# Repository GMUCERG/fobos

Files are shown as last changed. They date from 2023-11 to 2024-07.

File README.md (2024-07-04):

FOBOS
=====

Flexible Open-source workBench fOr Side-channel analysis (FOBOS) is an "acquisition to analysis" solution which includes all necessary software to control the device under test (attack) (DUT), trigger the oscilloscope, obtain the measurements and analyze them using several power analysis techniques.

FOBOS splits the Side Channel Analysis (SCA) setup into a control board, a DUT, and the SCA workstation. The firmware for the control board can be found in the folder `control`. The hardware description language files required to adapt a cryptographic algorithm to a particular FOBOS DUT are in the folder `DUT`. The `hardware` folder on the other hand contains circuit board design files for FOBOS boards such as the FOBOS Shield and several FOBOS DUTs. The `software` folder contains the scripts to run FOBOS. These python scripts run partially on the SCA workstation within a Jupyter notebook and partially on the Pynq DUT. The `docs` folder contains the FOBOS documentation.

Please cite as: 
```bibtex
@inproceedings{fobos3,
author = {Ferrufino, Eduardo and Beckwith, Luke and Abdulgadir, Abubakr and Kaps, Jens-Peter},
title = {{FOBOS} 3: An Open-Source Platform for Side-Channel Analysis and Benchmarking},
year = {2023},
isbn = {9798400702624},
publisher = {Association for Computing Machinery},
address = {New York, NY, USA},
url = {https://doi.org/10.1145/3605769.3623987},
doi = {10.1145/3605769.3623987},
pages = {5--14},
keywords = {hardware security, lightweight cryptography, side-channel analysis, benchmarking},
location = {, Copenhagen, Denmark, },
series = {ASHES '23}
}
```

FOBOS Control Board
-------------------
* `control`
   VHDL sources for configuring the FOBOS Control Boards. Requires Xilinx Vivado 2022.1.
   * `pynqctrl`
     Using a Digilent Inc PYNQ-Z1 or TUL PYNQ-Z2 as control board and either the FOBOS Shield or an oscilloscope for measurements.
   * `ip-repo` 
     Modules used by either control board.

FOBOS DUT
---------
* `dut`
  VHDL sources for FOBOS wrapper and pin assignments to prepare a DUT for instantiating a target algorithm.
  * `fpga_wrapper`
    Source code of the FOBOS wrapper common to all FPGA targets and the constraint files for the supported DUTs.
  * `example_cores`
    Contains implementations of example algorithms required for the tutorials.
 
FOBOS Hardware
--------------
* `hardware`
  Printed Circuit Board design files for FOBOS boards. Requires KiCad.
  * `fobos-shield`
    FOBOS Shield is a data aqcuisition and benchmarking boad that can be attached to the PYNQ-Z1 board.
  * `fobos-shield-Z2`
    FOBOS Shield is a data aqcuisition and benchmarking boad that can be attached to the PYNQ-Z2 board.
  * `fobos-mtc`
    FOBOS Multi Target Connector allows simple connection of DUT boards with PMOD connectors to the FOBOS Shield.
  * `fobos-dut`
    Contains folders for each FOBOS DUT.

FOBOS Software
--------------
* `software`
  FOBOS is controlled by a series of Python 3 scripts. 

  * `foboslib` contains all common FOBOS functions.
  * `notebooks` contains Jupyter notebooks that run within Jupyter Lab on the SCA workstation.
  * `lwc_tools` contains tools to make the GMU LWC Hardware API compatible with FOBOS.
  * `firmware` contains software that runs on FOBOS Control.

Documentation
-------------

* `docs` 
  Contains the sources for the Sphinx based documentation of FOBOS and the makefile to compile it.
  You can also read it at https://cryptography.gmu.edu/documentation/fobos3/index.html
  
License
-------

Copyright 2024 Cryptographic Engineering Research Group (CERG)

Licensed under the Apache License, Version 2.0 (the "License");
you may not use this file except in compliance with the License.
You may obtain a copy of the License at

    http://www.apache.org/licenses/LICENSE-2.0

Unless required by applicable law or agreed to in writing, software
distributed under the License is distributed on an "AS IS" BASIS,
WITHOUT WARRANTIES OR CONDITIONS OF ANY KIND, either express or implied.
See the License for the specific language governing permissions and
limitations under the License.

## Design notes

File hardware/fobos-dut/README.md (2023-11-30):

FOBOS-DUT Boards
=========
  * `dut-artix7-a12t-cpg238`
    FOBOS FBD-A7 DUT with a Xilinx Artix-7 xc7a12tcpg238 device and power measurement circuitry.

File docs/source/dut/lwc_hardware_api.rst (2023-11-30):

.. _dut_fbd-a7-label:

==========================
FOBOS FBD-A7 (Artix7 FPGA)
==========================

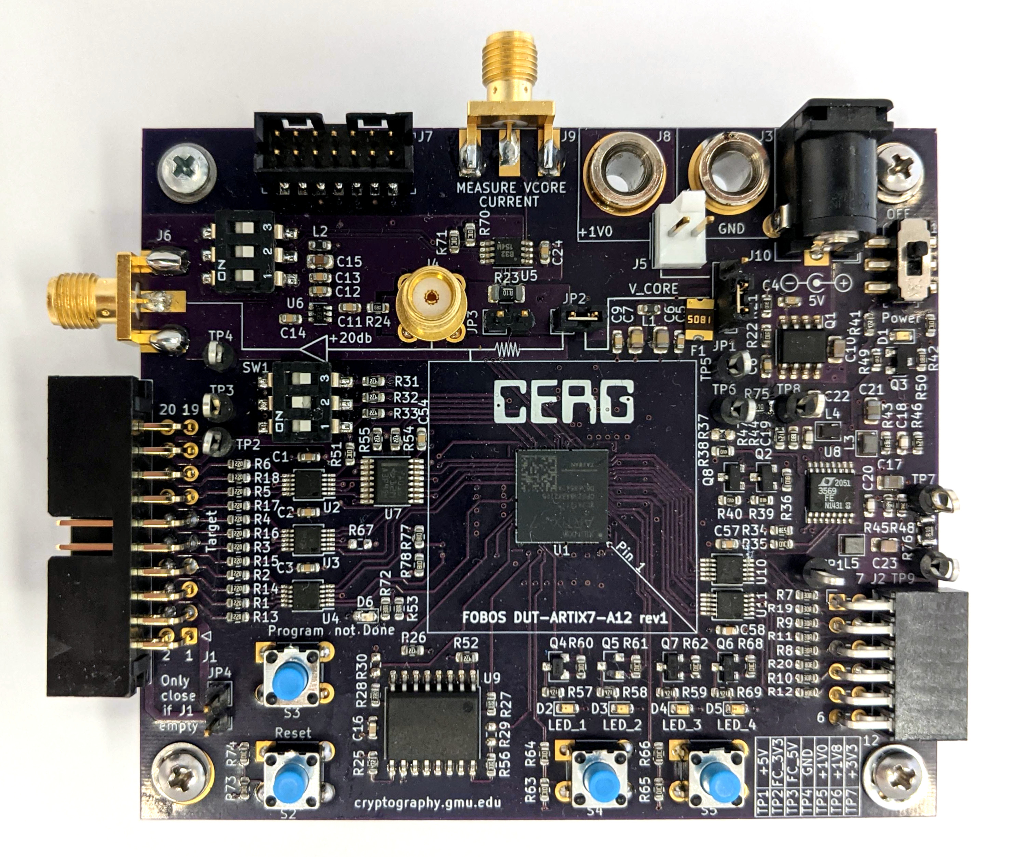
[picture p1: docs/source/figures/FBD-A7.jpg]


   FOBOS FBD-A7 DUT with Xilinx Artix-7-A12 FPGA

Connection to FOBOS Shield control board
----------------------------------------

When using the FOBOS Shield, simply connect the 20pin ribbon cable to the target connector of the FOBOS Shield and the FBD-A7. 
Connect the SMA connector J6 of the FBD-A7 to the Measure connector J10 on the FOBOS Shield or to an oscilloscope for measuring changes in power consumption for SCA measurement.

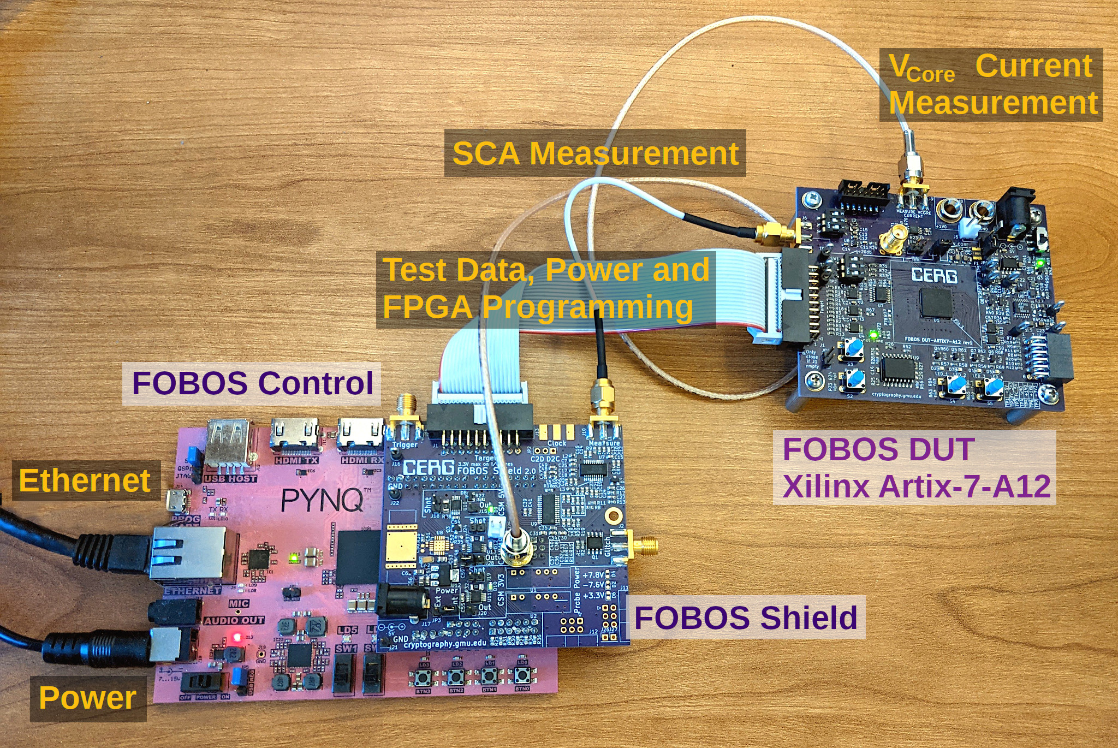
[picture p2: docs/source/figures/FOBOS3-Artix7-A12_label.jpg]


   FODOS 3 Setup with Artix7-A12 DUT

Make sure to set the DUT to FOBOS and DUT interface to INTERFACE_4BIT in your Jupyter notebook using the following commands.
This configures the FOBOS Control to DUT communication.

.. code-block:: py

    ctrl.setDUT(FOBOSCtrl.FOBOS)
    ctrl.setDUTInterface(FOBOSCtrl.INTERFACE_4BIT) 

When compiling the FOBOS wrapper, choose **fbd-a7.xdc** as the constraint file.

Programming the FBD-A7 DUT
--------------------------

The DUT can only be programmed through the JTAG interface as of now. 
Programming the DUT directly from FOBOS Control or from the SPI flash are still being developed.

..
    You can program the DUT using the following commands in your Jupyter notebook:

    .. code-block:: py

        from foboslib.dut import fbd-a7 as DUT
        dut = DUT.DUT()
        dut.setBitFile("crypto.bit")
        dut.program()

Power Measurement
-----------------

To measure the power consumption, connect an SMA cable to the *Measure VCore Current* output J9 of the FBD-A7 and the CMS VAR alternate input J23 on the FOBOS Shield. Make sure that the jumper J28 on FOBOS Shield is pulled, see :numref:`fig_power_circuit`.

.. _fig_FBD-A7_power:
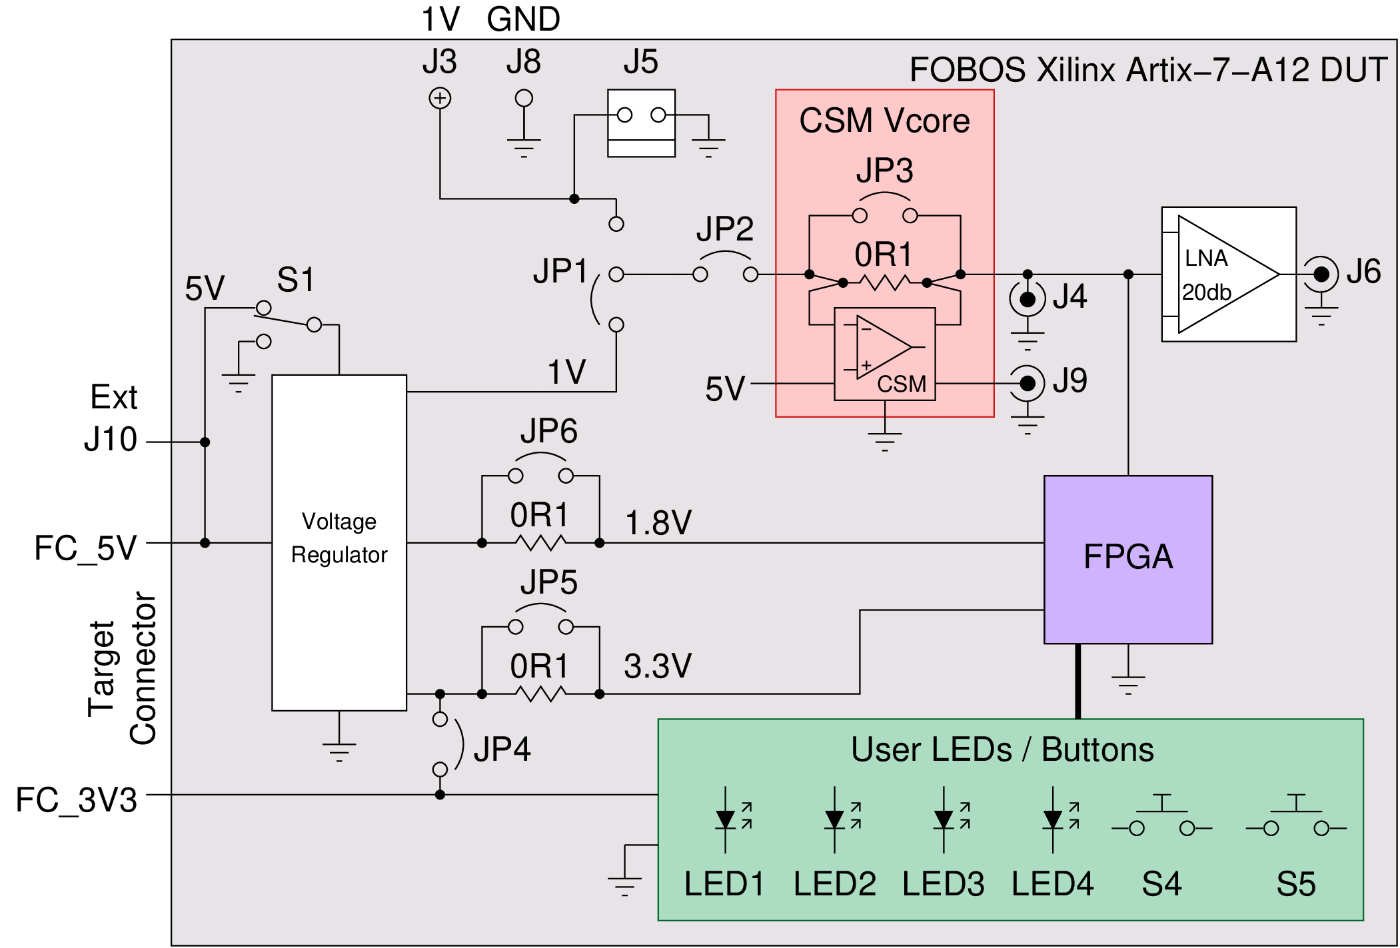
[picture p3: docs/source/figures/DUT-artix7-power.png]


   FBD-A7 Power Block Diagram

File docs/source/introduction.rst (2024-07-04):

Introduction
************
The Flexible Opensource workBench fOr Sidechannel analysis (FOBOS) 
loosely named after the Greek god Phobos (Φóβος), is an "acquisition to analysis" 
solution which includes all necessary software to control the Device Under Test (DUT), 
obtain the measurements and analyze them using several power analysis techniques. 
FOBOS mainly targets FPGAs as DUTs. 
The system is targeted for educational and research purposes.



   FODOS 3 Setup with Artix7-A12 DUT

FOBOS Overview
==============
The main components of the FOBOS 3 platform are as follows:

1. The *SCA Workstation* hosts capture and analysis scripts using a 
   JupyterLab installation. All scripts are written in Python and are 
   commented and easy to modify. In typical system usage, the user runs capture 
   scripts that send test vectors (e.g., key and plaintext) one at a time to 
   the connected control board and receives the results (e.g., ciphertext) 
   and power traces. Analysis scripts can be run on the saved results and traces 
   or optionally executed simultaneously with trace collection.
2. The *control board* receives a test vector from the SCA workstation and forwards 
   it to the DUT. The control board asserts a trigger signal as
   soon as the target board starts operating on the test vector (i.e., running
   the cryptographic function). This signal can trigger an external oscilloscope
   or the internal ADC hosted on the FOBOS Shield. The control board also generates 
   the target clock. The internal ADC can sample changes in the power consumption 
   of the target board at a maximum rate of 100 M Sample/sec. The sampling clock and the target
   clocks are synchronized to achieve high-precision measurements.
3. The *DUT* hosts the cryptographic function that is being evaluated.
   The DUT board is designed (or modified) to allow measurement of the power
   consumption using a shunt resistor or a current probe. We tested the platform 
   using a modified Digilent Nexys 3 board featuring a Xilinx Spartan-6
   FPGA, the NewAE CW305 Artix-7 target board, and our upcoming FOBOS Artix-7-based DUT.

Feature Overview
================

- Runs cryptographic implementations on FPGAs and measures power consumption.
- Provides a simple wrapper for FPGA implementations of cryptographic algorithms 
  according to the CAESAR and LWC Hardware APIs.
- Separate control and DUT boards allowing easy addition of new DUTs.
- Uses commercial over-the-shelf boards when possible to reduce cost.
- Digilent Pynq-Z1 and TUL Pynq-Z2 control boards.
- DUT support includes Digilent Nexys3 board (Xilinx Spartan6), FOBOS FBD-A7 and NewAE CW305
  (Xilinx Artix7 boards).
- Adjustable DUT clock.
- DUT clock synchronized with ADC clock.
- Adjustable trigger signal.
- Supports fast USB3-based oscilloscopes (Picoscope).
- Software to perform Correlation Power Analysis (CPA).
- Leakage assessment using t-test. 

Changelog
=========

**Version 3.0.1**

- Substantial documentation updates and improvements
- Power calibration works again (was working on beta versions of FOBOS 3)
- MTDs of each key byte are now written into a file, they don't have to be guessed from graphs anymore
- Updated fobosTVGen to handle more FIFOs
- XILINX_XRT environment variable on Pynq was not set correctly
- Pynq install script now detects which Pynq board it is running on
- FOBOS can now set fixed amplification on the amplifier of the FOBOS Shield using ADC_hilo
- Improved Makefile for building the Pynq overlay for Pynq-Z1 and Pynq-Z2, and different revisions of the FOBOS Shield

**Version 3**

- Completely new version of FOBOS with major changes
- FOBOS Shield which provides 100 MS/s ADC for SCA measurements and current sense monitors
  for power consumption measurements. This removes the need for an oscilloscope and 
  enables benchmarking of power and energy consumption of the DUT.
- Digilent Pynq-Z1 and TUL Pynq-Z2 control boards provide fast data aquisition and communication with the 
  DUT through 1G Ethernet interface.
- JupyterLab front end to control FOBOS. This also enables remote access.

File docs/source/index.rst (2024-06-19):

.. FOBOS documentation master file, created by
   sphinx-quickstart on Fri Aug 30 16:09:53 2019.
   You can adapt this file completely to your liking, but it should at least
   contain the root `toctree` directive.

Flexible Opensource workBench fOr Side-channel analysis (FOBOS)
***************************************************************

The Flexible Opensource workBench fOr Side-channel analysis FOBOS is a platform to perform side-channel analysis (SCA).
FOBOS uses commercially avilable boards when possible to reduce the cost of building a working SCA setup.
Using FOBOS, power traces can be collected and attacks like Correlation Power Analysis (CPA) can be mounted.
Also, scripts to perform leakage assesment are included.

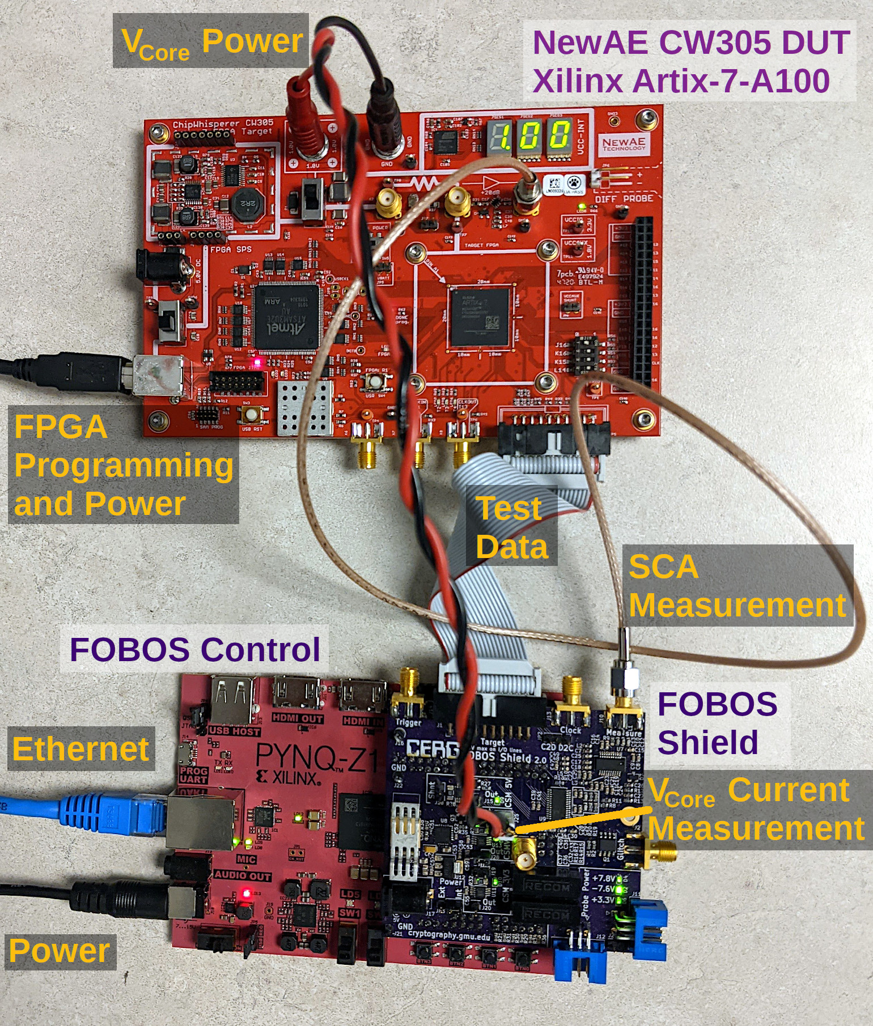
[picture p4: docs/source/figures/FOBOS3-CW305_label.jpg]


   FOBOS 3 Setup with NewAE CW305 DUT

Features
========

- Runs cryptographic implementations on FPGAs and measures power consumption.
- Provides a simple wrapper for FPGA implementations of cryptographic algorithms 
  according to the CAESAR and LWC Hardware APIs.
- Separate control and DUT boards allowing easy addition of new DUTs.
- Uses commercial over-the-shelf boards when possible to reduce cost.
- Digilent Basys3 and Digilent Pynq-Z1 control boards.
- DUT support includes Digilent Nexys3 board (Xilinx Spartan6) and NewAE CW305
  (Xilinx Artix7 boards).
- Adjustable DUT clock.
- DUT clock synchronized with ADC clock.
- Adjustable trigger signal.
- Supports fast USB3-based oscilloscopes (Picoscope).
- Software to perform Correlation Power Analysis (CPA).
- Leakage assessment using t-test. 

.. toctree::
   :maxdepth: 3
   :numbered:
   :hidden:
   
   introduction
   workstation/index
   controller/index
   dut/index
   modules/index
   tvgen/index
   examples/index
   teaching/index
   api/modules
   reference_doc
   license
   bibliography

.. Download Document
    =================
    
    * `FOBOS 3 User Guide <https://cryptography.gmu.edu/download.php?docid=2616>`_ in PDF format, please cite as [`Bibtex <https://cryptography.gmu.edu/bibtex.php?id=2616>`_]
  
Index
=====

* :ref:`genindex`

.. * :ref:`search`

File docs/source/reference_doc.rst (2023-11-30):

API Reference
*************

Here we provide documentation for important classes and methods.

Basys3Ctrl Class (controller)
-----------------------------

.. py:class:: fobos.Basys3Ctrl(self, port, baudRate=115200, dummy=False)
        
        Class to interface with Basys3 controller.

        :param str port: The serial port where the Basys3 board is connected(e.g /dev/ttyUSB1).
        :param int baudRate: Baud rate. Default is 115200.
        :param bool dummy: When set to true, no communication with Basys3 is done.
                           This is to test the software only. Default is False.

        .. py:method:: processData(self, data, outLen)

            Sends data to FOBOS hardware for processing, e.g. encryption
            
            :param str data: The data to be processed. This is a hexadecimal string.
            :rtype (str, str):
            :return: (Status ("00000000" OK | "20000000" TIMOUT) , Result from DUT (i.e. ciphertext))

        .. py:method:: setOutLen(self, outLen)

            set DUT Expected Output Length (result length) in bytes.
             
            :param int outLen: The number of output bytes to be returned by the DUT (e.g 16 for AES-128).
            :rtype int:
            :return: Status.

        .. py:method:: setTriggerWait(self, trigWait)

            Set number of trigger wait cycles

            :param trigWait int: The number of DUT cycles after di_ready goes to 0 to issue the trigger.
            :rtype: int
            :return: Status

        .. py:method::setTriggerLen(self, trigLen)
             
            set the number of DUT cycles to keep the trigger at logic-1.

            :param int trigLen: The number of DUT cycles to keep trigger set.
            :rtype: int
            :return: Status

        .. py:method:: setTriggerMode(self, trigType)
            Set trigger mode.

            :param int: trigType. Possible values (TRG_NORM = 0 | TRG_FULL = 1 | TRG_NORM_CLK = 2 | TRG_FULL_CLK = 3)
            :rtype: int
            :return: Status

         .. py:method:: setTimeToReset(self, dutCycles)
            
            set number of clock cycles after di_ready goes to 0 to reset the DUT.
            
            :param int dutCycles: The number of DUT cycles to reset the DUT.
            :rtype: int
            :return: Status.

        .. py:method:: setTimeout(self, seconds)

            set number of seconds to stop waiting for DUT result.

            :param in seconds: Time in seconds. Range 1-40 seconds.
            :rtype: int
            :return: Status

        .. py:method:: enableTestMode(self)

            Enable test mode. When this mode is enabled, the controller sends test-vectors to its internal dummy DUT.

            :rtype: int
            :return: Status

        .. py:method:: disableTestMode(self)

            Disable test mode. In this mode the ctrl board uses the real DUT. This is the default mode.

            :rtype: int
            :return: Status

        .. py:method:: forceReset(self)

            Reset DUT and clear current communication with DUT.

            :rtype: int
            :return: Status

        .. py:method:: releaseReset(self)

            Release  DUT reset signal

            :rtype: int
            :return: Status

        .. py:method:: setDUTClk(self, clkFreqMhz)
    
            Set DUT clock frequency generated by the control board. Range is between 0.4 MHz - 100 MHz.

            :param float clkFreqMhz: The DUT clock frequency in Mhz.
            :rtype: int
            :return: Status

Scope (Picoscope Class)
-----------------------

.. py:class:: Picoscope(self, sampleResolution=8, preTriggerSamples=0, postTriggerSamples=1000)
        
        A class to interface with the Picoscope oscilloscope.

        .. py:method:: __init__(self, sampleResolution=8, preTriggerSamples=0, postTriggerSamples=1000)

            Open oscilloscope
            
            :param int sampleResolution: The number of bits used to represent each sample. Possible values 8, 12, 14, 15 and 16.
            :param int preTriggerSamples: The number of samples before the trigger to return to the user.
            :param int postTriggerSamples: The number of samples after the trigger to return to the user.

        .. py:method:: setChannel(self, channelName='CHANNEL_A', coupling='DC', rangemv='1V')

            Configure voltage range and coupling for a channel.

            :param str channelName: The name of the oscilloscope channel (CHANNEL_A | CHANNELB).
            :param str coupling: Select DC/AC coupling (DC | AC)
            :param str rangemv: The voltage range for the selected channel (10mV|20mV|50mV|100mV|200mV|500mV|1V|2V|5V|10V|20V)

        .. py:method:: setSamplingInterval(self, samplingIntervalns)

            Sets the sampling interval (time between samples T) in nano seconds. Sampling rate = 1/T.

            :param int samplingInterval: Sampling interval (time between samples T) in nano seconds. Sampling rate = 1/T.

        .. py:method:: setTrigger(self, channelName= 'CHANNEL_A', thresholdmv = 500, direction = 'RISING_EDGE', autoTriggerDelay = 2000)

            Configure trigger channel.

            :param str channelName: The channel to use as a trigger channel (CHANNEL_A | CHANNELB | EXTERNAL).
            :param int thresholdmv: The minimum level of voltage to assert a trigger.
            :param str direction: The trigger signal direction (RISING_EDGE| FALLING_EDGE).
            :param int autoTriggerDelay: Time in milliseconds after which auto trigger occurs (i.e start storing data even if no valid trigger received).

        .. py:method:: setDataBuffers()

            Allocates memory buffers to store oscilloscope data.

ProjectManager Class
--------------------

.. py:class:: ProjectManager()
    
    A class to facilitate organizing and saving results files/data files in automatically created directories. For example, when new capture is performed a directory named attempt-[number] will be created in the capture directory.

    .. py:method:: setWorkSpaceDir(self, workSpaceDir)

        Sets the directory where all data will be saved.

        :param str workSpaceDir: Workspace directory path.

    .. py:method:: setProjName()

        Sets the project name.

        :param str projectName: Project name. A directory will be created in the workspace with the project name.

    .. py:method:: getProjDir()

        Gets the project directory path.

        :return: Full project directory path.

    .. py:method:: getCaptureDir()

        Creates and returns the path of a new directory created in *worksapce/projectName/capture/* the folder will be named *attempt-(number)* for uniqueness.

Nexy3DUT Class
--------------

.. py:class:: Nexys3DUT()

    A class to program Digilent Nexy3 DUT. This class requires that Digilent Adept command line tools (djtgcfg command) is installed.

    .. py:method:: setBitFile(bitFile)

        Sets the bit file name used to program the DUT FPGA.

        :param str bitFile: Full path of the .bit file to program the FPGA.

    .. py:method:: program()

        Programs the FPGA using the bit file specified using he setBitFile method.

CPA Class
---------

.. py:class:: CPA()

    A class to perform Correlation Power Analysis.

    .. py:method:: doCPA(self, measuredPower, hypotheticalPower, numTraces, analysisDir, MTDStride)

        Perform CPA.
    
        :param numpy_array measuredPower: The power measure using the oscilloscope.
        :param numpy_array hypotheticalPower: The hypotheticalPower estimated using the power model.
        :param int numTraces: Number of traces in to be analyzed.
        :param str analysisDir: Full path of the directory to store analysis results.
        :param int MTDStride: The number of traces to add in each step when plotting the MTD graph.
        
DataGenerator Class
------------------------------------------------------

.. py:class:: DataGenerator()

    A class to generate FOBOS-ready test vectors.

        .. py:method:: randTVFile(self, pdiLen, sdiLen, rdiLen, outLen, fileName, numTVs)

            Generate a FOBOS-ready test-vector file.

            :param int pdiLen: The lenght of PDI data (e.g plaintext) in bytes.
            :param int sdiLen: The lenght of SDI data (e.g secret key) in bytes.
            :param int rdiLen: The lenght of RDI data (random data) in bytes.
            :param int outLen: The lenght of expected output (e.g ciphertext) in bytes.
            :param str fileName: The name of the file to store the testvectors.

        .. py:method:: randTestVector(self, pdiLen, sdiLen, rdiLen, outLen)

            Generate a single FOBOS-ready test-vector.

            :param int pdiLen: The lenght of PDI data (e.g plaintext) in bytes.
            :param int sdiLen: The lenght of SDI data (e.g secret key) in bytes.
            :param int rdiLen: The lenght of RDI data (random data) in bytes.
            :param int outLen: The lenght of expected output (e.g ciphertext) in bytes.

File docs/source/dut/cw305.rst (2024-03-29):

.. _dut_cw305-label:

=========================
NewAE CW305 (Artix7 FPGA)
=========================

Connection to FOBOS Shield control board
----------------------------------------

When using the FOBOS Shield, simply connect the 20pin ribbon cable to the target connector of the FOBOS Shield and the CW305. 
Connect an SMA cable to the SMA connector X4 of the CW305 board and to the Measure connector J10 on the FOBOS Shield or to an oscilloscope for measuring changes in power consumption for SCA measurement.

.. _fig_FOBOS-CW305:


   FODOS 3 Setup with NewAE CW305 DUT

Make sure to set the DUT to CW305 and DUT interface to INTERFACE_4BIT in your Jupyter notebook using the following commands.
This configures the FOBOS Control to DUT communication.

.. code-block:: py

    ctrl.setDUT(FOBOSCtrl.CW305)
    ctrl.setDUTInterface(FOBOSCtrl.INTERFACE_4BIT) 

Implementing Cryptographic Algorithms for the CW305-A100 DUT
------------------------------------------------------------

Follow the instructions in :numref:`algorithm-implementation` and use the constraint file ``cw305-a100.xdc``.
Select the following device in Vivado.

.. _tab_FPGA_CW305-A100:
.. table:: FPGA Details of CW305-A100
    :align:   center

    +-----------+------------------+
    | Family    | Artix-7          |
    +-----------+------------------+
    | Package   | ftg256           |
    +-----------+------------------+
    | Speed     | -2               |
    +-----------+------------------+
    | Part      | xc7a100tftg256-2 |
    +-----------+------------------+

When compiling the FOBOS wrapper, choose **cw305.xdc** as the constraint file.

Programming the CW305 DUT
-------------------------

You can program the DUT using the following commands in your Jupyter notebook:

.. code-block:: py

    from foboslib.dut import cw305dut as DUT
    dut = DUT.DUT()
    dut.setBitFile("crypto.bit")
    dut.program()

Power Measurement
-----------------

To measure the power consumption, you have to supply VCC-INT for the CW305 board from the FOBOS Shield. 
Connect the *Molex-Banana* cable to J25 on the Shield and the Banana sockets on the CW305 board as shown in :numref:`fig_FOBOS-CW305`.
Keep the source switch SW1 on the CW305 set to the internal power supply for now and switch on the CW305 board.

Enable the variable power supply on the FOBOS Shield and set it to supply 1.0V using the following command.

.. code-block:: py

    ctrl.pwSetVarOn(1.0)    

You can verify the voltage on this variable power supply with the following command.

.. code-block:: py

    ctrl.pwGetVoltVar()

Then you can change the source switch SW1 on the CW305 for the external power supply.
Verify immediately with the on board Voltage Meter of the CW305 that the Voltage for VCC-INT does not exceed 1.0V.
If it does, remove the banana plugs immediately.

.. warning:: 

    Do not apply a voltage greater than 1.0V to the banana jacks on the NewAE CW305 board or you might break the FPGA.

.. warning:: 

    Use the variable power supply of the FOBOS shield at your own risk! The FOBOS developers, the Cryptographic Engineering Research Group CERG, and George Mason University are not liable if using the variable power supply causes other circuits to fail. 
    FOBOS is provided on an "AS IS" BASIS, WITHOUT WARRANTIES OR CONDITIONS OF ANY KIND, either express or implied, including, without limitation, any warranties or conditions of TITLE, NON-INFRINGEMENT, MERCHANTABILITY, or FITNESS FOR A PARTICULAR PURPOSE.

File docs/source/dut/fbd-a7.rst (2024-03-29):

.. _dut_fbd-a7-label:

==========================
FOBOS FBD-A7 (Artix7 FPGA)
==========================



   FOBOS FBD-A7 DUT with Xilinx Artix-7-A12 FPGA

Connection to FOBOS Shield control board
----------------------------------------

When using the FOBOS Shield, simply connect the 20pin ribbon cable to the target connector of the FOBOS Shield and the FBD-A7. 
Connect an SMA cable to the SMA connector J6 of the FBD-A7 and to the Measure connector J10 on the FOBOS Shield or to an oscilloscope for measuring changes in power consumption for SCA measurement.



   FODOS 3 Setup with Artix7-A12 DUT

Make sure to set the DUT to FOBOS and DUT interface to INTERFACE_4BIT in your Jupyter notebook using the following commands.
This configures the FOBOS Control to DUT communication.

.. code-block:: py

    ctrl.setDUT(FOBOSCtrl.FOBOS)
    ctrl.setDUTInterface(FOBOSCtrl.INTERFACE_4BIT) 

Implementing Cryptographic Algorithms for the FBD-A7 DUT
--------------------------------------------------------

Follow the instructions in :numref:`algorithm-implementation` and use the constraint file ``fbd-a7.xdc``.
Select the following device in Vivado.

.. _tab_FPGA_FBD-A7:
.. table:: FPGA Details of FBD-A7
    :align:   center

    +-----------+------------------+
    | Family    | Artix-7          |
    +-----------+------------------+
    | Package   | cpg238           |
    +-----------+------------------+
    | Speed     | -1               |
    +-----------+------------------+
    | Part      | xc7a12tcpg238-1  |
    +-----------+------------------+

Programming the FBD-A7 DUT
--------------------------

The DUT can only be programmed through the JTAG interface as of now. 
The capability to program the DUT directly from FOBOS Control or from the SPI flash is still being developed.

..
    You can program the DUT using the following commands in your Jupyter notebook:

    .. code-block:: py

        from foboslib.dut import fbd-a7 as DUT
        dut = DUT.DUT()
        dut.setBitFile("crypto.bit")
        dut.program()

Power Measurement
-----------------

To measure the power consumption, connect an SMA cable to the *Measure VCore Current* output J9 of the FBD-A7 and the CMS VAR alternate input J23 on the FOBOS Shield. Make sure that the jumper J28 on FOBOS Shield is pulled, see :numref:`fig_power_circuit`.

.. _fig_FBD-A7_power:


   FBD-A7 Power Block Diagram

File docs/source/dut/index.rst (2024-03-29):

.. _dut-label:

*********
FOBOS DUT
*********

A DUT (Design Under Test) board must be connected to the control board to run SCA.

.. _dut-board:
===============
Setup DUT Board
===============

This section describes how to connect the supported DUTs to FOBOS Control and how to modify the DUT Boards if needed.
FOBOS supports the following boards as DUT:

.. toctree::
   :maxdepth: 1
   
   fbd-a7
   nexys3
   cw305

===================
FOBOS DUT Interface
===================

This section describes how to interface a cryptographic hardware implementation with FOBOS. As part of FOBOS, we provide a wrapper for implementations that follow a simple AXI stream protocol interface such as the GMU LWC Hardware API interface as described in :numref:`lwc_hw_api`.

.. toctree::
   :maxdepth: 1

   fobos_wrapper
   gmu_lwc_api

.. _algorithm-implementation:
=================================
Example Algorithm Implementations
=================================

This section describes how to compile the provided example *AES* for use with FOBOS, as well as a GMU LWC Hardware API compatible implementation of *ASCON* from the Ascon Team, and the *dummy DUT* that we provide. The dummy DUT is a great starting point for making your own hardware implementation of a cryptographic algorithm compatible with FOBOS.

.. toctree::
   :maxdepth: 1

   AES_example
   ASCON_example
   dut_development

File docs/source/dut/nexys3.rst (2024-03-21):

.. _dut_nexys3-label:

===============================
Digilent Nexy3 (Spartan 6 FPGA)
===============================

.. warning:: 

    This still needs to be described! The text below is a space holder!

Connection to FOBOS Shield control board
----------------------------------------

The PMOD ports on both boards are used to transfer data. The ports should be connected as follows

- Basys3 JA -> Nexys3 JC
- Basys3 JXADC -> Nexys3 JD

The connector must connect each pin to its corresponding pin in the other board. The GND of the two
ports must be connected, However, the Vcc SHOULD NOT be connected.

The pin mapping of the Nexys3 DUT is as follows: ::

    #JC
    #+----------+----------+----------+----------+
    #|          |  din3    |  do_ready|  rst     |
    #|          |          |          |          |
    #+----------+----------+----------+----------+
    #|  din0    |  din2    |  din1    |  do_valid|
    #|          |          |          |          |
    #+----------+----------+----------+----------+

    #JD
    #+----------+----------+----------+----------+
    #|  dout1   |  dout3   |  di_ready|  clk     |
    #|          |          |          |          |
    #+----------+----------+----------+----------+
    #|  dout0   |  dout2   |  di_valid|          |
    #|          |          |          |          |
    #+----------+----------+----------+----------+

The pin mapping in the Basys3 control board is as follows: ::

    #JA
    #+----------+----------+----------+----------+
    #|          |  din3    |  do_ready|  rst |
    #|  G2      |  J2      |  L2      |  J1      |
    #+----------+----------+----------+----------+
    #|  din0    |  din2    |  din1    |  do_valid|
    #|  G3      |  H2      |  K2      |  H1      |
    #+----------+----------+----------+----------+

    #JXADC
    #+----------+----------+----------+----------+
    #|  dout1   |  dout3   |  di_ready|  dut_clk     |
    #|  N2      |  M2      |  L3      |  J3      |
    #+----------+----------+----------+----------+
    #|  dout0   |  dout2   |  di_valid|          |
    #|  N1      |  M1      |  M3      |  K3      |
    #+----------+----------+----------+----------+

Board modification
------------------

- To make perfoming SCA attacks easier, all capacitors on the FPGA core voltage rail have been removed.
- The board is modified to be able to access the FPGA core voltage rail.
- To measere power, an inductive power porbe may be used (e.g. Tektronix CT-1).

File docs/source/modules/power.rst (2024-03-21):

.. _power-label:

Power Module
************

The power module requires the FOBOS Shield. It contains three power supplies:

- Fixed, unregulated 5V power supply (FC_5V), up to 1A
- Fixed, regulated 3.3V power supply (FC_3V3), up to 800mA
- Variable supply (FC_VAR), programmable from 0.9V to 3.5V in 0.05V increments, up to 1A

The circuit of these power supplies is shown in (:numref:`fig_power_circuit`).

.. _fig_power_circuit:
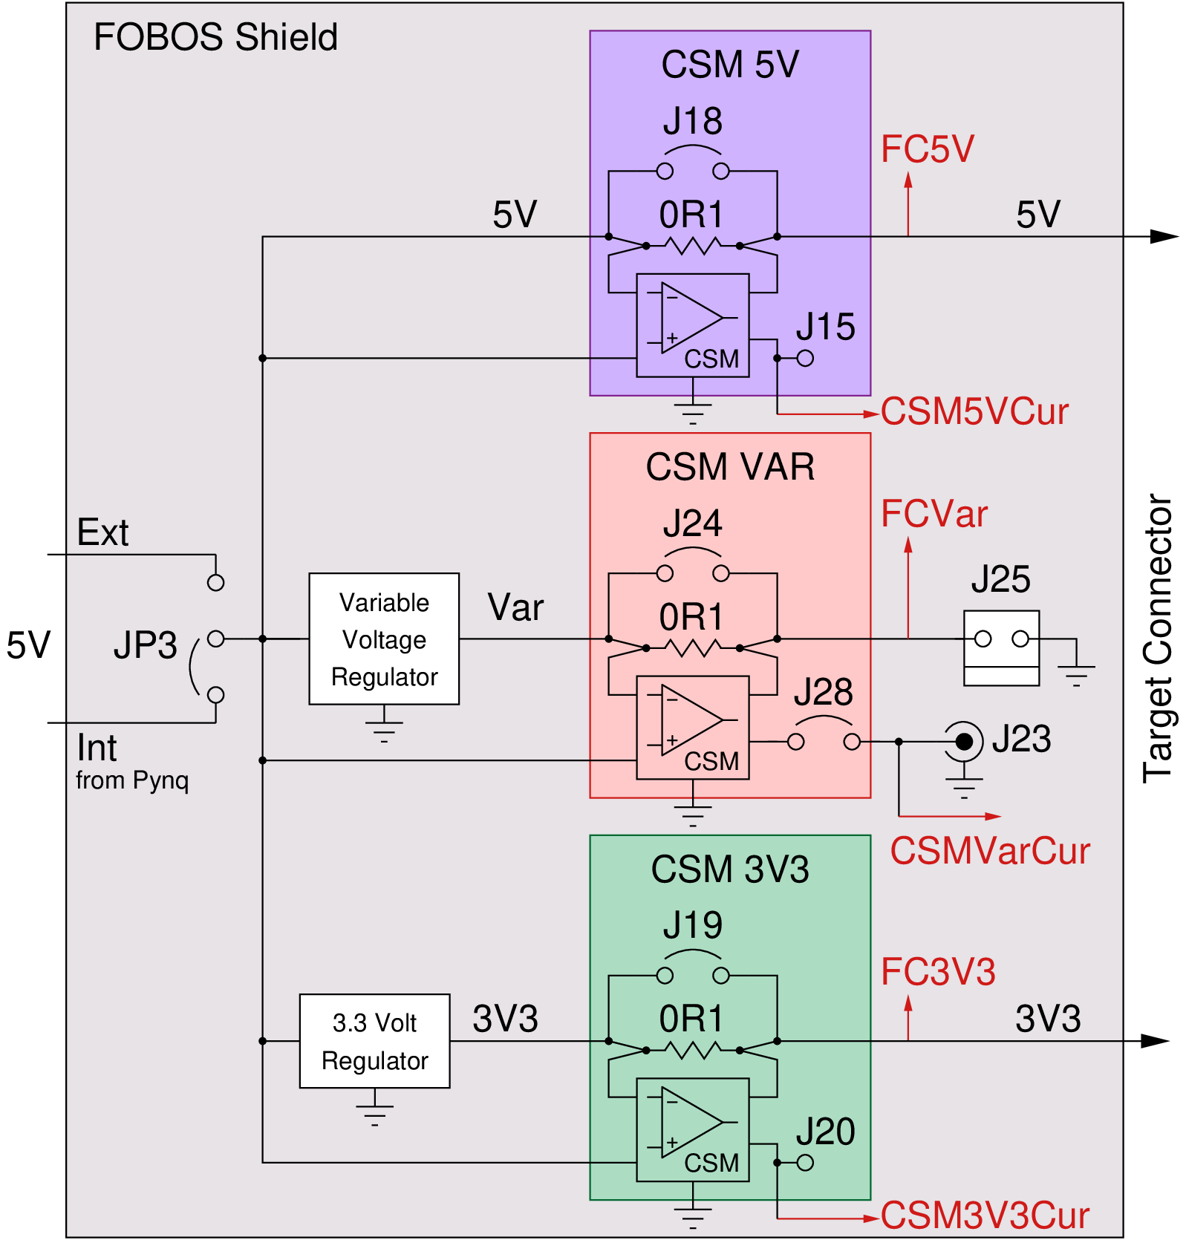
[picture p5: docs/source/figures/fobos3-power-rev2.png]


   Block Diagram of FOBOS Shield Power Circuitry

.. _power_pynq-label:

Powering Pynq and FOBOS Shield
==============================

The Pynq equipped with the FOBOS Shield has to be powered with a power supply, not through the USB port. This combination will 
draw more power than the Pynq's USB port can provide. There are two options to provide
this power:

#.  External power for the Pynq

    -   In this configuration, the external power supply powers both, the Pynq and the FOBOS Shield power module.
    -   Connect a 7V-15V, 2A-3A power supply to the Pynq to the power jack (J18) of the Pynq-Z1.  
        The supply must use a center-positive 2.1mm barrel plug.
    -   Set the jumper JP5 on the Pynq-Z1 to "REG". 
    -   Set the jumper JP3 on the FOBOS Shield to "Int".

    .. warning:: 

        In this configuration, not more than a total of 1A should be drawn across all three power 
        supplies of the shield or the 5V regulator of the Pynq will be overloaded.

#.  External power of the FOBOS Shield

    -   In this configuration, the external power supply powers only the FOBOS Shield power module.
    -   Connect a **well regulated** 5V, 2A-3A power supply to the power jack (J17) of FOBOS Shield.  
        The supply must use a center-positive 2.1mm barrel plug.
    -   Set the jumper JP3 on the FOBOS Shield to "Int".

    .. warning::

        In this configuration, the 5V power supply (FC_5V) is not regulated and the actual voltage 
        depends solely on the external supply.

Power Module Specifications
============================

The `Xilinx XADC <https://docs.xilinx.com/r/en-US/ug480_7Series_XADC/XADC-Overview>`_ on the Pynq board is used to sample from the voltage and current supplies. The XADC has a precision of 12-bits and can sample at up to 1 MSample/s, however in this design the XADC is used to measure seven channels. Thus the effective sampling rate for any individial channel is ~143 KSample/s.

If a higher sample rate is desired, it is possible to use an external oscilloscope to measure the current through the variable voltage supply. To do so, simply close the J28 jumper and connect the oscilloscope to the J23 BNC connector. This enables direct measurement of the CSM voltage which can be used to calculate the current being used.

There is a script for calibrating the voltage and current measurements, which is described in :numref:`power-calibration`.

Using the Variable Power Supply
===============================

The variably power supply can be programmed to deliver voltages from 0.9V to 3.5V in 0.05V increments. The following commands set the voltage and switches the power supply on, changes the voltage to a new value, and then switches the power supply off again.

.. code-block:: py

    ctrl.pwSetVarOn(1.0)    
    ctrl.pwOutVarSet(1.15)
    ctrl.pwSetVarOff()    

Measuring Power Supply Voltage
==============================

FOBOS uses the XADC of the Zynq SOC on the Pynq to measure the voltages of the three power supplies. 
The instantaneous voltage for any power supply can be accessed with the following commands:

.. code-block:: py

    ctrl.pwGetVolt5v()
    ctrl.pwGetVoltVar()
    ctrl.pwGetVolt3v3()

Measuring Power Supply Current
==============================

The power consumed by a device can be computed from the current *I* that it draws and
its supply voltage *V* as :math:`P = I \cdot V`. The energy it 
consumes for executing a particular task is the integral of *P* over the run time.
FOBOS measures both, the current that gets drawn from each power supply line and 
the voltage that is actually supplied.

The current is measured by sensing the voltage drop across a 0.1 :math:`\Omega`
shunt resistor *R*.
The shunt resistor could be placed between the voltage source and the device
or between the device and ground called high-side and low-side current sensing
respectively. We opted for high-side current sensing (:numref:`fig_power_circuit`)
as it eliminates the problems associated with multiple ground paths. 
The drawback of high-side sensing is the higher common-mode voltage which is the
average voltage before and after the shunt. 

The shunt resistor should be very small as to not have a large influence on 
the supply voltage, however that means that voltage drop across the shunt will
also be very small. Therefore, it has to be amplified before it can be measured by 
an analog to digital converter (ADC). Furthermore, the low input resistance
of ADCs makes a direct measurement unfeasible.  
Hence, we use a current-shunt monitor (CSM), i.e. the INA225 from Texas Instruments.
It has a programmable gain setting of 25, 50, 100, and 200, a buffered output so that it
can drive an ADC input, a bandwidth of 125 kHz, and supports high common-mode voltages.

The formula for the resolution of the ADC is shown in :eq:`eq_adcres`. The maximum input voltage
to the XADC (:math:`V_{CSMmax}`) via FOBOS Shield is 5V and its resolution is 12 bits. 

.. math::
    :label: eq_adcres

    V_{res}=\frac{V_{CSMmax}}{2^{ADCbits}} = \frac{5\,\mathrm{V}}{2^{12}\,\mathrm{bits}} = 1.22\,\mathrm{mV}

The voltage applied to the ADC depends on the voltage drop :math:`V_S` across the shunt resistor
:math:`R_S` and the gain of the CSM :math:`\delta_{CSM}`. This relationship is expressed in :eq:`eq_csm`.

.. math::
    :label: eq_csm

    V_{CSM} = V_S \cdot \delta_{CSM} = R_S \cdot I \cdot \delta_{CSM}

We are using a :math:`0.1\,\Omega` resistor for :math:`R_S` and achieve for a gain factor of 25 a resolution of

.. math::

    I_{res} = \frac{V_{res}}{R_S \cdot \delta_{CSM}} = \frac{1.22\,\mathrm{mV}}{0.1\,\Omega \cdot 25} = 488\,\mathrm{\mu A}

and can measure a current of at most

.. math::

    I_{max} = \frac{V_{CSMmax}}{R_S \cdot \delta_{CSM}} = \frac{5\,\mathrm{V}}{0.1\,\Omega \cdot 25} = 2\,\mathrm{A}.

At the maximum gain of 200 the resolution is :math:`61.0\,\mathrm{\mu A}` and the maximum current is :math:`250.0\,mA`.

FOBOS uses the XADC of the Zynq SOC on the Pynq to measure the voltages from the CSMs of the three power supplies and 
converts them, while taking the gain factors into account, to the corresponding currents.
The instantaneous current can be accessed with the following commands:

.. important:: 
    In order to be able to measure the current of the variable power supply (FC_VAR), the jumper J28 on the 
    FOBOS Shield has to be closed (see :numref:`fig_power_circuit`).

.. code-block:: py

    ctrl.pwGetCurr5v()
    ctrl.pwGetCurrVar()
    ctrl.pwGetCurr3v3()

The gain of the CSMs is set to 25 by default. If a larger gain is required, it can be changed for each CSM separately using
the following commands. The *Value* can be one of 25, 50, 100, 200.

.. code-block:: py

    ctrl.pwSetGain5v()
    ctrl.pwSetGainVar()
    ctrl.pwSetGain3v3()

The current value of the CSM gain can be queried using these commands:

.. code-block:: py

    ctrl.pwGetGain5v()
    ctrl.pwGetGainVar()
    ctrl.pwGetGain3v3()

Hardware and Software Trigger
=============================

FOBOS is capable to determine the maximum and average current consumed and voltage supplied to the 
DUT during a specified time period.

The *software trigger* can be used to start and stop this time period using the following Python 
commands:

.. code-block:: py

    ctrl.pwSetSwTrig()         # starts the measurement
    ctrl.pwCheckSwTrigStatus() # checks if software trigger was active
    ctrl.pwUnsetSwTrig()       # stops the measurement NOT IMPLEMENTED! 

This measurement window can be easily synchronized with the operation of the DUT. 
When the *hardware trigger* is enabled the measurement is automatically started when the DUT 
processes data and stopped when the DUT is done.

.. code-block:: py

    ctrl.pwSetHwTrig()         # enabled she hardware trigger to start the measurement
    ctrl.pwCheckHwTrigStatus() # checks if the hardware trigger has fired
    ctrl.pwUnsetHwTrig()       # disables the hardware trigger NOT IMPLEMENTED! 

If a trigger is currently active, the average values will not be steady. To check if the power module is actively measuring averages due to a trigger, the following command can be used:

.. code-block:: py

    ctrl.pwCheckBusy() # returns 1 if power module is busy

If the internal registers used to calculated the average current or voltage overflow due to the number of samples measured, a flag will be set which can be accessed using the following command:

.. code-block:: py
    
    ctrl.pwCheckOverflow() # returns 1 if average registers overflowed

After a trace has been completed, the number of samples taken by the XADC can be read using the following command:

.. code-block:: py

    ctrl.pwGetMeasCount() # return the number of samples taken by the XADC during the last trigger

Average and Maximum Voltages and Currents
=========================================

After a trigger has been active, the average and maximum voltages and currents can be read using the following commands:

.. code-block:: py

    ctrl.pwGetMaxVolt5v()
    ctrl.pwGetMaxVoltVar()
    ctrl.pwGetMaxVolt3v3()

    ctrl.pwGetAvgVolt5v()
    ctrl.pwGetAvgVoltVar()
    ctrl.pwGetAvgVolt3v3()

    ctrl.pwGetMaxCurr5v()
    ctrl.pwGetMaxCurrVar()
    ctrl.pwGetMaxCurr3v3()

    ctrl.pwGetAvgCurr5v()
    ctrl.pwGetAvgCurrVar()
    ctrl.pwGetAvgCurr3v3()

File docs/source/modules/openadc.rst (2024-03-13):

.. _openADC-label:

Open ADC Module
***************

The FOBOS3 shield includes an analog-to-digital converter (ADC) used to convert power measurements to digital traces.
This ADC is based on OpenADC and its parameters are listed below.

+------------------------+---------------+
| Paramter               | Value         |
+========================+===============+
| bandwidth              | 40MHz         |
+------------------------+---------------+
| resolution             | 10 bits       |
+------------------------+---------------+
| maximum trace size     | 128 K samples |
+------------------------+---------------+

The ADC reads power measurement from the **measurement** SMA input on the FOBOS3 shield. The maximum trace length is 128 K samples in the current version.
A **trigger** pin is also provided to signal to the ADC when to start capturing the trace.
Once the ADC is armed, it waits for the positive edge of the trigger signal. Once the edge is detected,
the ADC starts to store the **samples_per_trace** samples which are transfered to the PYNQ board's memory.

A pre-amplifier is used to amplify the measured signal at the input of the ADC.
This pre-amplifier has a configurable gain that ranges from 0-60 which can be set from software.
The ADC gain can also has a configurable high/low setting.

Usage example and API
---------------------

API methods:

+------------------------------------------------+----------------------------------------------------------------------+
| Method                                         | Description                                                          |
+================================================+======================================================================+
| ctrl.setSamplingFrequency(SAMPLING_FRQUENCY)   | Sampling frequency range is 1-100 MHz                                |
+------------------------------------------------+----------------------------------------------------------------------+
| ctrl.setADCGain(ADC_GAIN)                      | ADC gain range is 0-60                                               |
+------------------------------------------------+----------------------------------------------------------------------+
| ctrl.setADCHiLo(ADC_HILO)                      | Sets high or low gain. Can be 0 or 1                                 |
+------------------------------------------------+----------------------------------------------------------------------+
| ctrl.setSamplesPerTrace(SAMPLES_PER_TRACE)     | Samples collected after trigger. 4 - 128 K. Must be a multiple of 4  |
+------------------------+-----------------------+----------------------------------------------------------------------+

Example:

The example below shows basic usage of the ADC to collect a set of traces.

.. code-block:: python

    import foboslib as fb
    from foboslib.capture.ctrl.pynqctrl import PYNQCtrl
    from foboslib.common.projmgr import ProjectManager
    
    # Initialize DUT, IO files here ++

    # ++++++++++++++++++++++++++++++++

    NUM_TRACES         = 100                   # number of traces to collect
    
    #Acquistion/scope configuration
    SAMPLING_FRQUENCY  = 50                    # sampling frequency of the Oscilloscope in Msps [default: 50][range: 1 - 100]
    SAMPLES_PER_TRACE  = 1000                  # number of sample in one trace [range: 1 - 2^17]
    ADC_GAIN           = 60                    # amplification of ADC input signal [default: 40][range: 0 - 60]
    ADC_HILO           = 1

    ctrl = PYNQCtrl(<IP>, <PORT>)              # connect to control board

    # configure DUT, trigger etc here
    
    # ADC settings
    ctrl.setSamplingFrequency(SAMPLING_FRQUENCY)
    ctrl.setADCGain(ADC_GAIN)
    ctrl.setADCHiLo(ADC_HILO)
    ctrl.setSamplesPerTrace(SAMPLES_PER_TRACE)

    # Trace collection
    for i in range(NUM_TRACES):
        data = tvFile.readline()
        status, result, trace = ctrl.processData2(data)
        cipherFile.write(result + "\n")
        np.save(traceFile, trace)
    print('Data acquisition complete.')

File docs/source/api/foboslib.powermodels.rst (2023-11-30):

foboslib.powermodels package
============================

Submodules
----------

foboslib.powermodels.AESFirstLast module
----------------------------------------

.. automodule:: foboslib.powermodels.AESFirstLast
   :members:
   :undoc-members:
   :show-inheritance:

foboslib.powermodels.utils module
---------------------------------

.. automodule:: foboslib.powermodels.utils
   :members:
   :undoc-members:
   :show-inheritance:

Module contents
---------------

.. automodule:: foboslib.powermodels
   :members:
   :undoc-members:
   :show-inheritance:

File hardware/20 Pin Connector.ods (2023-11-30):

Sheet: Sheet1
FOBOS Target Connector Pin Number | FOBOS Name / Schematic Label | Chip Whisperer Name | Half Duplex DUT function | Direction* | Alt? | Alt function Artix 7 | Alt function Cyclone 10 | Direction*
1 | FC_5V | CW_5V | POWER | in | NO | - |  | -
2 | GND | GND | POWER | in | NO | - |  | - | * All direction is denoted from the perspective of the DUT FPGA
3 | FC_3V3 | CW_3V3 | POWER | in | NO | - |  | - | ** When PROG is asserted, alt functions are enabled
4 | FD2C_CLK | CW_HS1 | UNUSED | out | NO | - |  | -
5 | FC_RST | CW_RST | d_rst | in | NO | - |  | -
6 | FC2D_CLK | CW_HS2 | clock_c2d | in | NO | - |  | - | CLK_C2D max 100 MHz
7 | FC_IO | CW_MISO | FS_IO=0 Dir = i, FS_IO=1 Dir = o | in | NO | - |  | - | FC_IO sets the direction of the i/o signals
8 | FD_VREF | CW_VREF | POWER | out | NO | - |  | - | FC stands for FOBOS Control
9 | FD_TF | CW_MOSI | UNUSED | out | YES | done | CONF_DONE | out | FD stands for FOBOS Device Under Test (DUT)
10 | FC_DIO0 | CW_TARG1 | dio[0] | i/o | YES | clk | D_CLK | in | each time FC or FD indicates the source of the signal
11 | (Ready) FC2D_HS | CW_SCK | handshake_c2d | in | NO | - |  | - | HS stands for HandShake signals (Valid/Ready)
12 | FC_DIO1 | CW_TARG2 | dio[1] | i/o | YES | din | DATA[0] | in | FS_DIO is a 4 bit bidirectional data bus
13 | (Valid) FD2C_HS | CW_PDIC | handshake_d2c | out | NO | - |  | - | FD_TF is 0 when DUT is busy, else 1 on some DUTs
14 | FC_DIO2 | CW_TARG3 | dio[2] | i/o | YES | program_b | nCONFIG | in
15 | (Aux) FC_PROG | CW_PDID | UNUSED | in | NO | - |  | -
16 | FC_DIO3 | CW_TARG4 | dio[3] | i/o | YES | init_b | nSTATUS | out
17 | GND | GND | POWER | in | NO | - |  | -
18 | FC_3V3 | CW_3V3 | POWER | in | NO | - |  | -
19 | GND | GND | POWER | in | NO | - |  | -
20 | FC_5V | CW_5V | POWER | in | NO | - |  | -

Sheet: CW_20_Pinout
Number | Name | Dir | Description
1 | +VUSB (5V) | O | Not Connected on ChipWhisperer-Lite.
2 | GND | O | System GND.
3 | +3.3V | O | +3.3V to Target Device, can be turned off, 200mA available.
4 | FPGA-HS1 | I/O | High Speed Input (normally clock in).
5 | PROG-RESET | I/O | Target RESET Pin (AVR Programmer).
6 | FPGA-HS2 | I/O | High Speed Output (normally clock or glitch out).
7 | PROG-MISO | I/O | SPI input: MISO (for SPI + AVR Programmer).
8 | VTarget | I | Drive this pin with desired I/O voltage in range 1.5V-5V.
9 | PROG-MOSI | I/O | SPI output: MOSI (for SPI + AVR Programmer).
10 | FPGA-TARG1 | I/O | TargetIO Pin 1 - Usually UART TX or RX.
11 | PROG-SCK | I/O | SPI output: SCK (for SPI + AVR Programmer).
12 | FPGA-TARG2 | I/O | TargetIO Pin 2 - Usually UART RX or TX.
13 | PROG-PDIC | I/O | PDI Programming Clock (XMEGA Programmer), or CS pin (SPI).
14 | FPGA-TARG3 | I/O | TargetIO Pin 3 - Usually bidirectional IO for smartcard.
15 | PROG-PDID | I/O | PDI Programming Data (XMEGA Programmer).
16 | FPGA-TARG4 | I/O | TargetIO Pin 4 - Usually trigger input.
17 | GND | O
18 | +3.3V | O
19 | GND | O
20 | +VUSB (5V) | O | Not Connected on ChipWhisperer-Lite.

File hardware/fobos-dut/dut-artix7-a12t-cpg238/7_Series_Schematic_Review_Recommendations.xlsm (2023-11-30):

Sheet: Project Info
 | SCHEMATIC REVIEW RECOMMENDATIONS
XMP277 (v1.10) March 30, 2020
Company | GMU CERG
Customer Project | DUT-ARTIX7-A12T-CPG238
Customer Contact | Jans Kaps
Review Date | mm-dd-yyyy
Xilinx Reviewers | na
PURPOSE | Conducting schematic reviews to ensure an FPGA design is optimally configured for first-time success is a difficult task. Part of the challenge stems from the many different sources of information that the designer needs to reference, including the device data sheet, family user guide, answer records, errata, etc., as well as the software design tools. This recommendations document provides a template for performing and recording the results of a schematic review.
DISCLAIMER | NOTICE OF DISCLAIMER: The information disclosed to you hereunder (the “Materials”) is provided solely for the selection and use of Xilinx products. To the maximum extent permitted by applicable law: (1) Materials are made available "AS IS" and with all faults, Xilinx hereby DISCLAIMS ALL WARRANTIES AND CONDITIONS, EXPRESS, IMPLIED, OR STATUTORY, INCLUDING BUT NOT LIMITED TO WARRANTIES OF MERCHANTABILITY, NON-INFRINGEMENT, OR FITNESS FOR ANY PARTICULAR PURPOSE; and (2) Xilinx shall not be liable (whether in contract or tort, including negligence, or under any other theory of liability) for any loss or damage of any kind or nature related to, arising under, or in connection with, the Materials (including your use of the Materials), including for any direct, indirect, special, incidental, or consequential loss or damage (including loss of data, profits, goodwill, or any type of loss or damage suffered as a result of any action brought by a third party) even if such damage or loss was reasonably foreseeable or Xilinx had been advised of the possibility of the same. Xilinx assumes no obligation to correct any errors contained in the Materials or to notify you of updates to the Materials or to product specifications. You may not reproduce, modify, distribute, or publicly display the Materials without prior written consent. Certain products are subject to the terms and conditions of Xilinx’s limited warranty, please refer to Xilinx’s Terms of Sale which can be viewed at at www.xilinx.com/legal.htm#tos; IP cor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
COPYRIGHT | © Copyright 2012–2020 Xilinx, Inc. Xilinx, the Xilinx logo, Artix, ISE, Kintex, Spartan, Virtex, Vivado, Zynq, and other designated brands included herein are trademarks of Xilinx in the United States and other countries. The PowerPC name and logo are registered trademarks of IBM Corp., and used under license. All other trademarks are the property of their respective owners.

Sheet: Instructions
General Instructions to the Reviewer
! | Macros must be enabled for full functionality.
1. | This spreadsheet is intended to provide a list of what has been checked (and what has not been checked) during a customer schematic review. It is not intended to be a comprehensive checklist.
2. | The Project Info page gives an overview of the schematic that is being reviewed and the person(s) performing the review. It also contains the Purpose and Disclaimer paragraphs.
3. | The Checklist pages contain some of the more common items that should be checked. In some cases, these items might not apply to a specific schematic review and can be deleted. In other cases, there might be additional items that need to be checked. In that case, the user can add a line to the end of the worksheet.
4. | In several cells, there are Xilinx recommendations containing question marks (e.g., ? of ?? mF cap ). The question marks are intended to remind the user to replace the '?' with the appropriate value. In this example, the number of caps and the value of those caps need to be recorded.
5. | The Checklist pages are intended to collect information for a single FPGA and its supporting device (such as a configuration PROM). At the top of the Checklist page, the device part number and reference designator need to be recorded. If there are multiple devices, a workbook should be created for each device.
6. | Each cell in the Status column has a pull-down menu with the color-coded selections OK, CHECK, and PROBLEM. The Status column allows the customer to quickly see the results of the schematic review. · OK: The item receives reviewer approval. · CHECK: The reviewer does not have sufficient information to determine if the item is OK or poses a PROBLEM. The designer must research the item and provide additional information. · PROBLEM: There is an issue with the item. PROBLEM flags the item for the designer, who needs to research the issue and find a solution. · Not Checked: The item has not been checked and might require additional attention. · N/A: The item is not applicable to this device or design.
7. | The Actual Implementation column can be used to provide additional clarification. This information is especially important if the item is tagged with CHECK or PROBLEM.

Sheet: Checklist(1)
Checklist(1)
Items on the page are related to the following Device and Configuration Mode
Family | Artix-7
Device | 7A12T
Package | CP238
Configuration Mode | Slave Serial (and JTAG) (Mode 111)
Configuration Frequency (MHz) | 10.000
Reference Designator | U1
Power Distribution System
Item | Xilinx Recommendation | Actual Implementation | Status | Additional Information | Comments
VCCINT | 1.0V, 0 of 680 uF, 0 of 330 uF, 1 of 100 uF,0 of 47 uF, 2 of 4.7 uF, 3 of 0.47 uF | Followed recommendation | OK | 1.0V except for the following: - Artix-7, Kintex-7, and Zynq-7000 parts in the -2LE speed grade can operate with VCCINT=1.0V or 0.9V. - Artix-7 parts in the -1LI speed grade operate at VCCINT=0.95V. - Kintex-7 and Zynq-7000 parts in the -2LI speed grade operate at VCCINT=0.95V. - Zynq-7000 parts in the -1LI speed grade can operate with VCCINT=1.0V or 0.95V.
VCCBRAM | 1.0V, 0 of 100 uF, 1 of 47 uF, 0 of 4.7 uF , 1 of 0.47 uF | Followed recommendation | OK | 1.0V except for the following: - Kintex-7 parts in the -2LE speed grade can operate with VCCBRAM=1.0V or 0.9V. - Artix-7 parts in the -1LI speed grade operate with VCCBRAM=0.95V. - Kintex-7 and Zynq-7000 parts in the -2LI speed grade operate at VCCBRAM=0.95V. - Zynq-7000 parts in the -1LI speed grade can operate with VCCBRAM=1.0V or 0.95V.
VCCAUX | 1.8V, 1 of 47 uF, 1 of 4.7 uF, 2 of 0.47 uF | Followed recommendation | OK
VCCAUX_IO_G# | Does not apply to selected family or device.
VCCO Bank 0 | 1.5V - 3.3V, 1 of 47uF | 3.3 | OK | VCCO_0 supports 1.5V - 3.3V, except Virtex-7 HT FPGAs support only VCCO_0=1.8V. Make sure that the VCCO_0 matches the voltage level of the JTAG and serial configuration signals. Ensure CFGBVS pin connection is compatible with VCCO_0 voltage. See the "Configuration Banks Voltage Select" section of UG470, 7 Series FPGAs Configuration User Guide for more information.
VCCO Bank 14 | 1.2V - 3.3V, 1 of 47 uF or 100 uF (can be shared by up to 4 banks when powered by the same voltage), 2 of 4.7 uF, 4 of 0.47 uF | Single 47uf is shared among VCC0, VCC14, VCC15, and VCC34 | OK | Recommend VCCO_14, VCCO_0, JTAG signals, and serial signals are the same voltage level. See UG470, 7-Series FPGAs Configuration User Guide, for voltage limitations on specific device families. Make sure that VCCO_14 matches the VCCO of the serial configuration source. IMPORTANT! For Artix-7 and Kintex-7 and serial configuration mode, if VCCO_14 is 1.8V or 1.5V, then VCCO_0 must also be 1.8V or 1.5V, and CFGBVS must be connected to GND.
VCCO Bank 15 | 1.2V - 3.3V, 1 of 47 uF or 100 uF (can be shared by up to 4 banks when powered by the same voltage), 2 of 4.7 uF, 4 of 0.47 uF |  | N/A
HR banks 14,15,34 | 1.2V - 3.3, 1 of 47 uF or 100 uF per 4 banks (when powered by the same voltage) and 2 of 4.7 uF, 4 of 0.47 uF per bank |  | N/A | Make sure voltages are consistent with I/O standard selections. Due to the architectural differences between banks 14/15 (and banks 11, 12, 17, 18, 20 and 21 for SSI devices) and other banks, special consideration must be taken when using them under certain conditions. See the "State of I/Os During and After Configuration" and the "Special DCI Requirements in Some Banks" sections of UG471, 7 Series FPGAs SelectIO Resources User Guide for details.
HP banks N/A (No VCCAUX_IO groups) | There are no HP banks in this device. |  | N/A | Make sure voltages are consistent with I/O standard selections. Due to the architectural differences between banks 14/15 (and banks 11, 12, 17, 18, 20 and 21 for SSI devices) and other banks, special consideration must be taken when using them under certain conditions. See the "State of I/Os During and After Configuration" and the "Special DCI Requirements in Some Banks" sections of UG471, 7 Series FPGAs SelectIO Resources User Guide for details.
VREF | Connect to the appropriate voltage if the input standard requires a reference voltage. VREF supply stabilization requires one capacitor per pin; values are in the 0.022 µF—0.47 µF range. If internal VREF is used no capacitor is required and the pin can be used as I/O. |  | N/A
RSVDGND | Connect to ground |  | OK
Device Migration | 7A25T-CP238,,,,, |  | N/A | These are the devices that are pin compatible with the device that was chosen.
VCCO of unused I/O banks | Connect to VCCAUX or any available VCCO, but do not require decoupling. If you plan on migration, connect the unbounded I/O banks to the appropriate VCCO supplies. Make sure the voltage limits are followed for the HR and HP I/O's. |  | N/A | See AR #11906.
Power-up/down Sequence | VCCINT, VCCAUX, VCCO | Correct | OK | See Power Sequencing in data sheet.
Power Supply Ramp Time | 200 µS < VCCINT ramp < 50 mS 200 µS < VCCAUX ramp < 50 mS 200 µS < VCCO ramp < 50 mS 200 µS < VCCBRAM ramp < 50 mS 200 µS < VCCAUX_IO ramp < 50 mS 200 µS < MGTAVCC ramp < 50 mS 200 µS < MGTAVTT ramp < 50 mS 200 µS < MGTVCCAUX ramp < 50 mS VCCO2VCCAUX < 300 mS @ TJ 125C VCCO2VCCAUX < 500 mS @ TJ 100C VCCO2VCCAUX < 800 mS @ TJ 85C | Reference CMOD A7 board | OK | See the "Power Supply Ramp Time" table in the family data sheet for details.
Configuration
General Comments: | See User Guide 470. See the 'Configuration Memory Devices' appendix in UG908 for a list of flash memory devices supported by Vivado Device Programmer, and select a flash memory that can fit at least the Bitstream Length shown in this sheet. | UG470 (http://www.xilinx.com/support/documentation/user_guides/ug470_7Series_Config.pdf)
Item | Xilinx Recommendation | Actual Implementation | Status | Additional Information | Comments
CFGBVS | Connect to VCCO_0 | Followd Recommendation, previously this was connected to 1V0 but that was incorrect. | OK | Configuration Banks Voltage Select Dedicated input pin referenced to VCCO_0. CAUTION! CFGBVS must be tied to GND or VCCO_0 according to the VCCO_0 voltage to avoid device damage: - Connect CFGBVS=GND when VCCO_0 is 1.8V or 1.5V. - Connect CFGBVS=VCCO_0 when VCCO_0 is 3.3V or 2.5V. CFGBVS determines the I/O voltage operating range and voltage tolerance for the dedicated bank 0 at all times in all 7 series devices, except for Virtex-7 HT devices where CFGBVS is not available because bank 0 supports only 1.8V operation. For Artix-7 and Kintex-7 FPGAs, CFGBVS also determines the I/O voltage operating range and tolerance for the multi-purpose HRIO bank 14 and HRIO bank 15 prior to and during configuration. See the "Configuration Banks Voltage Select" section of UG470, 7 Series FPGAs Configuration User Guide for more information.
M[2:0] | Connect each mode pin either directly or via a 1 kΩ (or stronger) resistor to VCCO_0 or GND. M[2:0] = 111 | Connected through DIP switch to ground, connected to 3V3 via 4.7K ohm resistors | OK | Configuration Mode Dedicated input pins referenced to VCCO_0. M[2:0] determines the configuration mode. For the configuration mode settings, see the 7 Series FPGA Configuration Modes table in the "Configuration Interfaces" chapter of UG470, 7-Series FPGAs Configuration User Guide.
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

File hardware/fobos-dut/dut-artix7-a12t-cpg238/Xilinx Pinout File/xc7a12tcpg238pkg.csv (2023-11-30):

# (c) Copyright 2016 Xilinx | Inc. All rights reserved.
#
# This file contains confidential and proprietary information
# of Xilinx | Inc. and is protected under U.S. and
# international copyright and other intellectual property
# laws.
#
# DISCLAIMER
# This disclaimer is not a license and does not grant any
# rights to the materials distributed herewith. Except as
# otherwise provided in a valid license issued to you by
# Xilinx | and to the maximum extent permitted by applicable
# law: (1) THESE MATERIALS ARE MADE AVAILABLE "AS IS" AND
# WITH ALL FAULTS | AND XILINX HEREBY DISCLAIMS ALL WARRANTIES
# AND CONDITIONS | EXPRESS | IMPLIED | OR STATUTORY | INCLUDING
# BUT NOT LIMITED TO WARRANTIES OF MERCHANTABILITY | NON-
# INFRINGEMENT | OR FITNESS FOR ANY PARTICULAR PURPOSE; and
# (2) Xilinx shall not be liable (whether in contract or tort
# including negligence | or under any other theory of
# liability) for any loss or damage of any kind or nature
# related to | arising under or in connection with these
# materials | including for any direct | or any indirect
# special | incidental | or consequential loss or damage
# (including loss of data | profits | goodwill | or any type of
# loss or damage suffered as a result of any action brought
# by a third party) even if such damage or loss was
# reasonably foreseeable or Xilinx had been advised of the
# possibility of the same.
#
# CRITICAL APPLICATIONS
# Xilinx products are not designed or intended to be fail-
# safe | or for use in any application requiring fail-safe
# performance | such as life-support or safety devices or
# systems | Class III medical devices | nuclear facilities
# applications related to the deployment of airbags | or any
# other applications that could lead to death | personal
# injury | or severe property or environmental damage
# (individually and collectively | "Critical
# Applications"). Customer assumes the sole risk and
# liability of any use of Xilinx products in Critical
# Applications | subject only to applicable laws and
# regulations governing limitations on product liability.
#
# THIS COPYRIGHT NOTICE AND DISCLAIMER MUST BE RETAINED AS
# PART OF THIS FILE AT ALL TIMES.
#
#----------------------------------------------------------------------
# ASCII Pinout File
#
# Device : xc7a12tcpg238
# Date : 12/5/2017 14:53:37
# Revision : 1.1
# Status : Production
#
# These package specifications are released coincident with production
# release of a particular device. Customers receive formal notification
# of any subsequent changes.
#
#----------------------------------------------------------------------
# Modification History
# | Date : 06/06/2016
# | Revision: 0.1
# | Status : Evaluation Only
# | Details : Initial creation.
#-----------------------------------------------------------------------------
# | Date : 07/06/2017
# | Revision: 0.2
# | Status : Evaluation Only
# | Details : latest pinlist
#-----------------------------------------------------------------------------
# | Date : 08/18/2017
# | Revision: 1.0
# | Status : Engineering Sample
# | Details : Moved to Engineering Sample
#-----------------------------------------------------------------------------
# | Date : 10/30/2017
# | Revision: 1.1
# | Status : Production
# | Details : Moved to Production
# Notes : Scale_Factor = 0.90
#-----------------------------------------------------------------------------
#----------------------------------------------------------------------
Pin | Pin Name | Memory Byte Group | Bank | VCCAUX Group | Super Logic Region | I/O Type | No-Connect
U11 | DONE_0 | NA | 0 | NA | NA | CONFIG | NA
A11 | DXP_0 | NA | 0 | NA | NA | CONFIG | NA
C12 | GNDADC_0 | NA | 0 | NA | NA | CONFIG | NA
C13 | VCCADC_0 | NA | 0 | NA | NA | CONFIG | NA
B12 | VREFP_0 | NA | 0 | NA | NA | CONFIG | NA
B13 | VN_0 | NA | 0 | NA | NA | CONFIG | NA
C9 | VCCBATT_0 | NA | 0 | NA | NA | CONFIG | NA
C8 | TCK_0 | NA | 0 | NA | NA | CONFIG | NA
B11 | DXN_0 | NA | 0 | NA | NA | CONFIG | NA
A13 | VREFN_0 | NA | 0 | NA | NA | CONFIG | NA
A12 | VP_0 | NA | 0 | NA | NA | CONFIG | NA
C11 | CCLK_0 | NA | 0 | NA | NA | CONFIG | NA
V13 | M0_0 | NA | 0 | NA | NA | CONFIG | NA
W13 | M1_0 | NA | 0 | NA | NA | CONFIG | NA
W12 | INIT_B_0 | NA | 0 | NA | NA | CONFIG | NA
W11 | TDI_0 | NA | 0 | NA | NA | CONFIG | NA
V10 | TDO_0 | NA | 0 | NA | NA | CONFIG | NA
U13 | M2_0 | NA | 0 | NA | NA | CONFIG | NA
U12 | CFGBVS_0 | NA | 0 | NA | NA | CONFIG | NA
U10 | PROGRAM_B_0 | NA | 0 | NA | NA | CONFIG | NA
W10 | TMS_0 | NA | 0 | NA | NA | CONFIG | NA
D17 | IO_0_14 | NA | 14 | NA | NA | HR | NA
D18 | IO_L1P_T0_D00_MOSI_14 | 0 | 14 | NA | NA | HR | NA
D19 | IO_L1N_T0_D01_DIN_14 | 0 | 14 | NA | NA | HR | NA
E19 | IO_L2P_T0_D02_14 | 0 | 14 | NA | NA | HR | NA
F19 | IO_L2N_T0_D03_14 | 0 | 14 | NA | NA | HR | NA
E17 | IO_L3P_T0_DQS_PUDC_B_14 | 0 | 14 | NA | NA | HR | NA
E18 | IO_L3N_T0_DQS_EMCCLK_14 | 0 | 14 | NA | NA | HR | NA
G18 | IO_L4P_T0_D04_14 | 0 | 14 | NA | NA | HR | NA
H18 | IO_L4N_T0_D05_14 | 0 | 14 | NA | NA | HR | NA
F17 | IO_L5P_T0_D06_14 | 0 | 14 | NA | NA | HR | NA
G17 | IO_L5N_T0_D07_14 | 0 | 14 | NA | NA | HR | NA
G19 | IO_L6P_T0_FCS_B_14 | 0 | 14 | NA | NA | HR | NA
H19 | IO_L6N_T0_D08_VREF_14 | 0 | 14 | NA | NA | HR | NA
H17 | IO_L7P_T1_D09_14 | 1 | 14 | NA | NA | HR | NA
J17 | IO_L7N_T1_D10_14 | 1 | 14 | NA | NA | HR | NA
J19 | IO_L8P_T1_D11_14 | 1 | 14 | NA | NA | HR | NA
K19 | IO_L8N_T1_D12_14 | 1 | 14 | NA | NA | HR | NA
L19 | IO_L9P_T1_DQS_14 | 1 | 14 | NA | NA | HR | NA
M19 | IO_L9N_T1_DQS_D13_14 | 1 | 14 | NA | NA | HR | NA
M17 | IO_L10P_T1_D14_14 | 1 | 14 | NA | NA | HR | NA
N18 | IO_L10N_T1_D15_14 | 1 | 14 | NA | NA | HR | NA
K18 | IO_L11P_T1_SRCC_14 | 1 | 14 | NA | NA | HR | NA
L18 | IO_L11N_T1_SRCC_14 | 1 | 14 | NA | NA | HR | NA
K17 | IO_L12P_T1_MRCC_14 | 1 | 14 | NA | NA | HR | NA
L17 | IO_L12N_T1_MRCC_14 | 1 | 14 | NA | NA | HR | NA
N19 | IO_L13P_T2_MRCC_14 | 2 | 14 | NA | NA | HR | NA
P19 | IO_L13N_T2_MRCC_14 | 2 | 14 | NA | NA | HR | NA
N17 | IO_L14P_T2_SRCC_14 | 2 | 14 | NA | NA | HR | NA
P18 | IO_L14N_T2_SRCC_14 | 2 | 14 | NA | NA | HR | NA
R19 | IO_L15P_T2_DQS_RDWR_B_14 | 2 | 14 | NA | NA | HR | NA
T19 | IO_L15N_T2_DQS_DOUT_CSO_B_14 | 2 | 14 | NA | NA | HR | NA
U19 | IO_L16P_T2_CSI_B_14 | 2 | 14 | NA | NA | HR | NA
V19 | IO_L16N_T2_A15_D31_14 | 2 | 14 | NA | NA | HR | NA
P17 | IO_L17P_T2_A14_D30_14 | 2 | 14 | NA | NA | HR | NA
R17 | IO_L17N_T2_A13_D29_14 | 2 | 14 | NA | NA | HR | NA
T17 | IO_L18P_T2_A12_D28_14 | 2 | 14 | NA | NA | HR | NA
T18 | IO_L18N_T2_A11_D27_14 | 2 | 14 | NA | NA | HR | NA
U17 | IO_L19P_T3_A10_D26_14 | 3 | 14 | NA | NA | HR | NA
U18 | IO_L19N_T3_A09_D25_VREF_14 | 3 | 14 | NA | NA | HR | NA
W17 | IO_L20P_T3_A08_D24_14 | 3 | 14 | NA | NA | HR | NA
W18 | IO_L20N_T3_A07_D23_14 | 3 | 14 | NA | NA | HR | NA
V16 | IO_L21P_T3_DQS_14 | 3 | 14 | NA | NA | HR | NA
V17 | IO_L21N_T3_DQS_A06_D22_14 | 3 | 14 | NA | NA | HR | NA
U15 | IO_L22P_T3_A05_D21_14 | 3 | 14 | NA | NA | HR | NA
U16 | IO_L22N_T3_A04_D20_14 | 3 | 14 | NA | NA | HR | NA
V14 | IO_L23P_T3_A03_D19_14 | 3 | 14 | NA | NA | HR | NA
W14 | IO_L23N_T3_A02_D18_14 | 3 | 14 | NA | NA | HR | NA
W15 | IO_L24P_T3_A01_D17_14 | 3 | 14 | NA | NA | HR | NA
W16 | IO_L24N_T3_A00_D16_14 | 3 | 14 | NA | NA | HR | NA
U14 | IO_25_14 | NA | 14 | NA | NA | HR | NA
A17 | IO_L6N_T0_VREF_15 | 0 | 15 | NA | NA | HR | NA
A14 | IO_L10P_T1_AD4P_15 | 1 | 15 | NA | NA | HR | NA
A15 | IO_L10N_T1_AD4N_15 | 1 | 15 | NA | NA | HR | NA
B16 | IO_L11P_T1_SRCC_AD12P_15 | 1 | 15 | NA | NA | HR | NA
A16 | IO_L11N_T1_SRCC_AD12N_15 | 1 | 15 | NA | NA | HR | NA
C15 | IO_L12P_T1_MRCC_AD5P_15 | 1 | 15 | NA | NA | HR | NA
B15 | IO_L12N_T1_MRCC_AD5N_15 | 1 | 15 | NA | NA | HR | NA
C16 | IO_L13P_T2_MRCC_15 | 2 | 15 | NA | NA | HR | NA
B17 | IO_L13N_T2_MRCC_15 | 2 | 15 | NA | NA | HR | NA
B18 | IO_L14P_T2_SRCC_15 | 2 | 15 | NA | NA | HR | NA
A18 | IO_L14N_T2_SRCC_15 | 2 | 15 | NA | NA | HR | NA
C17 | IO_L19N_T3_A21_VREF_15 | 3 | 15 | NA | NA | HR | NA
G3 | IO_0_34 | NA | 34 | NA | NA | HR | NA
G2 | IO_L1P_T0_34 | 0 | 34 | NA | NA | HR | NA
G1 | IO_L1N_T0_34 | 0 | 34 | NA | NA | HR | NA
H3 | IO_L2P_T0_34 | 0 | 34 | NA | NA | HR | NA
H2 | IO_L2N_T0_34 | 0 | 34 | NA | NA | HR | NA
H1 | IO_L3P_T0_DQS_34 | 0 | 34 | NA | NA | HR | NA
J1 | IO_L3N_T0_DQS_34 | 0 | 34 | NA | NA | HR | NA
K2 | IO_L4P_T0_34 | 0 | 34 | NA | NA | HR | NA
K1 | IO_L4N_T0_34 | 0 | 34 | NA | NA | HR | NA
J3 | IO_L5P_T0_34 | 0 | 34 | NA | NA | HR | NA
K3 | IO_L5N_T0_34 | 0 | 34 | NA | NA | HR | NA
L3 | IO_L6P_T0_34 | 0 | 34 | NA | NA | HR | NA
L2 | IO_L6N_T0_VREF_34 | 0 | 34 | NA | NA | HR | NA
L1 | IO_L7P_T1_34 | 1 | 34 | NA | NA | HR | NA
M1 | IO_L7N_T1_34 | 1 | 34 | NA | NA | HR | NA
N2 | IO_L8P_T1_34 | 1 | 34 | NA | NA | HR | NA
P2 | IO_L8N_T1_34 | 1 | 34 | NA | NA | HR | NA
N1 | IO_L9P_T1_DQS_34 | 1 | 34 | NA | NA | HR | NA
P1 | IO_L9N_T1_DQS_34 | 1 | 34 | NA | NA | HR | NA
M3 | IO_L10P_T1_34 | 1 | 34 | NA | NA | HR | NA
N3 | IO_L10N_T1_34 | 1 | 34 | NA | NA | HR | NA
R1 | IO_L11P_T1_SRCC_34 | 1 | 34 | NA | NA | HR | NA
T1 | IO_L11N_T1_SRCC_34 | 1 | 34 | NA | NA | HR | NA
P3 | IO_L12P_T1_MRCC_34 | 1 | 34 | NA | NA | HR | NA
R3 | IO_L12N_T1_MRCC_34 | 1 | 34 | NA | NA | HR | NA
T3 | IO_L13P_T2_MRCC_34 | 2 | 34 | NA | NA | HR | NA
T2 | IO_L13N_T2_MRCC_34 | 2 | 34 | NA | NA | HR | NA
U1 | IO_L14P_T2_SRCC_34 | 2 | 34 | NA | NA | HR | NA
V1 | IO_L14N_T2_SRCC_34 | 2 | 34 | NA | NA | HR | NA
U3 | IO_L15P_T2_DQS_34 | 2 | 34 | NA | NA | HR | NA
U2 | IO_L15N_T2_DQS_34 | 2 | 34 | NA | NA | HR | NA
U4 | IO_L16P_T2_34 | 2 | 34 | NA | NA | HR | NA
V3 | IO_L16N_T2_34 | 2 | 34 | NA | NA | HR | NA
V4 | IO_L17P_T2_34 | 2 | 34 | NA | NA | HR | NA
W4 | IO_L17N_T2_34 | 2 | 34 | NA | NA | HR | NA
W3 | IO_L18P_T2_34 | 2 | 34 | NA | NA | HR | NA
W2 | IO_L18N_T2_34 | 2 | 34 | NA | NA | HR | NA
U6 | IO_L19P_T3_34 | 3 | 34 | NA | NA | HR | NA
U5 | IO_L19N_T3_VREF_34 | 3 | 34 | NA | NA | HR | NA
W6 | IO_L20P_T3_34 | 3 | 34 | NA | NA | HR | NA
W5 | IO_L20N_T3_34 | 3 | 34 | NA | NA | HR | NA
U7 | IO_L21P_T3_DQS_34 | 3 | 34 | NA | NA | HR | NA
V6 | IO_L21N_T3_DQS_34 | 3 | 34 | NA | NA | HR | NA
U9 | IO_L22P_T3_34 | 3 | 34 | NA | NA | HR | NA
U8 | IO_L22N_T3_34 | 3 | 34 | NA | NA | HR | NA
W9 | IO_L23P_T3_34 | 3 | 34 | NA | NA | HR | NA
W8 | IO_L23N_T3_34 | 3 | 34 | NA | NA | HR | NA
V7 | IO_L24P_T3_34 | 3 | 34 | NA | NA | HR | NA
W7 | IO_L24N_T3_34 | 3 | 34 | NA | NA | HR | NA
V9 | IO_25_34 | NA | 34 | NA | NA | HR | NA
C7 | MGTRREF_216 | NA | 216 | NA | NA | GTP | NA
A8 | MGTREFCLK0N_216 | NA | 216 | NA | NA | GTP | NA
B8 | MGTREFCLK0P_216 | NA | 216 | NA | NA | GTP | NA
B6 | MGTPRXP1_216 | NA | 216 | NA | NA | GTP | NA
B4 | MGTPRXP0_216 | NA | 216 | NA | NA | GTP | NA
B10 | MGTREFCLK1P_216 | NA | 216 | NA | NA | GTP | NA
A10 | MGTREFCLK1N_216 | NA | 216 | NA | NA | GTP | NA
A6 | MGTPRXN1_216 | NA | 216 | NA | NA | GTP | NA
A4 | MGTPRXN0_216 | NA | 216 | NA | NA | GTP | NA
B2 | MGTPTXP1_216 | NA | 216 | NA | NA | GTP | NA
A2 | MGTPTXN1_216 | NA | 216 | NA | NA | GTP | NA
D2 | MGTPTXP0_216 | NA | 216 | NA | NA | GTP | NA
D1 | MGTPTXN0_216 | NA | 216 | NA | NA | GTP | NA
M11 | VCCBRAM | NA | NA | NA | NA | NA | NA
N11 | VCCBRAM | NA | NA | NA | NA | NA | NA
A1 | GND | NA | NA | NA | NA | NA | NA
A3 | GND | NA | NA | NA | NA | NA | NA
A5 | GND | NA | NA | NA | NA | NA | NA
A7 | GND | NA | NA | NA | NA | NA | NA
A9 | GND | NA | NA | NA | NA | NA | NA
A19 | GND | NA | NA | NA | NA | NA | NA
B3 | GND | NA | NA | NA | NA | NA | NA
B5 | GND | NA | NA | NA | NA | NA | NA
B7 | GND | NA | NA | NA | NA | NA | NA
B9 | GND | NA | NA | NA | NA | NA | NA
B14 | GND | NA | NA | NA | NA | NA | NA
C2 | GND | NA | NA | NA | NA | NA | NA
C3 | GND | NA | NA | NA | NA | NA | NA
C4 | GND | NA | NA | NA | NA | NA | NA
C6 | GND | NA | NA | NA | NA | NA | NA
C10 | GND | NA | NA | NA | NA | NA | NA
C19 | GND | NA | NA | NA | NA | NA | NA
D3 | GND | NA | NA | NA | NA | NA | NA
E3 | GND | NA | NA | NA | NA | NA | NA
F1 | GND | NA | NA | NA | NA | NA | NA
F2 | GND | NA | NA | NA | NA | NA | NA
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

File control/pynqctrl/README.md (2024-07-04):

# Requirements

Vivado 2022.1 is required to build the project. It must be on the PATH, i.e. it can be invoked directrly from the shell.

# Build the project from source

Using a command line:

1. `cd fobos/sources/pynqctrl/vivado/`.
2. `make pynq_z2_rev1`
3. `make synth`
4. Go and make yourself a cup of coffee or tea, this is going to take a while
5. When Vivado is done, you will have the files `pynq_ctrl.bit` and `pynq_ctrl.hwh` in this directory.

Select the make option based on your Pynq board and the revision of the FOBOS shield
The possible build targets are: `pynq_z1_rev1`, `pynq_z1_rev2`, `pynq_z2_rev1` 

# Preparing the control board

1. Copy the `fobos/software directory to the /home/xilinx/ directory on the Pynq board using scp or sftp.
1. Copy the files `pynq_ctrl.bit` and `pynq_ctrl.hwh` from fobos/sources/pynqctrl/vivado to your Pynq board into the /home/xilinx/fobos/software/firmware/pynq directory.  
1. Use ssh to get a comand prompt on the Pynq board, change directory to the fobos/software/firmware/pynq/ directory and run the script `sudo ./install-pynq.sh`. It will ask you several questions about your Pynq setup, install the necessary files, and start the pynqserver.

# Modifying the Pynq board
Read the documentation in the fobos/docs directory for this.

# Test Run
**This section needs updating**
 1. In the PC connected to the PYNQ board. Open Jupyter-notebook and run the file `fobos/software/capture_traces_v3.ipynb`.

# Note about lock file

A lock file is created on the SCA Workstation each time a user tries to access the DUT. The file is located at `/tmp/fobos.lock`. Normally this file is automatically removed after the user releases the DUT connection. It the Jupyter Notebook crashes however, this file will stay and block access to the DUT. Remove this file manually and the lock is released. 

# Modify the project

1. Follow the first 2 steps of the *Built the project from source* instructions.
1. Open Vivado and open the newly created project `fobos/control/pynqctrl/vivado/pynq_controller/pynq_controller.xpr`
1. Open the block design.
1. New IPs can be added under `fobos/control/ip_repo` into their own folders.
1. To modify existing IPs by right-click on the IP in the block design and select `Edit in IP Packager`
1. When all changes are done run Synthesis and then Generate Bitstream
1. Exit Vivado
1. Copy the generated bit file and hwh file into the `fobos/control/pynqctrl/vivado/` directory 
   `cp pynq_controller/pynq_controller.gen/sources_1/bd/ctrl_top/hw_handoff/ctrl_top.hwh pynq_ctrl.hwh`
   `cp pynq_controller/pynq_controller.runs/impl_1/ctrl_top_wrapper.bit pynq_ctrl.bit`
1. Then copy these files to the Pynq board `/home/xilinx/fobos/software/firmware/pynq/` directory for testing.
1. Once everything works follow the instructions for *Committing updated project into GIT*

# Committing updated project into GIT

* In Vivado open block design and go to the Menu: File -> Project -> Write TCL
* Select options: Copy sources to new project
* Open the resulting file and make the following edits
  * remove all lines till but not including: `set origin_dir`
  * remove lines from including:  `# Set 'sources_1' fileset object`
                 till not including:  `# Set 'sources_1' fileset properties`
  * Add at the end of the file:
```
#######Added manually to create block design and wrapper
## Create block design
# source $origin_dir/src/bd/ctrl_top.tcl
#
## Generate the wrapper
# set design_name [get_bd_designs]
# make_wrapper -files [get_files $design_name.bd] -top -import
#
######END ADDED
```
* On the command line execute: `mv pynq_controller.tcl build_proj.tcl`
* Create block diagram tcl file by using the Vivado tcl console and type `write_bd_tcl ctrl_top.tcl`
* move this file using in the command line: `mv ctrl_top.tcl src/bd/`

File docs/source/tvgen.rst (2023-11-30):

.. _tvgen-label:

Test Vector Generation
**********************

The user must prepare test vectors before running data acquisition. User defined scripts or scripts provided with FOBOS can be used.
The data acquisition scripts will send the test vectors one at a time and collect traces from the oscilloscope.

Cryptographic hardware interfaces typically use multiple data types as input to cryptographic cores. 
For example, some algorithms might need plaintext/ciphertext, cryptographic keys, and random data. 
We provide a simple wrapper to split data provided by the control board to separate streams. 
This wrapper is directly compatible with CAESAR Hardware API interface and is expected to be directly compatible with a future Hardware API for Lightweight Cryptography (LWC API). 
We developed a simple, yet versatile protocol to enable the wrapper to split the data types. 
The wrapper receives data from the control board and distributes it into three FIFOs:

1. The Public Data Input (PDI) FIFO (i.e. plaintext) 
2. The Secret Data Input (SDI) FIFO (i.e. key) 
3. The Random Data Input (RDI) FIFO which stores random data which can be used for protected implementations that use masking schemes.

Once the wrapper prepares the data for the function core, it starts the core which consumes the data in the input FIFOs and produces output. 
The wrapper accumulates the output into a fourth FIFO called the Data Out (DO) FIFO until the expected number of bytes are stored. 
Then, the wrapper returns the data to the control board which forwards it back to the PC.

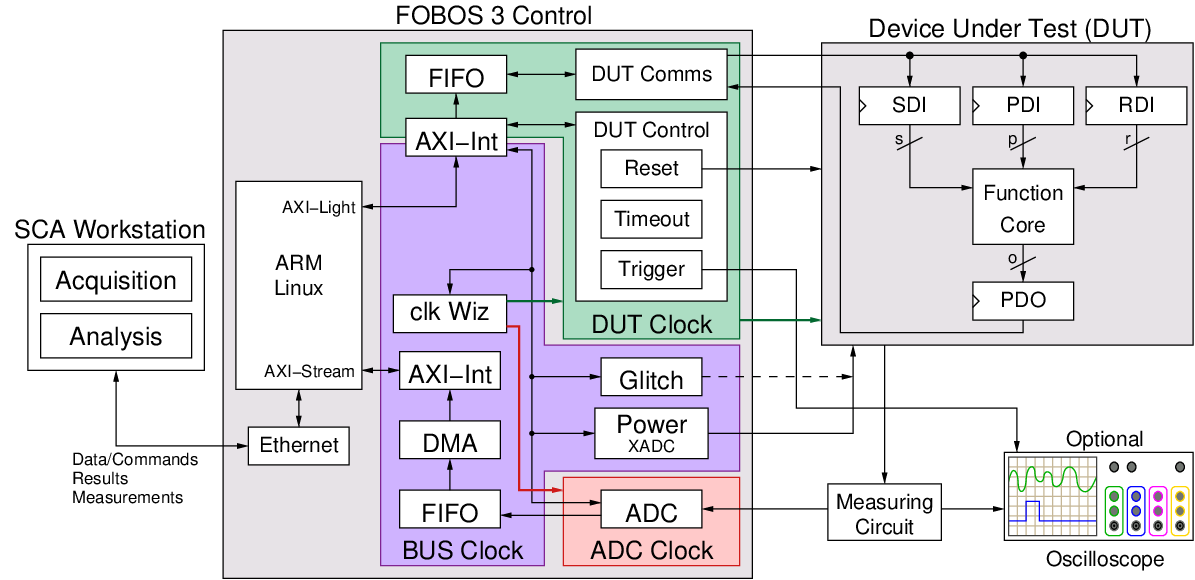
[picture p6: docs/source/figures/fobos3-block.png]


   FOBOS2 block diagram

The following is a brief description for the test vector format

Supported commands
==================

- 00C0 # pdi fifo (length in bytes to follow)
- 00C1 # sdi fifo (length in bytes to follow)
- 00C2 # rdi fifo (length in bytes to follow)
- 0081 # store expected output size (expected output size in bytes to follow)
- 0080 # select command register (command to follow)

FOBOS Protocol Example
----------------------

Here is an example of a signle test vector(split into multiple lines)::

    00C0 # pdi fifo (length in bytes to follow)
    0008 # 8 bytes
    FFFF # 8 bytes of pdi
    FFFF
    FFFF
    FFFF 
    00C1 # sdi fifo (length in bytes to follow)
    000A # 10 bytes
    0000 # 10 bytes of sdi
    0000
    0000
    0000
    0000 
    0081 # store expected output size
    0008 # 8 bytes of output expected
    0080 # select command register
    0001 # "start signal"

Using the blockCipherTVGen.py script
====================================
The blockCipherTVGen.py can be used to generate test vectors to be used by block ciphers. The script is located at fobos/software/tvgen/
There are two steps to use it:

1. Set user defined parameters.
2. Run the script. It will generate the test vector file and plaintext file (not required for acquisition).

Example: Generating AES-128 test vectors
----------------------------------------

AES-128 takes 16 bytes (128 bits) plaintext, 16 key and returns 16 byte ciphertext.
Here is an example to generate 4 test vectors with 16 byte blocks, key and ciphertext. Key is fixed in this case.

Settings::

    ############user defined settings
    TRACE_NUM = 1000                           # Number of traces
    PDI_LENGTH = 16                            # In byets
    SDI_LENGTH = 16                            # In bytes
    EXPECTED_OUT = 16                          # Expected output in bytes
    DIN_FILE = 'dinFile.txt'                   # Desitination file name
    PLAINTEXT_FILE = 'plaintext.txt'           # Desitination file name
    FIXED_KEY = 'yes'                          # Fixed key = yes | no
    KEY = '123456789009876ABCDFE12456789ABF'   # Fixed key

To run the script, use the following command::

    $ python blockCipherTVGen.py 

Here is how the generated dinFile.txt looks like.::

    $ cat dinFile.txt 
    00C000103AD5305EBD0C99C7482263E2D7ECEAED00C1001012345...0081001000800001
    00C000105C09504D713BF9B5925601E671EA257800C1001012345...0081001000800001
    00C00010A6D6DE2548E4CCF446ECA8E620E4E55500C1001012345...0081001000800001
    00C00010E0792CDE9AFDA7EAC33A8D0EADE524CB00C1001012345...0081001000800001
    00C000104A09A00A4C4268F0B6F4FCE4F514A6BB00C1001012345...0081001000800001

This file can now be used in FOBOS as a test vector file.

A plaintext.txt file is also generated, it includes only the PDI portion dinFile.txt::

    $ cat plaintext.txt 
    3A D5 30 5E BD 0C 99 C7 48 22 63 E2 D7 EC EA ED
    5C 09 50 4D 71 3B F9 B5 92 56 01 E6 71 EA 25 78
    A6 D6 DE 25 48 E4 CC F4 46 EC A8 E6 20 E4 E5 55
    E0 79 2C DE 9A FD A7 EA C3 3A 8D 0E AD E5 24 CB
    4A 09 A0 0A 4C 42 68 F0 B6 F4 FC E4 F5 14 A6 BB

This file can be used later by the analysis module.

Manually Generation of FOBOS-ready TVLA test vectors 
====================================================

Install CryptoTVGen
-------------------

Requirements:

OS: Tested on Linux and macOS

Dependencies:	

* Python 3.6.5	
* GNU Make 3.82	
* C compiler (e.g. gcc or clang)	

Install the latest version of CryptoTVGen::

 $ python3 -m pip install -U 'git+https://github.com/GMUCERG/LWC#subdirectory=software/cryptotvgen&egg=cryptotvgen'

To automatically download, extract, and build reference library of all LWC Round 2 candidates from the latest available version of SUPERCOP::

 $ python3 -m cryptotvgen.cli --prepare libs 
 
It installs all the available reference libraries to the directory shown below::

.cryptotvgen/supercop

Generating test vectors
-----------------------

All the necessary python scripts can be found in the following folder::

 /fobos/software/lwc_tools

All the generated output files can be found in the following folder::

 /fobos/software/lwc_tools/KAT
 
Generate an LWC test vector. This can be a short test vector. For example to generate test vectors for Xoodyak (refer cryptotvgen help for more information)::

 cryptotvgen --npub_size 128 --tag_size 128 --aead xoodyakv1 --gen_custom False,False,16,16,False

Convert into shared format (in this example 2 shares)::

 python3 gen_shared.py --rdi-file rdi.txt --pdi-file pdi.txt --sdi-file sdi.txt --rdi-width 384 --pdi-width 32 --sdi-width 32 --pdi-shares 2 --sdi-shares 2 --rdi-words 1000

Convert to FOBOS-ready TVLA test vectors::

 python3 lwc_2_fobos_tv.py --width 32 --shares 2 --num_vectors 10 --pdi_file pdi_shared_2.txt --sdi_file sdi_shared_2.txt --do_file do.txt

Where::

 --npub_size: size of the public message number in Bytes
 --tag_size: size of the tag in Bytes
 --aead: algorithm variant name
 --gen_custom: Randomly generate multiple test vectors, with each test vector specified using the following fields.
 --gen_custom NEW_KEY (Boolean), DECRYPT (Boolean), AD_LEN, PT_LEN or CT_LEN or HASH_LEN, HASH (Boolean)
 --rdi-width: width of the rdi port in Bits
 --rdi-words: number of random words in Bytes
 
Final output contains two files and are shown below::
 
 fvrchoicefile.txt
 dinFile.txt

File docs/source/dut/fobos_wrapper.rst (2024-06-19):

.. _fobos-dut-comms:

=======================
FOBOS DUT Communication
=======================
Test vectors are sent form PC one at a time to the control board which stores them briefly.
The control board starts sending the test vector to the DUT board through the FOBOS DUT interface.
The DUT wrapper then puts data in the correct FIFOs (PDI, SDI and RDI).
Once the DUT wrapper receives the start command from the controller, it de-asserts the function core reset signal and the function core will run and consume the data in the FIFOs. 
The output of the function core is stored in the DO fifo. 
Once the DO FIFO accumulates EXPECTED_OUTPUT bytes, the DUT wrapper will send this data to the control board which forwards it to the PC.

.. _dut-fobos_wrapper:

=============
FOBOS Wrapper
=============

The FOBOS wrapper provides translation from the FOBOS DUT interface to the Crypto Core Interface which is 
compatible with the GMU LWC Hardware API interface as described in :numref:`lwc_hw_api`.
A simplified block diagram 
of the FOBOS wrapper is shown in :numref:`fig_dut-block`. The 20-pin FOBOS target connector uses a 4-bit bidirectional 
data bus with FIFO style handshaking. Therefor, the top-level VHDL file of the wrapper is called ``half_duplex_dut.vhd``. 
It uses the ``half_duplex_interface.vhd`` to convert this into a 4-bit full duplex interface which connects to the 
``core_wrapper.vhd``. Inside the Core Wrapper, the user can port map their GMU LWC Hardware API conforming implementation.

.. _fig_dut-block:
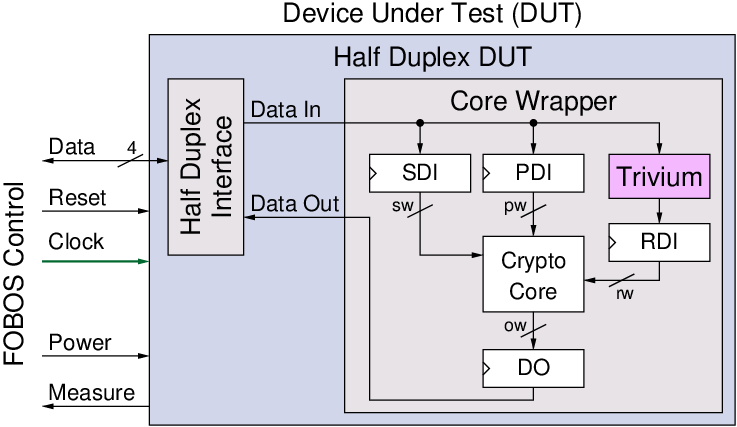
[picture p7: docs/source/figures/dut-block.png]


   Block Diagram of FOBOS Wrapper for the DUT

The Public Data Input (PDI), Secret Data Input (SDI), Random Data Input (RDI) and Data Output (DO) use First Word Fall-Through (FWFT) 
FIFOs called FIFO_0, FIFO_1, FIFO_OUT, and FIFO_RDI respectively. Their widths and depths can be set in the file 
``core_wrapper_pkg.vhdl``. Random data is provided by the Trivium :cite:`de_canniere_trivium_2005` stream cipher which can be seeded. 
For the sake of simplicity, :numref:`fig_dut-block` does not show the registers and control logic required for the 
FOBOS DUT Protocol or any required Parallel Input Serial Output (PISO) or Serial Input Parallel Output (SIPO) converters.

The VHDL code for the FOBOS Wrapper, including PISO, SIPO, FWFT FIFOs, and Trivium is provided in the directory
``dut/fpga_wrapper/src_rtl``.

=====================
Crypto Core Interface
=====================

The interface follows a simple AXI stream protocol. The 'valid' signals indicates data from source are valid and 'ready' signals 
indicates destination is ready to use data. When both 'valid' and 'ready' signals are set to logic 1, data is transferred.
All the data signals shown in the listing below, are connected to the FIFOs PDI, SDI, RDI and DO.

The function core (victim) is instantiated as follows in the ``core_wrapper.vhd`` file around line 173.
The example below shows how to instantiate the unprotected implementation of AES that is supplied as an 
example.

.. code-block:: vhdl

    --=============================================
    -- BEGING USER CRYPTO  
    -- Instantiate your core here
    crypto_core : entity work.aes_axi(behav)
    port map(
    	clk         => clk,
    	rst         => not crypto_input_en,
        -- data signals
    	pdi_data    => crypto_di0_data,
    	pdi_valid   => crypto_di0_valid,
    	pdi_ready   => crypto_di0_ready,

        sdi_data    => crypto_di1_data,
    	sdi_valid   => crypto_di1_valid,
    	sdi_ready   => crypto_di1_ready,

    	do_data     => crypto_do_data,
    	do_ready    => crypto_do_ready,
    	do_valid    => crypto_do_valid

        --! if rdi_interface for side-channel protected versions is required, uncomment the rdi interface
        -- ,rdi_data => crypto_rdi_data,
        -- rdi_ready => crypto_rdi_ready,
        -- rdi_valid => crypto_rdi_valid
    );
    -- END USER CRYPTO
    --=============================================

The widths *pw* of PDI "FIFO_0", *sw* of SDI "FIFO_1", *ow* of DO "FIFO_OUT", and *rw* of RDI "FIFO_RDI" 
as well as their depth in words of WIDTH bits has to be defined in ``core_wrapper_pkg.vhd`` which is shown 
below.

The default setting for RAND_WORDS is **0**. For values other than 0, a pseudo random number generator (PRNG) 
on the basis of the stream cipher Trivium will be generated.

.. code-block:: vhdl

    package core_wrapper_pkg is
        -- input fifos
        constant FIFO_0_WIDTH           : natural := 128    ;
        constant FIFO_0_LOG2DEPTH       : natural := 1      ;
        constant FIFO_1_WIDTH           : natural := 128    ;
        constant FIFO_1_LOG2DEPTH       : natural := 1      ;
        -- output fifo
        constant FIFO_OUT_WIDTH         : natural := 128    ;    
        constant FIFO_OUT_LOG2DEPTH     : natural := 1      ;
        -- random data
        constant RAND_WORDS             : natural := 0      ;
        constant FIFO_RDI_WIDTH         : natural := 64     ;
        constant FIFO_RDI_LOG2DEPTH     : natural := 3      ;  
    
    end core_wrapper_pkg;

It is highly recommended that the DUT is tested using the ``dut/fpga_wrapper/src_tb/core_wrapper_tb.vhd`` test bench and ensure 
that the output is valid. 
This testbench needs one test vector to be stored in the file dinFile.txt and generates doutFile.txt output file.

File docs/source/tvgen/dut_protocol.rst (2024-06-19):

.. _dut-protocol:

==================
FOBOS DUT Protocol
==================

.. _fig_dut-protocol:


   FOBOS DUT Protocol

FOBOS uses the simple protocol shown in :numref:`fig_dut-protocol`. 
An instruction consists of an Opcode and a Destination.
The Opcode describes in which type of storage should be used. 
A **C** indicates a FIFO, an **8** a 32-bit register. This is immediately followed by the Destination, i.e., the 
FIFO or register number. Each instruction is followed by a Parameter. In case of FIFO, the parameter contains the 
number of bytes of data following. In case of Register, it contains the data to be stored in the selected register.
:numref:`tab_dut-protocol_instructions` shows the implemented Instructions and the purpose of the associated 
Parameters.

.. _tab_dut-protocol_instructions:
.. table:: FOBOS DUT Protocol Instructions

    +--------+-------------+-------------+-------------------+---------------------------------------+
    | Opcode | Destination | Storage     | Usage             | Parameter                             |
    +========+=============+=============+===================+=======================================+
    | C      | 0           | FIFO_0      | PDI               | length of data in bytes               |
    +--------+-------------+-------------+-------------------+---------------------------------------+
    | C      | 1           | FIFO_1      | SDI               | length of data in bytes               |
    +--------+-------------+-------------+-------------------+---------------------------------------+
    | C      | 2           | FIFO_2      | AD  (optional)    | length of data in bytes               |
    +--------+-------------+-------------+-------------------+---------------------------------------+
    | C      | 3           | FIFO_3      | Nonce (optional)  | length of data in bytes               |
    +--------+-------------+-------------+-------------------+---------------------------------------+
    | 8      | 0           | Register 0  | cmd               | Command                               |
    +--------+-------------+-------------+-------------------+---------------------------------------+
    | 8      | 1           | Register 1  | outlen            | length of output in bytes             |
    +--------+-------------+-------------+-------------------+---------------------------------------+
    | 8      | 2           | Register 2  | rndlen            | length of random data in 32-bit words |
    +--------+-------------+-------------+-------------------+---------------------------------------+
    | 8      | 3           | Register 3  | user bits         | User definable bits                   |
    +--------+-------------+-------------+-------------------+---------------------------------------+
    | 8      | 4           | Register 4  | seed0             | Part of seed for RNG                  |
    +--------+-------------+-------------+-------------------+---------------------------------------+
    | 8      | 5           | Register 5  | seed1             | Part of seed for RNG                  |
    +--------+-------------+-------------+-------------------+---------------------------------------+
    | 8      | 6           | Register 6  | seed2             | Part of seed for RNG                  |
    +--------+-------------+-------------+-------------------+---------------------------------------+
    | 8      | 7           | Register 7  | seed3             | Part of seed for RNG                  |
    +--------+-------------+-------------+-------------------+---------------------------------------+

FIFOs 2 and 3, typically used for Associated Data (AD) and Nonce respectively, are optional as they are not used 
by all cryptographic functions. Additionally, the GMU LWC Hardware API for AEAD ciphers does not require these 
FIFOs as both, AD and Nonce, are part of the test vector transmitted to PDI.

The FOBOS DUT Protocol implements the following commands:

1. Start the cryptographic operation.
2. Generate *rndlen* 32-bit words of random data and put them into the RDI FIFO.
3. Reset the Pseudo Random Number Generator (RNG). It will start generating pseudo random numbers again 
   starting from its seed.

The RNG is seeded from the seed provided in registers 4-7. The default value of these registers is
``0x01234567_01234567_01234567_01234567``.

:numref:`fig_testvector` shows an example of a test vector for a block cipher. First 128-bit (16 Bytes) of plaintext are 
send for FIFO-0, then 128-bit (16 Bytes) of key for FIFO-2, followed by the expected cyphertext length 
of 128-bit (16 Bytes) and the command to start encryption.

.. _fig_testvector:
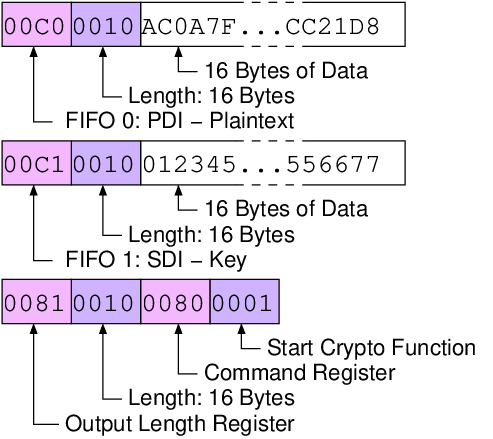
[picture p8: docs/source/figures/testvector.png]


   FOBOS Block Cipher Test Vector

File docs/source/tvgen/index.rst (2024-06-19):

.. _tvgen-label:

Test Vector Generation
**********************

The user must prepare test vectors before running data acquisition. User defined scripts or scripts provided with FOBOS can be used.
The data acquisition scripts will send the test vectors one at a time and collect traces from the oscilloscope.

Cryptographic hardware interfaces typically use multiple data streams as input to cryptographic cores. 
For example, some algorithms might need plaintext/ciphertext, cryptographic keys, and random data. 
FOBOS uses a simple protocol to transfer test vectors containing these data streams to the DUT. The 
**FOBOS DUT protocol** is described in :numref:`dut-protocol`.

FOBOS provides a simple test vector generator called **FobosTVGen**. It uses a key and generates a configurable number 
of test vectors with random data. Its usage is described in :numref:`FobosTVGen`. 

Furthermore, FOBOS can generate test vectors for hardware implementations that comply with the 
GMU LWC Hardware API :cite:`kaps_hardware_2022`.
FOBOS uses **CryptoTVGen**, which is part of the *Development Package for Hardware Implementations Compliant 
with the Hardware API for Lightweight Cryptography* :cite:`kamyar_mohajerani_development_2022`, to generate 
test vectors. A FOBOS tools then convert the test vectors generated by CryptoTVGen for use with FOBOS. 
Additionally, FOBOS has a tool that allows for the generation of test vectors  for 
Test Vector Leakage Analysis (TVLA) of unprotected and protected implementations that comply with the 
GMU LWC Hardware API. Creating GMU LWC Hardware API compatible testvectors for FOBOS is described in :numref:`CryptoTVGen`.

.. _fig_dut-block2:


   Block Diagram of FOBOS Wrapper for the DUT

.. toctree::
   :maxdepth: 1

   dut_protocol
   FobosTVGen
   CryptoTVGen

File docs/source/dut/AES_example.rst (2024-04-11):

.. _AES_example:

===========
AES Example
===========

As part of FOBOS, we provide a simple AES-128 implementation in VHDL. The VHDL code for this AES implementation is 
provided in the directory ``dut/example_cores/AES-128``. The block diagram of this implementation is shown in 
:numref:`fig_AES-block` and the technical details in :numref:`tab_example-aes`. 

.. _fig_AES-block:


   Block Diagram of the Example AES Implementation

.. _tab_example-aes:
.. table:: Technical Details of the Provided Example AES-128
    :align:   center

    +---------------------------------------+----+
    | Interface                             | AXI|
    +---------------------------------------+----+
    | PDI width                             | 128|
    +---------------------------------------+----+
    | SDI width                             | 128|
    +---------------------------------------+----+
    | DO width                              | 128|
    +---------------------------------------+----+
    | Rounds per clock cycle                |   1|
    +---------------------------------------+----+
    | Clock cycles for encrypting one block |  11|
    +---------------------------------------+----+

-----------------------
First Steps
-----------------------

Create a new directory for the AES DUT project for example ``AES-DUT``.
Copy all files of the example AES from the ``dut/example_cores/AES-128/vhdl`` directory, all files from the 
``dut/fpga_wrapper/src_rtl`` directory and the ``dut/fpga_wrapper/src_tb/core_wrapper_tb.vhd`` to this directory.
Additionally copy the constraint file that matches your DUT from the ``dut/fpga_wrapper/constraints`` directory.
Only modify the copied files. The example below assumes that you have installed FOBOS in ``/opt``
and that your DUT is the FOBOS FBD-A7.

.. code-block:: bash
    :caption: Command line example for copying all relevant files

    mkdir AES-DUT
    cd !$
    cp /opt/fobos/dut/example_cores/AES-128/vhdl/* .
    cp /opt/fobos/dut/fpga_wrapper/src_rtl/* .
    cp /opt/fobos/dut/fpga_wrapper/src_tb/core_wrapper_tb.vhd .
    cp /opt/fobos/dut/fpga_wrapper/constraints/FOBOS_Artix7.xdc .

-----------------------
AES Top Level Interface
-----------------------

The top level file of the example AES implementation is ``aes_axi.vhd``. Its interface is shown in :numref:`lst_aes-axi-top`. 
It features three AXI4-Stream compatible interfaces, one for plaintext (PDI), key (SDI), and ciphertext (DO) as 
well as a clock and reset input. This interface matches exactly the FOBOS wrapper's interface for the Crypto Core.
It is a wrapper for the basic AES implementation.

.. _lst_aes-axi-top:
.. code-block:: vhdl
    :caption: Entity declaration of the example AES AXI wrapper

    entity aes_axi is
        Port ( clk       : in  STD_LOGIC;
               rst       : in  STD_LOGIC;
               pdi_data  : in  STD_LOGIC_VECTOR (127 downto 0);
               pdi_valid : in  STD_LOGIC;
               pdi_ready : out STD_LOGIC;
               sdi_data  : in  STD_LOGIC_VECTOR (127 downto 0);
               sdi_valid : in  STD_LOGIC;
               sdi_ready : out STD_LOGIC;
               do_data   : out STD_LOGIC_VECTOR (127 downto 0);
               do_valid  : out STD_LOGIC;
               do_ready  : in  STD_LOGIC
    			  );
    end aes_axi;

The file ``aes_axi`` translates the very simple interface of the basic AES implementation which uses **out-of-band 
signaling**. It is shown in :numref:`lst_aes-non-pipe`. It expects 
one block of plaintext or 128-bit, and one 128-bit key on the input and produces 128-bit ciphertext. It has a clock 
signal and is idle until *start* is applied. Once the output is ready, it asserts the *done* signal. As *start* and 
*done* are explicit signals and not part of the data_in, key_in, or data_out signals, we call then out-of-band. 
On the other hand, **in-band signaling**, as used by the LWC Hardware API (see :numref:`lwc_hw_api`) requires 
a comprehensive protocol of commands and parameters being sent and received via PDI, SDI, and DO.

.. _lst_aes-non-pipe:
.. code-block:: vhdl
    :caption: Entity declaration of the basic AES with out-of-band signaling

    entity aes_non_pipe is
    port (	
        clock    : in  std_logic ;
        start    : in  std_logic ;
        data_in  : in  std_logic_vector (0 to 127);
        key_in   : in  std_logic_vector (0 to 127);
        data_out : out std_logic_vector (0 to 127);	
        done     : out std_logic
    );
    
    end aes_non_pipe;

It is therefore easily possible to adjust the file ``aes_axi`` to other block cipher implementations which use 
such simple out-of-band signaling. 

.. note::
    FOBOS is not concerned with what data is transmitted to PDI, SDI, or comes from DO, i.e., whether  
    the Crypto Core requires in-band signaling (LWC Hardware API) or not. FOBOS only needs to know which 
    data goes to which FIFO and how deep the FIFO has to be. FOBOS does not support out-of-band 
    signaling. If that is required it has to be derived from the AXI protocol as in the example AES, 
    or the FOBOS protocol has to be adjusted.

---------------------------
FOBOS Wrapper Configuration
---------------------------

The AES example has an AXI interface and has to be instantiated as follows in the ``core_wrapper.vhd`` file around line 173.
These are the default settings for this file. Note that the reset signal has to be inverted.

.. _lst_aes-wrapper:
.. code-block:: vhdl
    :caption: Port Map for example AES in core_wrapper.vhd

    --=============================================
    -- BEGING USER CRYPTO  
    -- Instantiate your core here
    crypto_core : entity work.aes_axi(behav)
    port map(
    	clk         => clk,
    	rst         => not crypto_input_en,
        -- data signals
    	pdi_data    => crypto_di0_data,
    	pdi_valid   => crypto_di0_valid,
    	pdi_ready   => crypto_di0_ready,

        sdi_data    => crypto_di1_data,
    	sdi_valid   => crypto_di1_valid,
    	sdi_ready   => crypto_di1_ready,

    	do_data     => crypto_do_data,
    	do_ready    => crypto_do_ready,
    	do_valid    => crypto_do_valid

        --! if rdi_interface for side-channel protected versions is required, uncomment the rdi interface
        -- ,rdi_data => crypto_rdi_data,
        -- rdi_ready => crypto_rdi_ready,
        -- rdi_valid => crypto_rdi_valid
    );
    -- END USER CRYPTO
    --=============================================

The example AES expects one block of plaintext or 128-bit, and one 128-bit key on the input. These have to 
be placed on *FIFO_0* and *FIFO_1* respectively. As the width of PDI and SDI are 128-bit, the width of 
these FIFOs have to match and they have to be only one word deep.
The output of this AES is also 128-bit wide, hence *FIFO_OUT* also has to be 128-bit wide and one word deep.
This has to be defined in ``core_wrapper_pkg.vhd`` which is shown in :numref:`lst_aes-wrapper-pkg`. 
This is also the default configuration of this file.

.. _lst_aes-wrapper-pkg:
.. code-block:: vhdl
    :caption: FIFO definitions for example AES in core_wrapper_pkg.vhd

    package core_wrapper_pkg is
        -- input fifos
        constant FIFO_0_WIDTH           : natural := 128    ;
        constant FIFO_0_LOG2DEPTH       : natural := 1      ;
        constant FIFO_1_WIDTH           : natural := 128    ;
        constant FIFO_1_LOG2DEPTH       : natural := 1      ;
        -- output fifo
        constant FIFO_OUT_WIDTH         : natural := 128    ;    
        constant FIFO_OUT_LOG2DEPTH     : natural := 1      ;
        -- random data
        constant RAND_WORDS             : natural := 8      ;
        constant FIFO_RDI_WIDTH         : natural := 64     ;
        constant FIFO_RDI_LOG2DEPTH     : natural := 3      ;  
    
    end core_wrapper_pkg;

.. note::

    The depth of a FIFO is :math:`2^{FIFO\_x\_LOG2DEPTH}`. For example if FIFO_x_LOG2DEPTH = 2, 
    the depth of the FIFO is :math:`2^2 = 4`.
    FIFO_x_LOG2DEPTH has to be equal or larger than 1, i.e. the minimum depth of the FIFO is 2.

----------------------------
Generating Bitstream for DUT
----------------------------

Create a project in Vivado e.g., ``AES-FBD-A7`` and add all source files that you copied in your project 
directory e.g., ``AES-DUT`` and the constraint file.

Select the FPGA device that is on your DUT. You can find that information in the DUT descriptions in 
:numref:`dut-board`.

Make sure that the file ``core_wrapper_tb.vhd`` is only used for Simulation. This can be set in the 
*Source File Properties* window.

Select the file *half_duplex_dut.vhd* as the top level. **Don't run synthesis yet!**
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

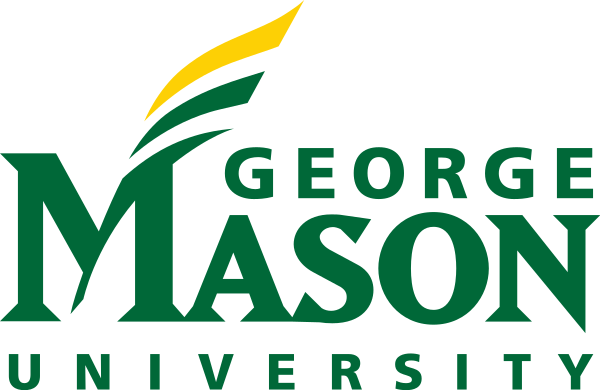
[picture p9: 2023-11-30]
docs/source/cergimg/Mason.png

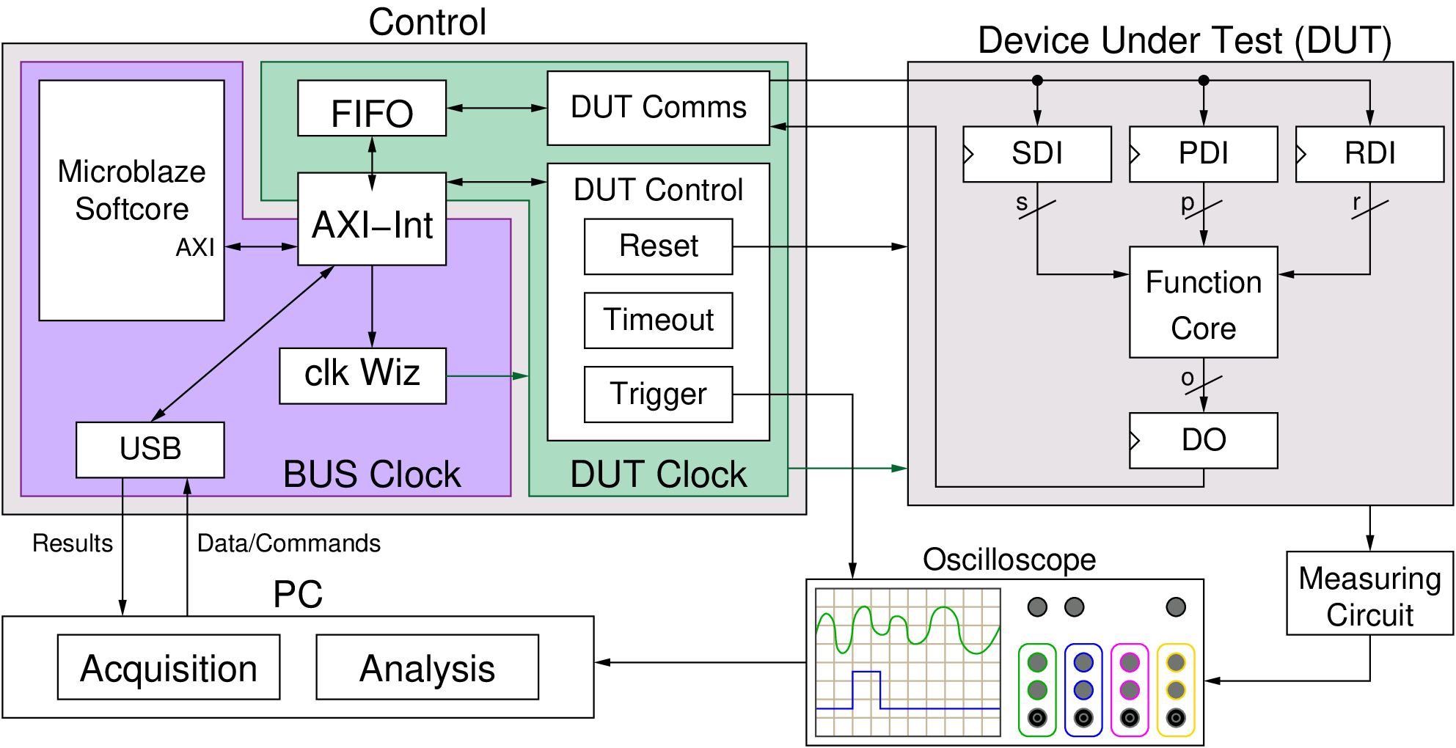
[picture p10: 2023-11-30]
dut/fpga_wrapper/doc/fobos2-block.png

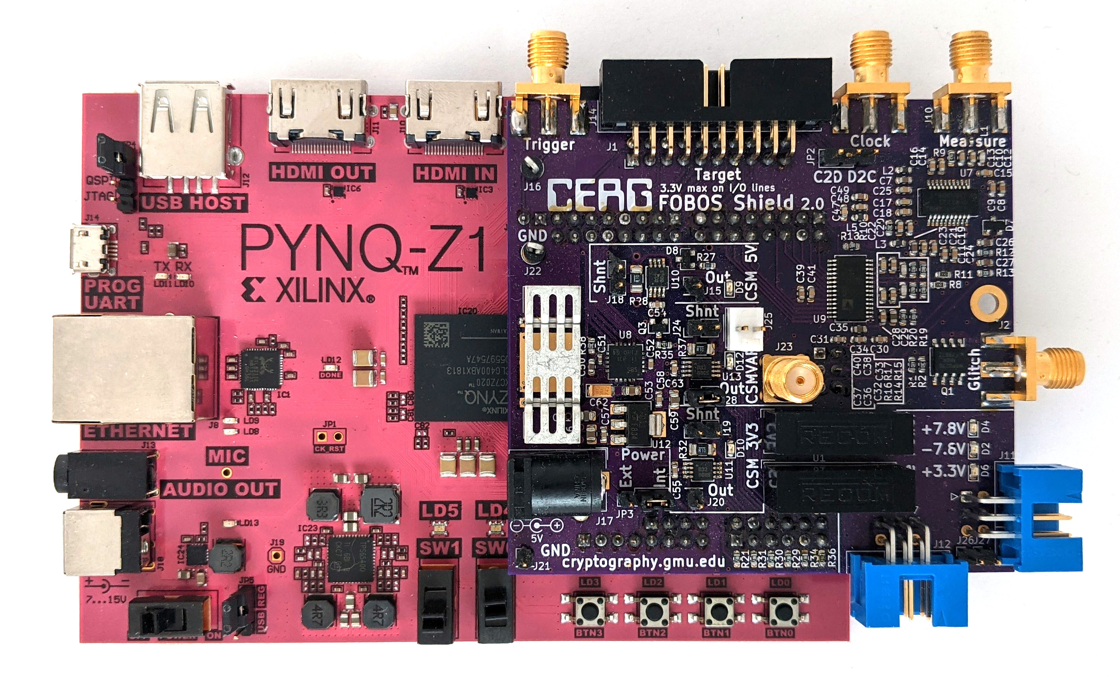
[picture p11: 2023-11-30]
docs/source/figures/fobos-shield-rev2.jpg

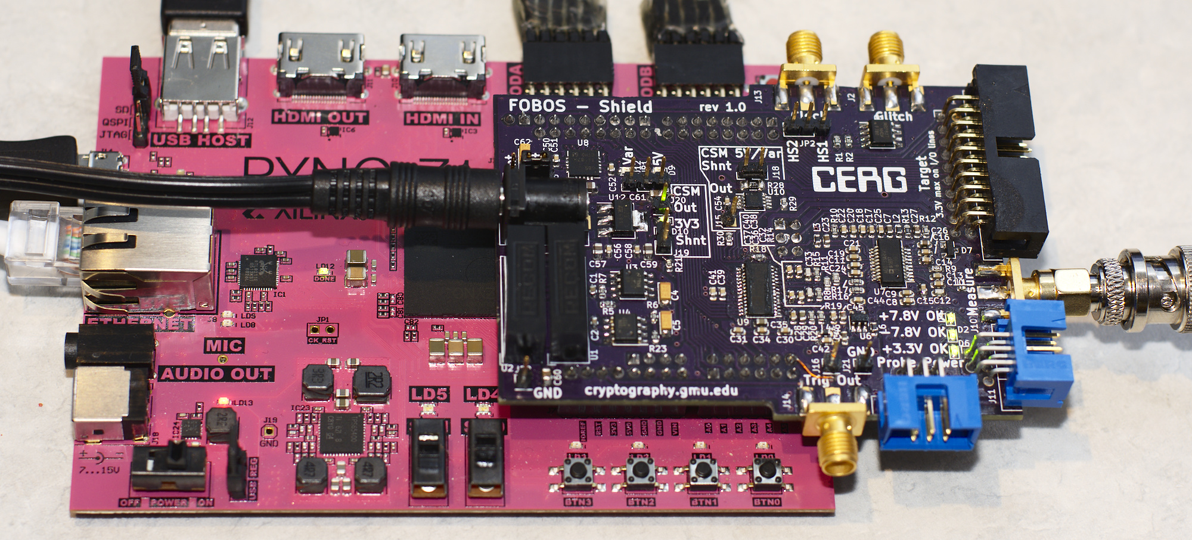
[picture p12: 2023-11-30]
docs/source/figures/FOBOS3-pic.jpg

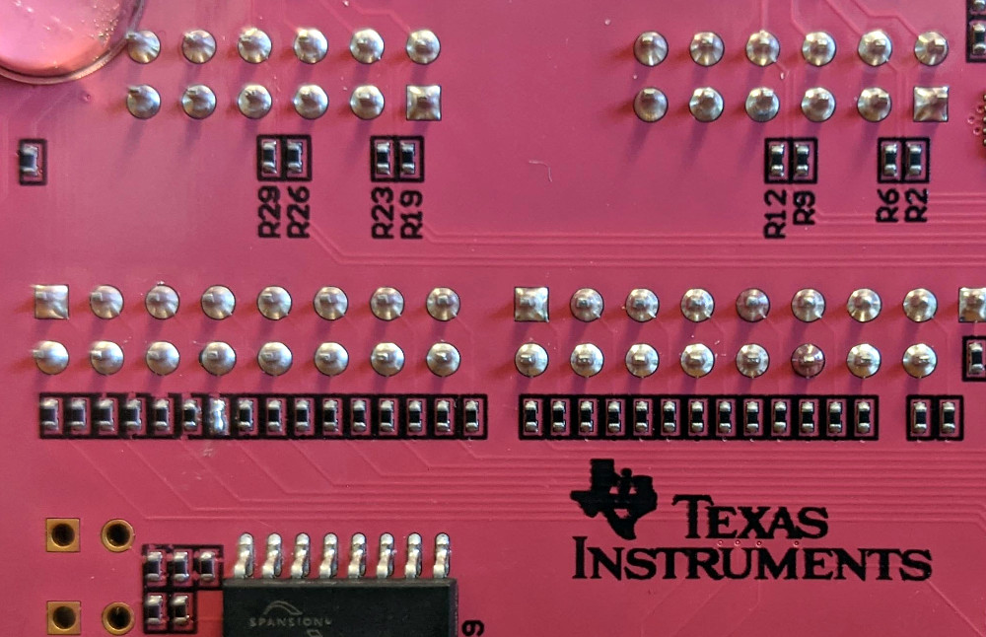
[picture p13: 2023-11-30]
control/pynqctrl/figures/pynq-modifications-shield-rev2.jpg

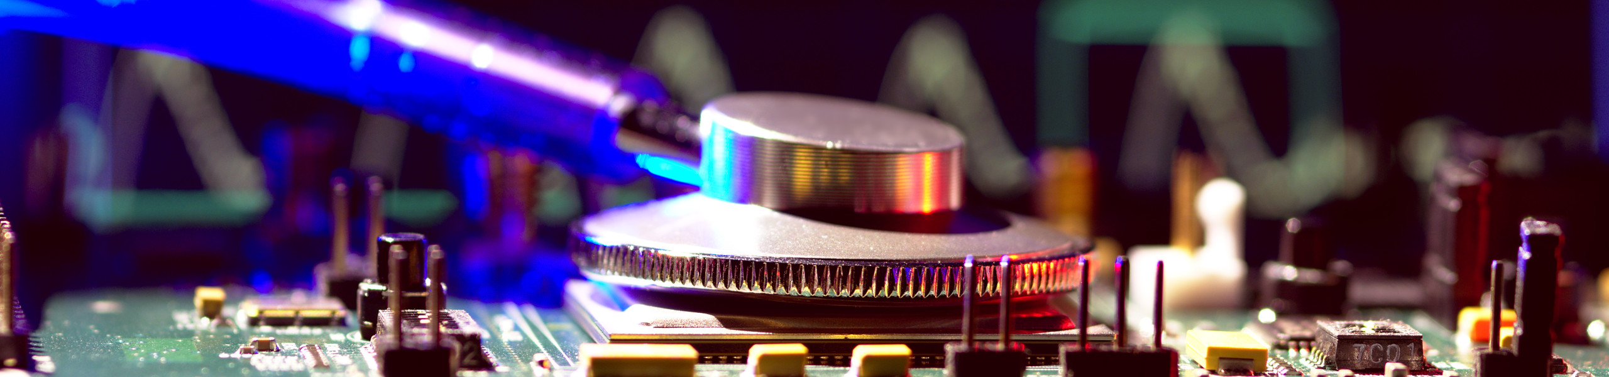
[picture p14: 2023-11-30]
docs/source/cergimg/fobos-slide.jpg

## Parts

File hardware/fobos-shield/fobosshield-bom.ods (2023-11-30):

Source: | /home/jkaps/projects/fobos/sources/fobos-shield/fobosshield.sch
Date: | Sun 30 Sep 2018 12:37:50 AM EDT
Tool: | Eeschema 5.0.0-fee4fd1~66~ubuntu18.04.1
Generator: | /usr/share/kicad/plugins/bom_csv_grouped_by_value_with_fp.py
Component Count: | 154
Ref | Qnty | Value | Cmp name | Footprint | Description | Vendor
C1, C2, | 2 | 100nF | C | Capacitor_SMD:C_0603_1608Metric | Unpolarized capacitor
C5, C4, C62, | 3 | 1uF | CP | Capacitor_Tantalum_SMD:CP_EIA-3216-18_Kemet-A | Polarised capacitor
C7, C23, C26, C27, C43, C45, C50, C3, C6, | 9 | 1uF | C | Capacitor_SMD:C_0603_1608Metric | Unpolarized capacitor
C9, C17, C20, C19, | 4 | 1nF | C_Small | Capacitor_SMD:C_0603_1608Metric | Unpolarized capacitor
C10, C16, C14, C8, C15, C18, C22, C21, C11, C24, C25, C28, C34, C30, C31, C39, C36, C38, C42, C46, C48, C54, C55, C58, C57, | 25 | 100n | C | Capacitor_SMD:C_0603_1608Metric | Unpolarized capacitor
C12, | 1 | 22pF | C_Small | Capacitor_SMD:C_0603_1608Metric | Unpolarized capacitor
C13, | 1 | 18nF | C_Small | Capacitor_SMD:C_0603_1608Metric | Unpolarized capacitor
C29, C35, | 2 | 10u | C_Small | Capacitor_SMD:C_0603_1608Metric | Unpolarized capacitor
C33, C32, | 2 | 100p | C_Small | Capacitor_SMD:C_0603_1608Metric | Unpolarized capacitor
C41, C37, C40, C44, C47, | 5 | 10n | C_Small | Capacitor_SMD:C_0603_1608Metric | Unpolarized capacitor
C49, | 1 | 2u2 | C_Small | Capacitor_SMD:C_0603_1608Metric | Unpolarized capacitor
C51, | 1 | 10nF | C | Capacitor_SMD:C_0603_1608Metric | Unpolarized capacitor
C52, | 1 | 220p | C | Capacitor_SMD:C_0603_1608Metric | Unpolarized capacitor
C53, | 1 | 10uF X5R | C | Capacitor_SMD:C_0805_2012Metric | Unpolarized capacitor
C59, C56, C60, C61, | 4 | 10uF | C | Capacitor_SMD:C_0805_2012Metric | Unpolarized capacitor
D1, D5, D11, | 3 | 5V1 | D_Zener_ALT | Diode_SMD:D_SOT-23_ANK | Zener Diode, alternativ symbol
D3, | 1 | 1N4148 | 1N4148 | Diode_SMD:D_SOD-323F | 100V 0.15A standard switching diode, DO-35
D4, D2, D6, D10, D12, | 5 | green | LED_ALT | LED_SMD:LED_0603_1608Metric | LED generic, alternativ symbol
D7, | 1 | BAV99 | BAV99 | Package_TO_SOT_SMD:SOT-23 | BAV99 High-speed switching diodes
D8, | 1 | 2V4 | D_Zener_ALT | Diode_SMD:D_SOT-23_ANK | Zener Diode, alternativ symbol
D9, | 1 | red | LED_ALT | LED_SMD:LED_0603_1608Metric | LED generic, alternativ symbol
J1, | 1 | Target | Conn_02x10_Odd_Even | Connector_IDC:IDC-Header_2x10_P2.54mm_Horizontal | Generic connector, double row, 02x10, odd/even pin numbering scheme (row 1 odd numbers, row 2 even numbers), script generated (kicad-library-utils/schlib/autogen/connector/)
J2, | 1 | Glitch | Conn_Coaxial_Power | cerg:SMA-JOHNSON-142-0701-801 | coaxial connector (BNC, SMA, SMB, SMC, Cinch/RCA, ...)
J3, | 1 | Analog | Conn_02x06_Odd_Even | cerg:PinHeader_2x06_P2.54mm_Vertical_flipped | Generic connector, double row, 02x06, odd/even pin numbering scheme (row 1 odd numbers, row 2 even numbers), script generated (kicad-library-utils/schlib/autogen/connector/)
J4, | 1 | IOH | Conn_02x08_Odd_Even | cerg:PinHeader_2x08_P2.54mm_Vertical_Flipped | Generic connector, double row, 02x08, odd/even pin numbering scheme (row 1 odd numbers, row 2 even numbers), script generated (kicad-library-utils/schlib/autogen/connector/)
J5, | 1 | SPI | Conn_02x03_Odd_Even | Connector_PinSocket_2.54mm:PinSocket_2x03_P2.54mm_Vertical | Generic connector, double row, 02x03, odd/even pin numbering scheme (row 1 odd numbers, row 2 even numbers), script generated (kicad-library-utils/schlib/autogen/connector/)
J6, | 1 | Analog2 | Conn_01x04 | Connector_PinHeader_2.54mm:PinHeader_1x04_P2.54mm_Vertical | Generic connector, single row, 01x04, script generated (kicad-library-utils/schlib/autogen/connector/)
J7, | 1 | Power | Conn_01x08 | Connector_PinHeader_2.54mm:PinHeader_1x08_P2.54mm_Vertical | Generic connector, single row, 01x08, script generated (kicad-library-utils/schlib/autogen/connector/)
J8, | 1 | IOL | Conn_02x08_Odd_Even | cerg:PinHeader_2x08_P2.54mm_Vertical_Flipped | Generic connector, double row, 02x08, odd/even pin numbering scheme (row 1 odd numbers, row 2 even numbers), script generated (kicad-library-utils/schlib/autogen/connector/)
J9, | 1 | SPI2 | Conn_01x02 | Connector_PinHeader_2.54mm:PinHeader_1x02_P2.54mm_Vertical | Generic connector, single row, 01x02, script generated (kicad-library-utils/schlib/autogen/connector/)
J10, | 1 | ADCin | Conn_Coaxial_Power | cerg:SMA-JOHNSON-142-0701-801 | coaxial connector (BNC, SMA, SMB, SMC, Cinch/RCA, ...)
J11, | 1 | PP1 | Conn_02x03_Odd_Even | Connector_IDC:IDC-Header_2x03_P2.54mm_Horizontal | Generic connector, double row, 02x03, odd/even pin numbering scheme (row 1 odd numbers, row 2 even numbers), script generated (kicad-library-utils/schlib/autogen/connector/)
J12, | 1 | PP2 | Conn_02x03_Odd_Even | Connector_IDC:IDC-Header_2x03_P2.54mm_Horizontal | Generic connector, double row, 02x03, odd/even pin numbering scheme (row 1 odd numbers, row 2 even numbers), script generated (kicad-library-utils/schlib/autogen/connector/)
J13, | 1 | Clock | Conn_Coaxial_Power | cerg:SMA-JOHNSON-142-0701-801 | coaxial connector (BNC, SMA, SMB, SMC, Cinch/RCA, ...)
J14, | 1 | Trigger | Conn_Coaxial_Power | cerg:SMA-JOHNSON-142-0701-801 | coaxial connector (BNC, SMA, SMB, SMC, Cinch/RCA, ...)
J15, | 1 | CSM5VCur | Conn_01x01 | Connector_PinHeader_2.54mm:PinHeader_1x01_P2.54mm_Vertical | Generic connector, single row, 01x01, script generated (kicad-library-utils/schlib/autogen/connector/)
J16, | 1 | Conn_01x01 | Conn_01x01 | Connector_PinHeader_2.54mm:PinHeader_1x01_P2.54mm_Vertical | Generic connector, single row, 01x01, script generated (kicad-library-utils/schlib/autogen/connector/)
J17, | 1 | Barrel_Jack_Switch | Barrel_Jack_Switch | Connector_BarrelJack:BarrelJack_CUI_PJ-102AH_Horizontal | DC Barrel Jack with an internal switch
J18, J19, | 2 | Conn_01x02 | Conn_01x02 | Connector_PinHeader_2.54mm:PinHeader_1x02_P2.54mm_Vertical | Generic connector, single row, 01x02, script generated (kicad-library-utils/schlib/autogen/connector/)
J20, | 1 | CSM3V3Cur | Conn_01x01 | Connector_PinHeader_2.54mm:PinHeader_1x01_P2.54mm_Vertical | Generic connector, single row, 01x01, script generated (kicad-library-utils/schlib/autogen/connector/)
J22, J21, | 2 | GND | Conn_01x01 | Connector_PinHeader_2.54mm:PinHeader_1x01_P2.54mm_Vertical | Generic connector, single row, 01x01, script generated (kicad-library-utils/schlib/autogen/connector/)
JP1, | 1 | 5V or Variable | Jumper_NC_Dual | Connector_PinHeader_2.54mm:PinHeader_1x03_P2.54mm_Vertical | Dual Jumper, normally closed
JP2, | 1 | ExtClkSel | Jumper_3_Open | Connector_PinHeader_2.54mm:PinHeader_1x03_P2.54mm_Vertical | Jumper, 3-pole, both open
JP3, | 1 | Power Ext or int | Jumper_3_Open | Connector_PinHeader_2.54mm:PinHeader_1x03_P2.54mm_Vertical | Jumper, 3-pole, both open
L1, | 1 | 120nH | L | Inductor_SMD:L_0402_1005Metric | Inductor
L2, | 1 | 1k500mA | L_Core_Ferrite | Inductor_SMD:L_0603_1608Metric | Inductor with Ferrite Core
L3, L4, L5, L6, | 4 | 1k/500mA | L_Core_Ferrite | Inductor_SMD:L_0603_1608Metric | Inductor with Ferrite Core
Q1, | 1 | IRF7807Z | IRF7807Z | Package_SO:SOIC-8_3.9x4.9mm_P1.27mm | Power MOSFET, 30V, 11A
Q2, | 1 | IRLML2502 | Q_NMOS_GSD | Package_TO_SOT_SMD:SOT-23 | Transistor N-MOSFETwith substrate diode (general)
Q3, | 1 | BSS138L | BSS138 | Package_TO_SOT_SMD:SOT-23 | 50V Vds, 0.22A Id, N-channel MOSFET, SOT-23
R3, R1, | 2 | 1R | R | Resistor_SMD:R_0603_1608Metric | Resistor
R5, R6, | 2 | 1K2, 1% | R | Resistor_SMD:R_0603_1608Metric | Resistor
R7, | 1 | 240R,1% | R | Resistor_SMD:R_0603_1608Metric | Resistor
R8, R11, | 2 | 33R, 0.5% | R_Small | Resistor_SMD:R_0603_1608Metric | Resistor, small symbol
R9, | 1 | 274R | R_Small | Resistor_SMD:R_0603_1608Metric | Resistor, small symbol
R10, R4, R2, | 3 | 10k | R | Resistor_SMD:R_0603_1608Metric | Resistor
R12, R13, R19, | 3 | 2k | R_Small | Resistor_SMD:R_0603_1608Metric | Resistor, small symbol
R14, R16, R15, R17, R20, | 5 | 1k | R_Small | Resistor_SMD:R_0603_1608Metric | Resistor, small symbol
R18, R27, R24, R25, R26, | 5 | 100R | R | Resistor_SMD:R_0603_1608Metric | Resistor
R22, | 1 | 22K | R | Resistor_SMD:R_0603_1608Metric | Resistor
R23, | 1 | 240R, 1% | R | Resistor_SMD:R_0603_1608Metric | Resistor
R28, R32, | 2 | 0R1 | R | Resistor_SMD:R_1206_3216Metric | Resistor
R30, R29, R21, R31, | 4 | 1k68 1% | R | Resistor_SMD:R_0603_1608Metric | Resistor
R33, R35, | 2 | 470R | R | Resistor_SMD:R_0603_1608Metric | Resistor
U1, | 1 | RB-0509D | NMA0509SC | Converter_DCDC:Converter_DCDC_muRata_NMAxxxxSC_THT | +/-55mA Isolated 1W Dual output DC/DC Converter Module, 5V Input Voltage, +/-9V Output Voltage, SIP3
U2, | 1 | REE-0505S | REE-0505S | Converter_DCDC:Converter_DCDC_muRata_NMAxxxxSC_THT | 200mA Isolated 1W Dual output DC/DC Converter Module, 5V Input Voltage, 5V Output Voltage, SIP7
U3, | 1 | LM317L_SO8 | LM317L_SO8 | Package_SO:SOIC-8_3.9x4.9mm_P1.27mm | 100mA 35V Adjustable Linear Regulator, SO-8
U4, | 1 | LM337L_SO8 | LM337L_SO8 | Package_SO:SOIC-8_3.9x4.9mm_P1.27mm | 100mA 35V Adjustable Negative Linear Regulator, SO-8
U5, | 1 | LD59015 | AP2204K-3.3 | cerg:sot323-5 | 150mA low dropout linear regulator, wide input voltage range, 3.3V fixed positive output, SOT-23-5 package
U6, | 1 | LP3985IM5-3.0 | LD3985G33R_TSOT23 | Package_TO_SOT_SMD:TSOT-23-5 | 150 mA Low Dropout Voltage Regulator, Fixed Output 3.3V, TSOT-23-5
U7, | 1 | AD8331 | AD8331 | cerg:QSOP-20_3.9x8.7mm_P0.635mm | Ultralow Noise VGAs with Preamplifier and Programmable Rin
U8, | 1 | TPS7A7100_VQFN20 | TPS7A7100_VQFN20 | Package_DFN_QFN:Texas_VQFN-RGW-20 | 1-A, Fast-Transient, Low-Dropout Voltage Regulator
U9, | 1 | AD9215 | AD9215 | Package_SO:TSSOP-28_4.4x9.7mm_P0.65mm | 10-Bit, 65/80/105 MSPS 3V A/D Converter
U10, U11, | 2 | INA225 | INA225 | Package_SO:MSOP-8_3x3mm_P0.65mm
U12, | 1 | LD1117S33TR_SOT223 | LD1117S33TR_SOT223 | Package_TO_SOT_SMD:SOT-223-3_TabPin2 | 800mA Fixed Low Drop Positive Voltage Regulator, Fixed Output 3.3V, SOT-223

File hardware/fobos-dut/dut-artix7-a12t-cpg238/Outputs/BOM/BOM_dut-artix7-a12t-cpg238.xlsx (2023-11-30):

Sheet: Project
Artix-7 DUT
Ref# | Qty. | Value | Size | Mouser # | Mfr. # | Manufacturer | Description
R29 R30 R37 R67 | 4 | 0R | 0603 | 603-RC0603JR-070RL | RC0603JR-070RL | Yageo | Thick Film Resistors - SMD 0 Ohms 100 mW 0603 5%
R23 | 1 | 0R1 | 1206 | 71-WSL1206R1000DEA | WSL1206R1000DEA | Vishay | Current Sense Resistors - SMD 1/4watt .1ohms .5%
R24 | 1 | 49R9 | 0603 | 652-CR0603FX-49R9ELF | CR0603-FX-49R9ELF | Bourns | Thick Film Resistors - SMD 49.9 ohm 1%
R75 R76 | 2 | 0R1 | 0805 | 588-KDV08FR100ET | KDV08FR100ET | Ohmite | Current Sense Resistors - SMD 0.1 ohm 0805 1% 0.25W
R22 | 1 | 100R | 0603 | 603-RC0603FR-13100RL | RC0603FR-13100RL | Yageo | Thick Film Resistors - SMD 100 OHM 1%
R36 R77 R78 | 3 | 1k | 0603 | 603-RC0603FR-071KL | RC0603FR-071KL | Yageo | Thick Film Resistors - SMD 1K OHM 1%
R35 R42 R43 R44 R45 R51 R60 R61 R62 R63 R64 R65 R66 R68 R70 R71 R73 R74 | 18 | 10k | 0603 | 603-RC0603FR-0710KL | RC0603FR-0710KL | Yageo | Thick Film Resistors - SMD 10K OHM 1%
R38 R39 R40 R49 | 4 | 100k | 0603 | 652-CR0603-FX-103ELF | CR0603-FX-1003ELF | Bourns | Thick Film Resistors - SMD 100K 1% 1/10 WATT
R21 | 1 | 1M | 0603 | 652-CR0603FX-1004ELF | CR0603-FX-1004ELF | Bourns | Thick Film Resistors - SMD 1M 1% 1/10W
R46 R47 | 2 | 120k | 0603 | 603-RC0603FR-13120KL | RC0603FR-13120KL | Yageo | Thick Film Resistors - SMD 120 kOhms 100-200 mW 0603 1%
R7 R8 R9 R10 R11 R12 R19 R20 R53 R72 | 10 | 200R | 0603 | 603-RC0603FR-07200RL | RC0603FR-07200RL | Yageo | Thick Film Resistors - SMD 200 OHM 1%
R1 R2 R3 R4 R5 R6 R13 R14 R15 R16 R17 R18 | 12 | 22R | 0603 | 603-RC0603FR-0722RL | RC0603FR-0722RL | Yageo | Thick Film Resistors - SMD 22 OHM 1%
R27 R28 R56 | 3 | 33R, 0.5% | 0603 | 667-ERA-3AHD330V | ERA-3AHD330V | Panasonic | Thin Film Resistors - SMD 0603 33ohms 50ppm 0.5% AEC-Q200
R34 | 1 | 3k48 | 0603 | 603-RC0603FR-073K48L | RC0603FR-073K48L | Yageo | Thick Film Resistors - SMD 3.48 kOhms 100mW 0603 1%
R57 R58 R59 R69 | 4 | 470R | 0603 | 603-RC0603FR-10470RL | RC0603FR-10470RL | Yageo | Thick Film Resistors - SMD 470 OHM 1%
R25 R26 R31 R32 R33 R41 R52 R54 R55 | 9 | 4k7 | 0603 | 603-RC0603FR-134K7L | RC0603FR-134K7L | Yageo | Thick Film Resistors - SMD 4.7 kOhms 100-200mW 0603 1%
R48 | 1 | 57k6 | 0603 | 652-CR0603FX-5762ELF | CR0603-FX-5762ELF | Bourns | Thick Film Resistors - SMD 57.6K ohm 1%
R50 | 1 | 800R | 0603 | 603-RC0603FR-07806RL | RC0603FR-07806RL | Yageo | Thick Film Resistors - SMD 806 Ohms 100 mW 0603 1%
C8 | 1 | 10nF | 0603 | 603-CS0603KRX79BB103 | CS0603KRX7R9BB103 | Yageo | Multilayer Ceramic Capacitors MLCC - SMD/SMT 10 nF 50 V 10% Ceramic Capacitors
C1 C2 C3 C4 C5 C9 C11 C13 C14 C16 C24 C54 C57 C58 | 14 | 100nF | 0603 | 77-VJ0603Y104JXQPBC | VJ0603Y104JXQPW1BC | Vishay / Vitramon | Multilayer Ceramic Capacitors MLCC - SMD/SMT 0603 0.1uF 10volts X7R 5%
C6 C10 C22 C23 | 4 | 10uF | 0805 | 81-GRM21BC81C106MA3L | GRM21BC81C106MA73L | Murata Electronics | Multilayer Ceramic Capacitors MLCC - SMD/SMT 0805 10uF 16volts X6S 20%
C18 C19 C20 | 3 | 20pF | 0603 | 80-C0603C200K8HACTU | C0603C200K8HACTU | KEMET | Multilayer Ceramic Capacitors MLCC - SMD/SMT 10V 20pF X8R 0603 10%
C15 | 1 | 2u2F | 0805
C17 C21 | 2 | 22uF | 0805 | 187-CL21A226KQCLRNC | CL21A226KQCLRNC | Samsung | Multilayer Ceramic Capacitors MLCC - SMD/SMT 22uF+/-10% 6.3V X5R 2012
C12 | 1 | 4n7F | 0603 | 710-885012206087 | 885012206087 | Wurth Electronics | Multilayer Ceramic Capacitors MLCC - SMD/SMT WCAP-CSGP 4700pF 0603 10% 50V MLCC
C29 C30 C31 C32 C33 C34 C35 C36 C42 C43 C44 C45 C46 C50 C51 C52 C53 C56 | 18 | 470nF | 0402 | 963-JMK105BJ474KV-F | JMK105BJ474KV-F | Taiyo Yuden | CAP CER 0.47UF 6.3V X5R 0402
C25 C26 C27 C28 C40 C41 C48 C49 | 8 | 4.7uF | 0402 | 81-GRM155R60J475ME8J | GRM155R60J475ME87J | Murata Electronics | CAP CER 4.7UF 6.3V X5R 0402
C37 C39 C47 C55 | 4 | 47uF | 0603 | 81-GRM21BR60J476ME5K | GRM21BR60J476ME15K | Murata Electronics | Multilayer Ceramic Capacitors MLCC - SMD/SMT 0805 47uF 6.3volts
C7 | 1 | 47uF | 0805 | 81-GRT21BR60J476ME3L | GRT21BR60J476ME13L | Murata Electronics | Multilayer Ceramic Capacitors MLCC - SMD/SMT 47UF 6.3V 20% 0805
C38 | 1 | 100uF | 1210 | 81-GRM32ER61A107ME0L | GRM32ER61A107ME0L | Murata Electronics | Multilayer Ceramic Capacitors MLCC - SMD/SMT 1210 100uF 10V
L1 L2 | 2 | 1k/500mA | 0603 | 963-FBMH1608HM102-T | FBMH1608HM102-T | Taiyo Yuden | Ferrite Beads HI CUR CHIP BD 0603 1000OHMS 25%
L3 | 1 | 1.5uH |  | 652-SRN2012-1R5M | SRN2012-1R5M | Bourns Inc. | FIXED IND 1.5UH 1.8A 108MOHM SMD
L4 | 1 | 3.3uH |  | 963-BRC2012T3R3MD | BRC2012T3R3MD | Taiyo Yuden | FIXED IND 3.3UH 870MA 221MOHM SM
L5 | 1 | 2.2uH |  | 652-SRN2010-2R2M | SRN2010-2R2M | Bourns Inc. | FIXED IND 2.2UH 1.7A 170MOHM SMD
D1 D2 D3 D4 D5 D6 | 6 | green | 0603 | 604-APT1608CGCK | APT1608CGCK | Kingbright | Standard LEDs - SMD Green Water Clear 570nm 40mcd 120deg
Q3 Q4 Q5 Q6 Q7 | 5 | BSS138L | SOT-23-3 | 512-BSS138L | BSS138L | ON Semiconductor | MOSFET 0.20A, 50V N-Channel SOT-23 MOSFET
Q1 | 1 | FDS9435A | SOIC-8 | 512-FDS9435A | FDS9435A | ON Semiconductor/Fairchild | MOSFET SO-8 SGL P-CH -30V
Q2 Q8 | 2 | 3904 | SOT-23-3 | 863-MMBT3904LT1G | MMBT3904LT1G | ON Semiconductor | Bipolar Transistors - BJT NPN GENERAL PURPOSE
U8 | 1 | LTC3569EFE#PBF | 16TSSOP | LTC3569EFE#PBF | LTC3569EFE#PBF | Analog Devices Inc. | Switching Voltage Regulators Programmable 1.2A and 2X600mA, Triple Buck Regulator
U5 | 1 | INA225 | MSOP-8 | 595-INA225AIDGKT | INA225AIDGKT | Texas Instruments | Current Sense Amplifiers 36V Bidir 0-Drift Ser Crnt-Shunt Mon
U7 | 1 | TS3A5018DBQR | 16SSOP | 595-TS3A5018DBQR | TS3A5018DBQR | Texas Instruments | Analog Switch ICs 10-Ohm Quad SPDT Analog Switch
U9 | 1 | IS25LP256D-JMLE | 16SOIC | IS25LP256D-JMLE | IS25LP256D-JMLE | ISSI, Integrated Silicon Solution Inc | NOR Flash 256M 3V 166MHZ Serial Flash
U6 | 1 | BGA2801 | SOT-363 | 771-BGA2801115 | BGA2801,115 | NXP USA Inc. | RF Amplifier 6CH MMIC Amp 3.8 dB 3.3V 14.3mA 2.8GHz
U1 | 1 | XC7A12T-cpg238 | CPG238 | 217-XC7A12T-1CPG238C | XC7A12T-1CPG238C | Xilinx | FPGA - Field Programmable Gate Array XC7A12T-1CPG238C
F1 | 1 | MF-MSMF050-2 | 1206 | 667-ERB-RG2R00V | ERB-RG2R00V | Panasonic Electronic Components | FUSE BOARD MOUNT 2A 63VDC 1206
U2 U3 U4 U10 U11 | 5 | Fuse | MSOP-10 | 576-SP3003-04ATG | SP3003-04ATG | Littelfuse | ESD Suppressors / TVS Diodes 4 Ch 8kV 0.65pF SPA
J10 | 1 | Barrel Jack |  | 490-PJ-102AH | PJ-102AH | CUI | DC Power Connectors Power Jacks
J4 | 1 | SMA Edge |  | 530-142-0701-801 | 142-0701-801 | Johnson / Cinch Connectivity Solutions | RF Connectors / Coaxial Connectors PC END MT JCK GLD .062" BOARD THICK
J6 J9 | 2 | SMA Vertical |  | 712-CONSMA008-G | CONSMA008-G | Linx Technologies | RF Connectors / Coaxial Connectors SMA Female PCB Mnt, Extended, Gold
J1 | 1 | Shrd Hdr | 2x10 | 517-30320-5002 | 30320-5002HB | 3M Electronic Solutions Division | Headers & Wire Housings 20P R/A 4WALL GLDFL
JP1, JP2, JP3, JP4 | 1 | Pin Header | 1x36 | 649-68001-236HLF | 68001-236HLF | Amphenol FCI | Headers & Wire Housings 36P HDR
J5 | 1 | Molex | 1x2-P2.54mm | 538-22-11-2022 | 22-11-2022 | Molex | Connector_Molex:Molex_KK-254_AE-6410-02A_1x02_P2.54mm_Vertical, gold
J7 | 1 | Shrd Hdr | 2x7 2mm | 538-87832-1420 | 878321420 | Molex | Headers & Wire Housings 14P SMD PB FREE SHRD
J3 J8 | 2 | 575-8 |  | 534-575-8 | 575-8 | Keystone Electronics | CONN BANANA JACK SOLDER
J2 | 1 | Pin Socket | 2x6 90 deg | 200-SSW10602FDRA | SSW-106-02-F-D-RA | Samtec | Board to Board & Mezzanine Connectors Tiger Buy Socket Strip with PCB Tails, 0.100 Pitch
TP1 TP2 TP3 TP4 TP5 TP6 TP7 TP8 TP9 | 9 | 5281 |  | 534-5281 | 5281 | Keystone Electronics | Circuit Board Hardware - PCB TEST POINT BLACK MULTIPURPOSE
S1 | 1 | JS202011SCQN |  | 611-JS202011SCQN | JS202011SCQN | C&K | SWITCH SLIDE DPDT 300MA 6V
S2 S3 S4 S5 | 4 | 1825910-6 |  |  | 1825910-6 | TE Connectivity ALCOSWITCH Switches | SWITCH TACTILE SPST-NO 0.05A 24V
SW1 SW2 | 2 | SW_DIP_x03 |  | 490-DS04254203BK-SMT | DS04-254-2-03BK-SMT | CUI Devices | DIP SWITCH, SPST, 2.54 PITCH, FL
The following components are DNI
R37 R77 C48 C49 C50 C51 C52 C53

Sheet: MTC
FOBOS 3 MTC
C1, C4, C5, C6, C7 | 5 | 100nF | 0603 | 77-VJ0603Y104JXQPBC | VJ0603Y104JXQPW1BC | Vishay / Vitramon | Multilayer Ceramic Capacitors MLCC - SMD/SMT 0603 0.1uF 10volts X7R 5% | #REF! | #REF!
C2 | 1 | 10uF | 0805 | 81-GRM21BC81C106MA3L | GRM21BC81C106MA73L | Murata Electronics | Multilayer Ceramic Capacitors MLCC - SMD/SMT 0805 10uF 16volts X6S 20% | #REF! | #REF!
C3 | 1 | 47uF | 0805 | 81-GRM21BR60J476ME5K | GRM21BR60J476ME15K | Murata Electronics | Multilayer Ceramic Capacitors MLCC - SMD/SMT 0805 47uF 6.3volts | #REF! | #REF!
D1 | 1 | green | 0603 | 604-APT1608CGCK | APT1608CGCK | Kingbright | Standard LEDs - SMD Green Water Clear 570nm 40mcd 120deg | #REF! | #REF!
F1 | 1 | Fuse | 1812 | 652-MF-MSMF050-2 | MF-MSMF050-2 | Bourns | Resettable Fuses - PPTC 0.50A 15V 0.15ohm AEC-Q200 | #REF! | #REF!
J1, J2, J3, J4 | 1 | Pin Header | 2x36 | 649-67997-272HLF | 67997-272HLF | Amphenol FCI | Headers & Wire Housings BREAKAWAY HEADER 72 | #REF! | #REF!
J5 | 1 | Shrd Hdr | 2x10 | 517-30320-5002 | 30320-5002HB | 3M Electronic Solutions Division | Headers & Wire Housings 20P R/A 4WALL GLDFL | #REF! | #REF!
J6, J7, JP2, JP3, JP4 | 1 | Pin Header | 1x36, 90deg | 710-61303611021 | 61303611021 | Wurth Electronics | Headers & Wire Housings WR-PHD 2.54mm Hdr 36P Single RA Gold | #REF! | #REF!
J8, J9 | 2 | SMA Edge |  | 530-142-0701-801 | 142-0701-801 | Johnson / Cinch Connectivity Solutions | RF Connectors / Coaxial Connectors PC END MT JCK GLD .062" BOARD THICK | #REF! | #REF!
J10, J11 | 2 | Pin Socket | 2x10 | 517-929852-01-10-RB | 929852-01-10-RB | 3M | Headers & Wire Housings 20/2R/BM SKT/.100 STR/.125/30AVE/ROHS | #REF! | #REF!
J12, J13 | 2 | Pin Header | 2x36, 90deg | 710-61303621021 | 61303621021 | Wurth Electronics | Headers & Wire Housings WR-PHD 2.54mm Hdr 36P Dual RA Gold | #REF! | #REF!
JP1 | 1 | Pin Header | 1x36 | 649-68001-236HLF | 68001-236HLF | Amphenol FCI | Headers & Wire Housings 36P HDR | #REF! | #REF!
L1 | 1 | 1k/500mA | 0603 | 963-FBMH1608HM102-T | FBMH1608HM102-T | Taiyo Yuden | Ferrite Beads HI CUR CHIP BD 0603 1000OHMS 25% | #REF! | #REF!
Q1 | 1 | BSS138L | SOT-23-3 | 512-BSS138L | BSS138L | ON Semiconductor | MOSFET 0.20A, 50V N-Channel SOT-23 MOSFET | #REF! | #REF!
Q2 | 1 | BSS84 | SOT-23-3 | 726-BSS84PH6327 | BSS84P H6327 | Infineon | MOSFET P-Ch -60V -170mA SOT-23-3 | #REF! | #REF!
R1, R9, R10, R11, R12, R13, R14, R15, R16, R17, R18, R19 | 12 | 22R | 0603 | 603-RC0603FR-0722RL | RC0603FR-0722RL | Yageo | Thick Film Resistors - SMD 22 OHM 1% | #REF! | #REF!
R2, R3, R6, R7 | 4 | 10k | 0603 | 603-RC0603FR-0710KL | RC0603FR-0710KL | Yageo | Thick Film Resistors - SMD 10K OHM 1% | #REF! | #REF!
R4 | 1 | 1R | 1206 | 660-SR732BTTD1R00D | SR732BTTD1R00D | KOA Speer | Current Sense Resistors - SMD 1 OHM .5%, 330mW | #REF! | #REF!
R5 | 1 | 470R | 0603 | 603-RC0603FR-10470RL | RC0603FR-10470RL | Yageo | Thick Film Resistors - SMD 470 OHM 1% | #REF! | #REF!
R8 | 1 | 10R | 1210 | 660-SR732ETTE10R0F | SR732ETTE10R0F | KOA Speer | Current Sense Resistors - SMD 10ohms 1% 100 PPM, 500mW | #REF! | #REF!
U1, U2, U3 | 3 | Fuse | MSOP-10 | 576-SP3003-04ATG | SP3003-04ATG | Littelfuse | ESD Suppressors / TVS Diodes 4 Ch 8kV 0.65pF SPA | #REF! | #REF!
 |  |  |  |  |  |  |  | #REF! | #REF!

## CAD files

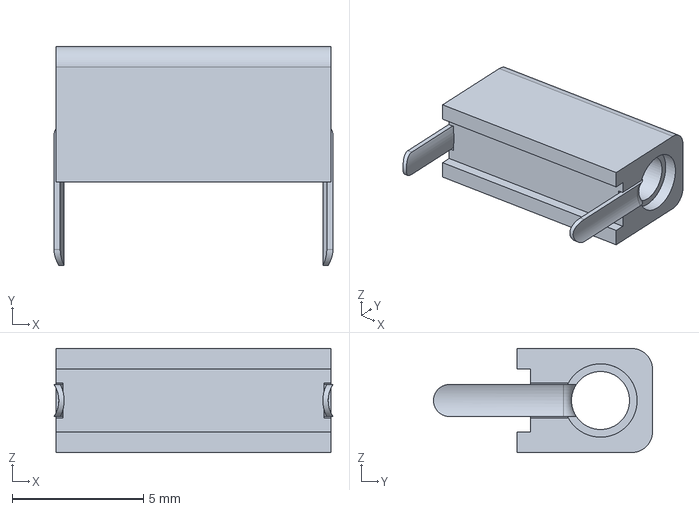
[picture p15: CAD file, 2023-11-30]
hardware/fobos-dut/dut-artix7-a12t-cpg238/3d models/BELFUSE_1050753001/105-0753-001.stp
10.6 x 8.34 x 3.96 mm

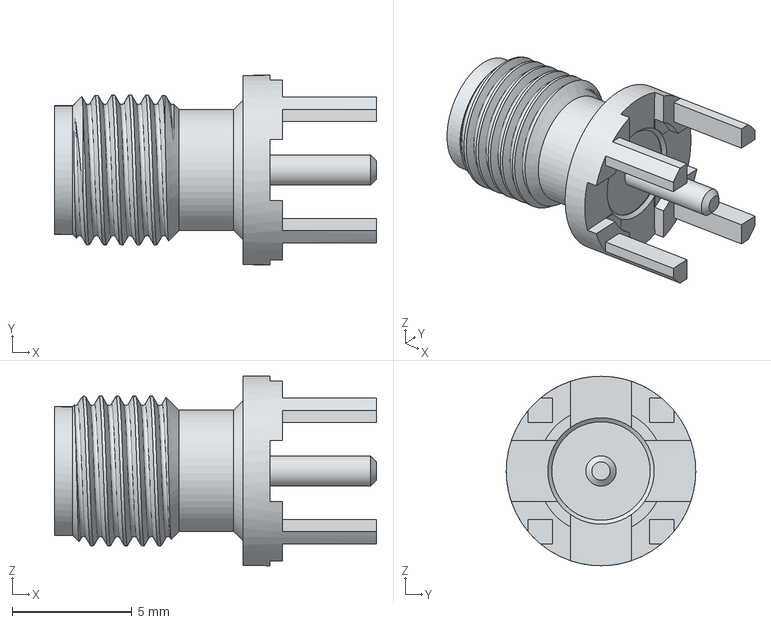
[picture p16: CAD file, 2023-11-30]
hardware/fobos-dut/dut-artix7-a12t-cpg238/3d models/BELFUSE_1420701201/142-0701-201.stp
13.5 x 7.92 x 7.92 mm

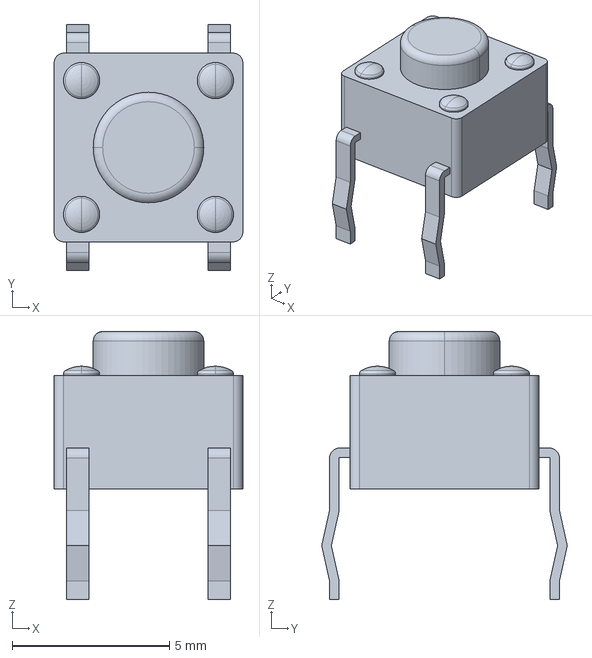
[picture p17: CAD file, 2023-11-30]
hardware/fobos-dut/dut-artix7-a12t-cpg238/3d models/ENG_CVM_CVM_1825910-6_C.3d_stp/c-1825910-6-c-3d.stp
5.99 x 7.80 x 8.51 mm

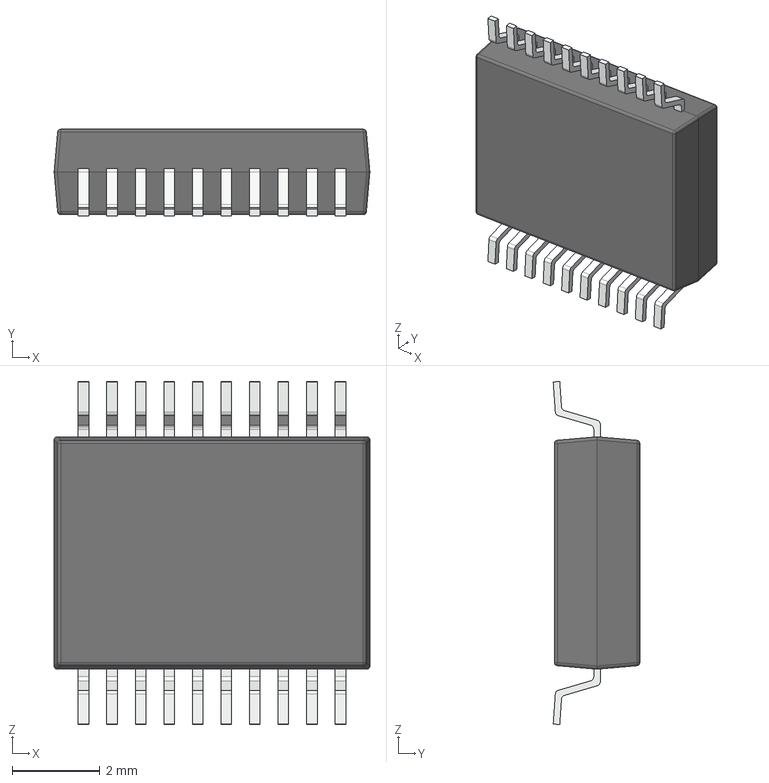
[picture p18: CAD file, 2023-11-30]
hardware/fobos-shield-Z2/cerg_3d_models/SSOP-20.step
7.20 x 1.98 x 7.82 mm

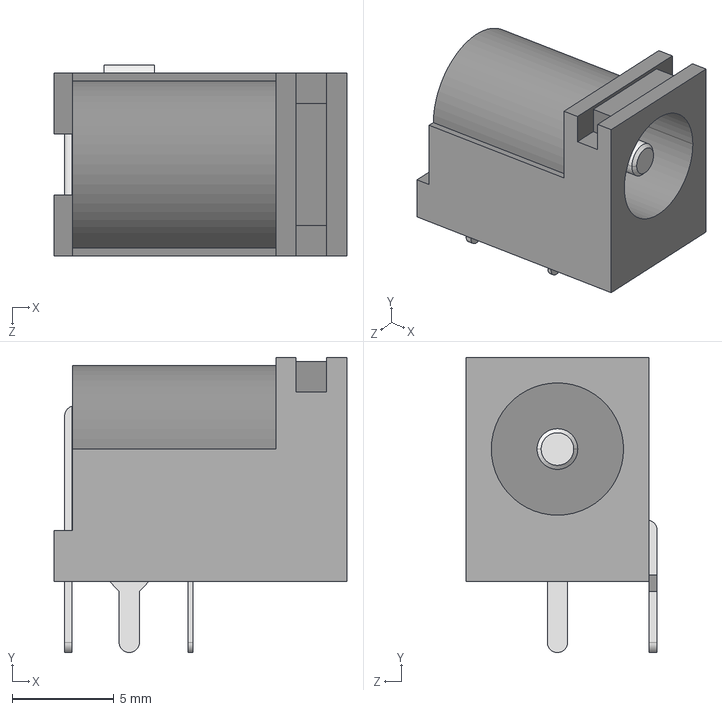
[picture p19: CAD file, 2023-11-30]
hardware/fobos-dut/dut-artix7-a12t-cpg238/3d models/CUI_PJ-102AH.step
14.4 x 14.5 x 9.40 mm

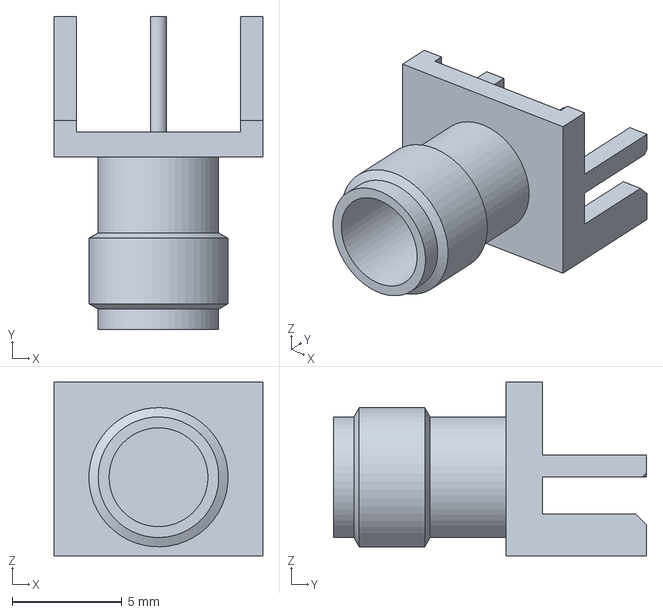
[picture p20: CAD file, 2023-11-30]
hardware/fobos-shield-Z2/cerg_3d_models/SMA_Board_Edge_Molex_732511150.step
9.53 x 14.3 x 7.93 mm

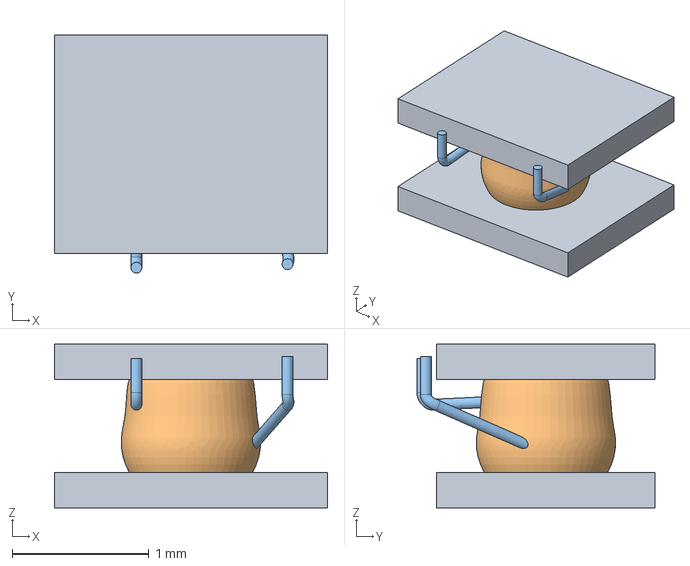
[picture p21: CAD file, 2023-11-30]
hardware/fobos-dut/dut-artix7-a12t-cpg238/3d models/SRN2012 series.stp
2.00 x 1.75 x 1.20 mm

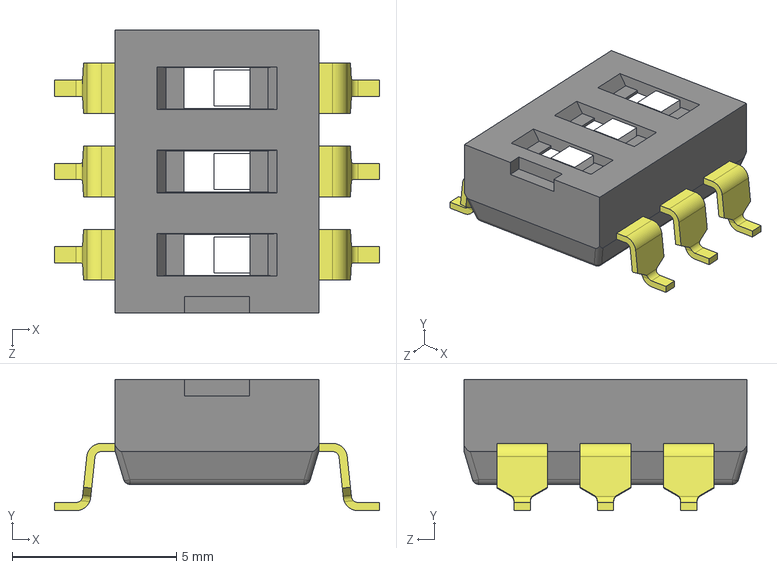
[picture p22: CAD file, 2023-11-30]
hardware/fobos-shield-Z2/cerg_3d_models/CUI_DEVICES_DS04-254-2-03BK-SMT-TR.step
9.90 x 4.00 x 8.62 mm

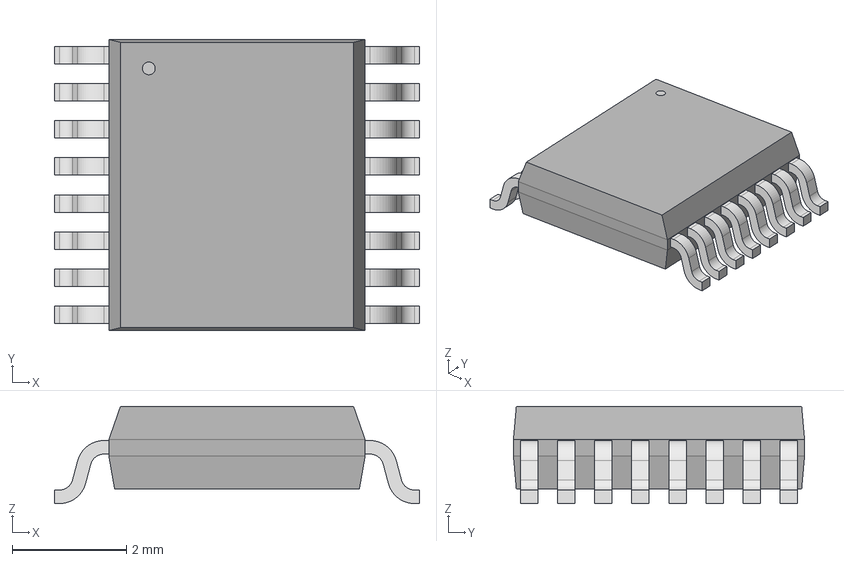
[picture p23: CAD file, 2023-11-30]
hardware/fobos-dut/dut-artix7-a12t-cpg238/cerg_3d_models/TSSOP-16_FEBA_LIT.step
6.40 x 5.11 x 1.70 mm

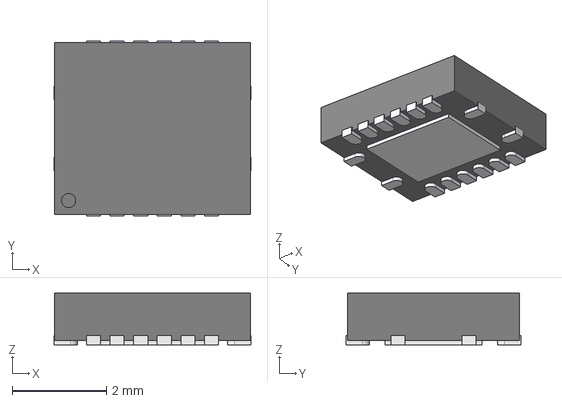
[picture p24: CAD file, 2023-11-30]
hardware/fobos-shield-Z2/cerg_3d_models/PVQFN16.step
4.17 x 3.70 x 1.10 mm

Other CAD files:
hardware/fobos-shield/cerg_3d_models/CUI_PJ-102AH.step
hardware/fobos-dut/dut-artix7-a12t-cpg238/3d models/87832-1420_stp/878321420.stp
hardware/fobos-dut/dut-artix7-a12t-cpg238/3d models/91772A106_18-8 SS PAN HEAD PHILLIPS MACHINE SCREW.STEP
hardware/fobos-dut/dut-artix7-a12t-cpg238/3d models/91780A537_ALUM FEM THRDED HEX STANDOFF.STEP
hardware/fobos-dut/dut-artix7-a12t-cpg238/3d models/BRC2012T3R3MD.STEP
hardware/fobos-dut/dut-artix7-a12t-cpg238/3d models/XA7A25T-1CPG238Q.stp
hardware/fobos-dut/dut-artix7-a12t-cpg238/3d models/keystone-PN5281.STEP
hardware/fobos-dut/dut-artix7-a12t-cpg238/3d models/keystone-PN575-8.STEP
hardware/fobos-dut/dut-artix7-a12t-cpg238/cerg_3d_models/JS202011SCQN.stp
hardware/fobos-dut/dut-artix7-a12t-cpg238/cerg_3d_models/User Library-SSOP16.step
hardware/fobos-shield-Z2/cerg_3d_models/CUI_PJ-102AH.step
hardware/fobos-shield/js202011scqn.stp

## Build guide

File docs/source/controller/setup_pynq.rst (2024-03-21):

.. _control-pynq-setup-label:

Pynq-Z1/Z2 Firmware Setup 
=========================
Below, we describe how to setup the Pynq-Z1/Z2 and the FOBOS 3.0 firmware on the Pynq board. 

Requirements
------------

#. A PC with Linux installed.
#. Python3 is installed.
#. Xilinx Vivado 2022.1 is in the search path.
#. FOBOS 3 is downloaded and unpacked on the PC (see :ref:`fobos-pc-install`).
#. Digilent Pynq-Z1/Z2 board (control board) with the PYNQ SD card image v3.0.1 installed from http://www.pynq.io/board.html.

Setup Pynq to use static IP address
-----------------------------------

    In order to connect to your Pynq board from the SCA workstation reliably, you have to make sure that 
    the Pynq board uses a static IP address. If you reserved a static IP address for your Pynq board in your 
    *dhcp* server, then you don't need to complete the following steps.

    Make sure you have a USB connection to the Pynq board and can connect 
    to it with a terminal program such as *minicom* (Linux) or *terra term* (Windows). 
    
    Connect to the Pynq board using the terminal application and edit ``/etc/network/interfaces.d/eth0``. 
    Replace the address with an available IP address on your network and the gateway with the IP address 
    of your internet gateway. 
    
    .. code-block:: 
   
        auto eth0
        iface eth0 inet dhcp
        
        auto eth0:1
        iface eth0:1 inet static
                address 192.168.2.99
                netmask 255.255.255.0
                gateway 192.168.2.1

    Next remove the existing ``resolv.conf`` as it is a symbolic link

    .. code-block:: bash
   
        sudo rm /etc/resolv.conf

    and create a new file ``resolv.conf`` that contains your favourite / company nameserver or Google's nameserver
    as shown below.

    .. code-block:: 

        nameserver 8.8.8.8

    Now restart the networking services to apply these changes.

    .. code-block:: bash

        sudo /etc/init.d/networking restart

    .. important::
        #. Make sure that the Pynq board and the SCA Workstation are connected via Ethernet and you can reach the Pynq board from the PC using ``ssh``.
        #. Make sure that the Pynq boad has the correct time. Check with the ``date`` command. The time will be in UTC which is in winter 5 hours ahead of EST and in summer 4 hours ahead of EDT. If not, probably the name resolution failed. Check if you can ``ping www.google.com``.

    Now you can remove the USB cable from the Pynq.

Install Additional Packages on Pynq
-----------------------------------

    #. Connect to the Pynq via ssh.

    #. Update the package list to get the latest available packages.

        .. code-block:: bash
   
            sudo apt-get update 
   
    #. (Optional) Install GNU Midnight Commander *mc*, a visual file manager that runs in full-screen text mode.

        .. code-block:: bash
  
            sudo apt install mc

    #. In order to run the calibration script for power measurements install the following python modules.

        .. code-block:: bash
        
            sudo pip install pyvisa
            sudo pip install pyvisa-py

Build the Pynq Overlay
----------------------

    The creation of the Pynq Overlay file for FOBOS is completely scripted and can be accomplished in just a few steps. Make sure ``vivado`` version 2022.1 is in the search path. Select the make option based on your Pynq board and the revision of the FOBOS shield as shown in :numref:`tab_makefile`.

    .. _tab_makefile:
    .. table:: Makefile options

       +-----------+-----------------------------+
       |           |       **FOBOS Shield**      |
       +-----------+--------------+--------------+
       | **Board** | **rev 1**    | **rev 2**    |
       +===========+==============+==============+
       | PYNQ Z1   | pynq_z1_rev1 | pynq_z1_rev2 |
       +-----------+--------------+--------------+
       | PYNQ Z2   | pynq_z2_rev1 | ---          |
       +-----------+--------------+--------------+
    
    #. ``cd fobos/control/pynqctrl/vivado/``
    #. ``make pynq_z2_rev1``
    #. ``make synth``
    #. Go and make yourself a cup of coffee or tea, this is going to take a while.
    #. When Vivado is done, you will have the files pynq_ctrl.bit and pynq_ctrl.hwh in the
       ``fobos/control/pynqctrl/vivado/`` directory.

Install FOBOS Firmware
----------------------

    The next step is to get the FOBOS firmware and the newly created overlay onto the Pynq Board.

    #. Start the Pynq board and make sure it completed its start-up procedure, i.e., the 4 user LEDs are flashing and then stay lit.
    #. Copy the ``fobos/software`` directory to the ``/home/xilinx/`` directory on the Pynq board 
       using scp or sftp so that the software can be found in ``/home/xilinx/fobos/software``.
    #. Copy the files ``pynq_ctrl.bit`` and ``pynq_ctrl.hwh`` from ``fobos/control/pynqctrl/vivado/`` 
       to your Pynq board into the ``/home/xilinx/fobos/software/firmware/pynq`` directory.
    #. Use ssh to get a command prompt on the Pynq board, change directory to the ``fobos/software/firmware/pynq`` 
       directory and run the script ``sudo ./install-pynq.sh``. 
       It will ask you several questions about your Pynq setup, install the necessary files, and 
       start the FOBOS server called ``pynqserver``.

       FOBOS stores its configuration in the file ``fobos/software/firmware/pynq/config/pynq_conf.py``. 

Trouble Shooting
----------------

FOBOS creates two log files in the ``/tmp`` directory of the Pynq board.

``fobos.log`` shows what the FOBOS server is doing including the commands it receives from the SCA Workstation and the corresponding responses. 

``fobos-watchdog.log`` shows the status of the FOBOS server. The watchdog restarts the FOBOS server when it becomes unresponsive.

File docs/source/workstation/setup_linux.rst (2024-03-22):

.. _fobos-linux-install:

==================
Linux Installation
==================
Below, we describe how to setup FOBOS 3.0 software and test that everything is working on Linux.

Requirements
------------
#. A PC with Ubuntu 22.04 installed.
#. FOBOS 3.0 ``fobos-v3.0.tgz`` file.
#. You must have ``sudo`` rights.

Setup Network Sharing (Optional)
--------------------------------

If your computer has two network interfaces, you can configure one to access the Internet and the other to connect to the Pynq board and maybe other instruments using a non routable IP address range. We describe here how to do this with Ubuntu 22.04.
In the example below, the network interface for the *instruments* network is ``enp2s0`` and the IP address range is ``192.168.2.1 - 192.168.255``.  You can find the names and the network information of your PC with the ``ip a show`` command. 

Create the file ``etc/netplan/20-instruments.yaml`` with the following contents and adjust the interface name and the IP address range to your requirements.

   .. code-block:: yaml
   
    network:
      ethernets:
        enp2s0:
          dhcp4: false
          addresses: [192.168.2.1/24]
      version: 2

Then apply these changes with ``sudo netplan apply``.

Edit the file ``/etc/sysclt.conf`` and uncomment ``net.ipv4.ip_forward=1`` to allow forwarding of packets between interfaces. Now apply these changes with 

   .. code-block:: bash
   
    sudo sysctl -p /etc/sysctl.conf
    sudo /etc/init.d/procps restart

Then configure iptables. Adjust the IP address range to match what you used above.

   .. code-block:: bash

    sudo iptables -A FORWARD -j ACCEPT
    sudo iptables -t nat -s 192.168.2.0/24 -A POSTROUTING -j MASQUERADE
    sudo apt-get install iptables-persistent

The last command will ask whether to apply the new rules, answer yes and then check if they are contained in the file ``/etc/iptables/rules.v4``.

Basic Downloads
---------------

Note: The following installation procedure was tested on Linux Ubuntu 22.04.

#. Download FOBOS from the `FOBOS home page <https://cryptography.gmu.edu/fobos/>`_.
#. Extract the archive into a directory of your choice

   .. code-block:: bash
   
       tar xvfz fobos-v3.0.tgz
    
   .. note::
       You can also clone FOBOS from `Github <https://github.com/GMUCERG/fobos>`_.
       Then you would skip steps 1 and 2 from above.

#. Use the following commands to install *pip* and *make*:

   .. code-block:: bash
   
       sudo apt-get install python3-pip
       sudo apt install make 

#. Enter the fobos directory and install the few necessary Python packages:

   .. code-block:: bash

       cd fobos
       sudo pip3 install -r requirements.txt

JupyterLab Installation
-----------------------

These installation instructions are based on 
`Install JupyterLab the Hard Way <https://github.com/jupyterhub/jupyterhub-the-hard-way/blob/HEAD/docs/installation-guide-hard.md>`_.

**Install JupyterHub and JupyterLab into a virtual environment**

#.  Install Python support for virtual environments.
    
    .. code-block:: bash

        sudo apt-get install python3-venv
    
#.  Create a virtual environment for JupyterHub and JupyterLab.
    
    .. code-block:: bash

        sudo python3 -m venv /opt/jupyterhub/
    
#.  Install JupyterHub and JupyterLab into this virtual environment.
    
    .. code-block:: bash

        sudo /opt/jupyterhub/bin/python3 -m pip install wheel
        sudo /opt/jupyterhub/bin/python3 -m pip install jupyterhub jupyterlab
        sudo /opt/jupyterhub/bin/python3 -m pip install ipywidgets
    
#.  Then install ``nodejs`` and ``npm`` to support the ``configurable-http-proxy`` that JupyterHub needs.
    
    .. code-block:: bash

        sudo apt install nodejs npm
        sudo npm install -g configurable-http-proxy

**Create JupyterHub configuration**

#.  Create a directory for the configuration files and generate the JupyterHub configuration file.

    .. code-block:: bash

        sudo mkdir -p /opt/jupyterhub/etc/jupyterhub/
        cd /opt/jupyterhub/etc/jupyterhub/
        sudo /opt/jupyterhub/bin/jupyterhub --generate-config

#.  Edit the config file we just created as root ``jupyterhub_config.py``
    and change the following settings.

    .. code-block:: python

        c.Spawner.notebook_dir = '~/notebooks/'     
        c.Spawner.default_url = '/lab'              

**Configure Systemd to automatically start JupyterHub**

#.  Create a folder for the systemd file

    .. code-block:: bash

        sudo mkdir -p /opt/jupyterhub/etc/systemd

#.  Then create as root the file ``/opt/jupyterhub/etc/systemd/jupyterhub.service``
    and past the following instructions into the file:

    .. code-block:: bash

       [Unit]
       Description=JupyterHub
       After=syslog.target network.target
       
       [Service]
       User=root
       Environment="PATH=/bin:/usr/local/sbin:/usr/local/bin:/usr/sbin:/usr/bin:/opt/jupyterhub/bin"
       ExecStart=/opt/jupyterhub/bin/jupyterhub -f /opt/jupyterhub/etc/jupyterhub/jupyterhub_config.py
       
       [Install]
       WantedBy=multi-user.target

#.  Link this file to the Systemd's directory

    .. code-block:: bash

        sudo ln -s /opt/jupyterhub/etc/systemd/jupyterhub.service /etc/systemd/system/jupyterhub.service

#.  Have systemd reload the configuration file

    .. code-block:: bash

        sudo systemctl daemon-reload

#.  Enable this service

    .. code-block:: bash

        sudo systemctl enable jupyterhub.service

#.  And finally start JupyterHub

    .. code-block:: bash

        sudo systemctl start jupyterhub.service

#.  You can always check if its running:

    .. code-block:: bash

        sudo systemctl status jupyterhub.service

    You can quit this status display by pressing ``q`` on the keyboard.

Conda Installation
------------------

These installation instructions are based on 
`Install JupyterLab the Hard Way <https://github.com/jupyterhub/jupyterhub-the-hard-way/blob/HEAD/docs/installation-guide-hard.md>`_.
We will use ``conda`` to manage the Python environments.

#.  Get the Anaconda public GPG key

    .. code-block:: bash

        cd 
        curl https://repo.anaconda.com/pkgs/misc/gpgkeys/anaconda.asc | gpg --dearmor > conda.gpg
        sudo install -o root -g root -m 644 conda.gpg /etc/apt/trusted.gpg.d/
        rm conda.gpg

#.  Add Debian repository

    .. code-block:: bash

        echo "deb [arch=amd64] https://repo.anaconda.com/pkgs/misc/debrepo/conda stable main" | sudo tee /etc/apt/sources.list.d/conda.list

#.  Install conda

    .. code-block:: bash

        sudo apt update
        sudo apt install conda

#.  Make conda easily available by running the setup script on login.

    .. code-block:: bash

        sudo ln -s /opt/conda/etc/profile.d/conda.sh /etc/profile.d/conda.sh

#.  Install a default conda environment for all users. 
    But first check your version of python by issuing ``python3 --version`` on the command line.
    If necessary edit the version in the code below.

    .. code-block:: bash

        sudo mkdir /opt/conda/envs/
        sudo /opt/conda/bin/conda create --prefix /opt/conda/envs/python python=3.10 ipykernel
        sudo /opt/conda/envs/python/bin/python -m ipykernel install --prefix=/opt/jupyterhub/ --name 'python' --display-name "Python (default)"

FOBOS Software Installation
---------------------------

Finally we get to install FOBOS to run in the JupyterLab we just created.

#.  Install required packages

    .. code-block:: bash

        sudo /opt/jupyterhub/bin/python3 -m pip install numpy
        sudo /opt/jupyterhub/bin/python3 -m pip install matplotlib
        sudo /opt/jupyterhub/bin/python3 -m pip install scipy
        sudo /opt/jupyterhub/bin/python3 -m pip install console-progressbar

#.  Install packages required for PDF export of Jupyter notebooks

    .. code-block:: bash

        sudo apt-get install pandoc texlive-xetex texlive-fonts-recommended 

#.  Install FOBOS into ``/opt/fobos`` by simply moving the whole directory tree.

    .. code-block:: bash

        sudo mv fobos /opt/

#.  Create notebooks folders in all users home directories and 
    copy fobos notebooks into the users notebook directories   

    .. code-block:: bash

        cd /home/username/
        mkdir -p notebooks/fobos
        cd notebooks/fobos
        cp -a /opt/fobos/software/notebooks/* .

Install DUT Support
-------------------

#.  **Chipwhisperer DUTs**

    These installation instructions are based on 
    `ChipWhisperer Linux Installation <https://chipwhisperer.readthedocs.io/en/latest/linux-install.html>`_.
    As we only want to program the DUTs we won't install everything.
    
    Create a directory for ChipWhisperer and clone it from git into this location

    .. code-block:: bash

        sudo mkdir /opt/chipwhisperer
        sudo chown $USER /opt/chipwhisperer
        cd /opt
        git clone https://github.com/newaetech/chipwhisperer

    Set the udev rules and make all users members of the corresponding groups so that they 
    can access the Chipwhisperer boards

    .. code-block:: bash

        sudo cp chipwhisperer/hardware/50-newae.rules /etc/udev/rules.d/
        sudo udevadm control --reload-rules
        sudo usermod -aG dialout $USER
        sudo usermod -aG plugdev $USER

    Repeat the last two lines for all users that have to access target boards.

    .. warning::

       If you don't have or want a *chipshisperer* group, replace *chipwhisperer* with *plugdev*
       in the file ``50-newae.rules``. Then don't add the user to the *chipwhisperer* group.

    Optional: Add the all users to the chipwhisperer group

    .. code-block:: bash

        sudo usermod -aG chipwhisperer $USER

    Add ChipWhisperer to our JupyterHub package directory and install require packages.

    .. code-block:: bash

        sudo ln -s /opt/chipwhisperer/software/chipwhisperer/ /opt/jupyterhub/lib/python3.10/site-packages/
    
    Install the additional software packages that ChipWhisperer needs

    .. code-block:: bash

        sudo /opt/jupyterhub/bin/python3 -m pip install pyusb
        sudo /opt/jupyterhub/bin/python3 -m pip install libusb1
        sudo /opt/jupyterhub/bin/python3 -m pip install pyserial
        sudo /opt/jupyterhub/bin/python3 -m pip install tqdm
        sudo /opt/jupyterhub/bin/python3 -m pip install ECPy
        sudo /opt/jupyterhub/bin/python3 -m pip install configobj

#.  **Digilent DUTs**

    FPGA boards from Digilent Inc. require the Digilent Adept tools. Download the 
    latest versions of the following packages for Linux from
    `Digilent Adept Website <https://digilent.com/shop/software/digilent-adept/>`_ 
    and install them.
    
    - Adept for Linux Runtime 
    - Adept Utilities 

    Make sure that all users are members of the correct groups.

    .. code-block:: bash

        sudo usermod -aG dialout $USER
        sudo usermod -aG plugdev $USER

Install Oscilloscope Support
----------------------------

**PicoScope**

Go to the `Pico Tech Download page <https://www.picotech.com/downloads>`_ and select the 
latest version of PicoScope for your operating system. Follow the instructions on their 
webpage to install it.

In order for FOBOS to use a PicoSope you also have to install the Pico SDK.   
Create a directory ``sdk`` in your ``/opt/picoscope`` directory and give it your user 
rights.

.. code-block:: bash

    sudo mkdir /opt/picoscope/sdk
    sudo chown $USER /opt/picoscope/sdk
    cd !$

Clone the Pico SDK into this directory and install it.

.. code-block:: bash

    git clone https://github.com/picotech/picosdk-python-wrappers.git
    cd picosdk-python-wrappers
    sudo /opt/jupyterhub/bin/python3 -m pip install .

Now the SCA Workstation should be ready.

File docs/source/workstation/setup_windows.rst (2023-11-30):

.. _fobos-windows-install:

====================
Windows Installation
====================
Below, we describe how to setup FOBOS 3.0 software and test that everything is working on Windows.

Requirements
------------
#. A PC with Windows 10 installed.
#. FOBOS 3.0 ``fobos-v3.0.zip`` file.
#. You must be able to obtain Administrator rights.

Basic Downloads
---------------

Note: The following installation procedure is not fully tested on Windows 10.

#. Download FOBOS from the `FOBOS home page <https://cryptography.gmu.edu/fobos/>`_.
#. Extract the archive into the directory of your choice

Install Python
--------------

#.  Download git for windows from https://git-scm.com/downloads
    and install with default options.

#.  Download WinPython 3.8 from https://winpython.github.io/
    and install (uncompress) it on the PC into ``C:\Users\username\WinPython``.

#.  Execute the program ``WinPython Control Panel`` and 
    select *Advanced->Register distribution* from the menu.
    However, you still have to manually add the path to where the python executable is to the system path.
    Check online on how to do this for your windows version.

#.  Configure your *git bash* to find python by adding its location to a ``.bashrc`` file. Start *git bash* 
    and enter:

    .. code-block:: bash

        alias python='winpty /c/Users/username/winPython/pypy3.8-v7.3.9-win64/python.exe    

    Please replace **username** with your username and **pypy3.8-v7.3.9-win64** with the directory name in your installation.

#.  Reboot Windows.

Install FOBOS
-------------

#.  Extract ``fobos-v3.0.zip`` into ``C:\Users\username\``.

#.  Open the command shell ``cmd`` as Administrator. In windows only an Administrator can set symbolic links.
    Execute the following commands.

    .. code-block:: cmd

        cd C:\Users\username
        cd fobos\software\notebooks
        del foboslib
        mklink /D foboslib ..\foboslib
        
        cd sca_labs
        del foboslib
        mklink /D foboslib ..\..\foboslib
        
        cd C:\Users\username\WinPython\notebooks
        mklink /D fobos ..\..\fobos\software\notebooks

#.  Now you should be able to execute ``Jupyter Lab.exe`` from your ``C:\Users\username\WinPython``
    directory. Be patient, it will take a while to fully start up. It will open your default web browser with the 
    JupyterLab Launcher. In the folder browser on the left will be a ``fobos`` folder containing the FOBOS 
    Jupyter notebooks.

Install DUT Support
-------------------

To be described

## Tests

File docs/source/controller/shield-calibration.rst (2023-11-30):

.. _power-calibration:

Power Calibration
-----------------

These steps explain how to calibrate the power measurement facilities of the FOBOS Shield. 

Power calibration requires that the SCA workstation, the Pynq Board and a Rigol DL3021A DC load are on the same network. The DC load should be on and the load function should be switched on. 

Use a webbrowser on the SCA workstation and connect to your Pynq board, e.g. http://192.168.2.99. 

Go to the *fobos* folder and start the *power_calibration.pynb* notebook.
Verify that the IP address for the DC load in the first cell is correct. If you want to use a different DC load, you have to edit the SCPI commands.

Execute the first cell. This takes a while the first time it is run.

Make sure that you connect the wires from the load as well as the sense wires to the power sources on the FOBOS shield as prompted by the script.

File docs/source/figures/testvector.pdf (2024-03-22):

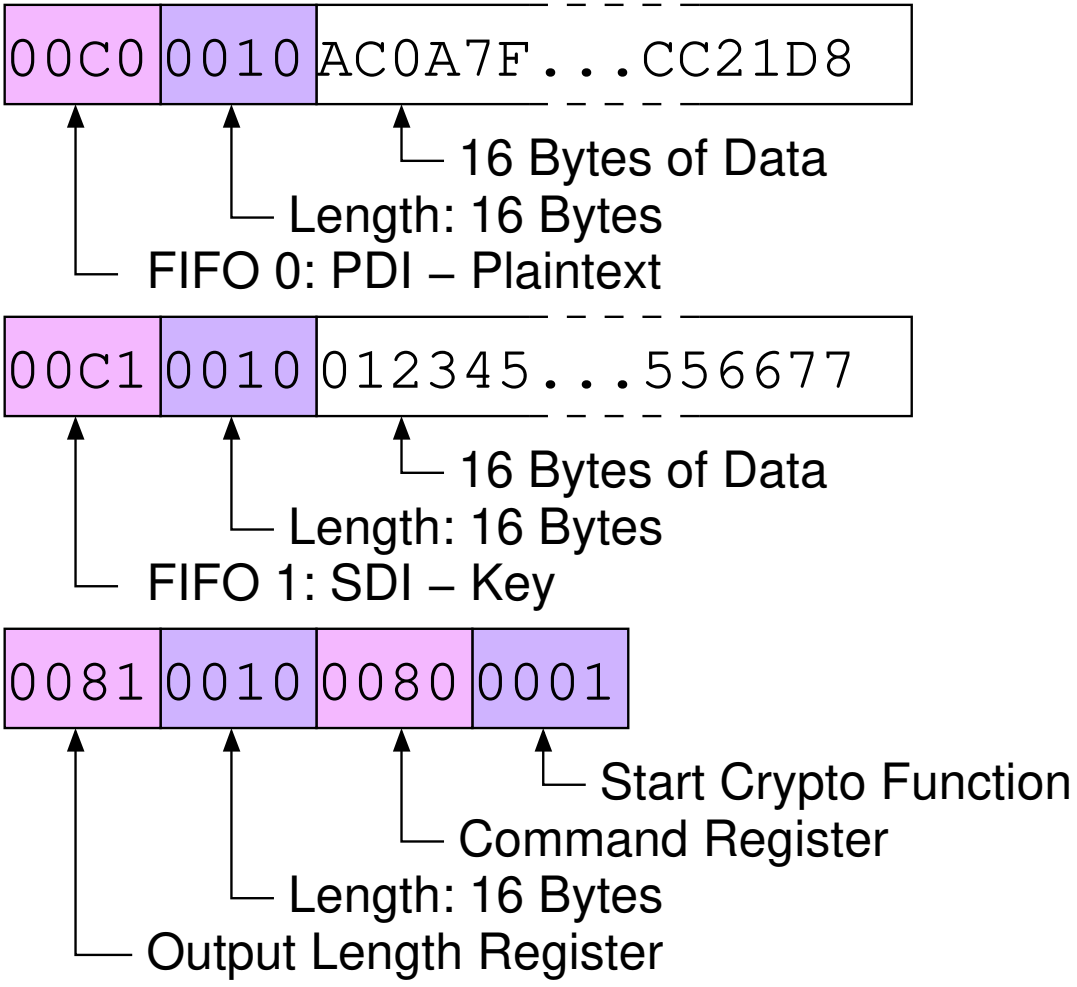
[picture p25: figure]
Length: 16 Bytes; 16 Bytes of Data; FIFO 1: SDI − Key; Output Length Register; Command Register; Start Crypto Function; FIFO 0: PDI − Plaintext

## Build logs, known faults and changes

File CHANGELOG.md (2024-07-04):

# Changelog

All notable changes to this project will be documented in this file.

## [3.0.1]
### Notes
This release fixes several small bugs and enhances usability.

### Added

- [CHANGELOG.md](CHANGELOG.md)
- MTDs of each key byte are now written into a file, they don't have to be guessed from graphs anymore

### Changed

- Substantial documentation updates and improvements
- Power calibration works again (was working on beta versions of FOBOS 3)
- Updated fobosTVGen to handle more FIFOs
- XILINX_XRT environment variable on Pynq was not set correctly
- Pynq install script now detects which Pynq board it is running on
- FOBOS can now set fixed amplification on the amplifier of the FOBOS Shield using ADC_hilo
- Improved Makefile for building the Pynq overlay for Pynq-Z1 and Pynq-Z2, and different revisions of the FOBOS Shield

### Removed
- Nothing.

## [3.0.0] 
Initial release.

[3.0.1]: https://github.com/GMUCERG/FOBOS/compare/v3.0.0...v3.0.1
[3.0.0]: https://github.com/GMUCERG/FOBOS/releases/tag/v3.0.0

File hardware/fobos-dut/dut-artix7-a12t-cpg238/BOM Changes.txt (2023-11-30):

Changes to Artix 7 dut BOM

-1 100uF 1210 Capacitor C25
+1 4.7uF 0402 Capacitor C25

-1 2.2uF 0603 Capacitor C15
+1 2.2uF 0805 Capacitor C15

-1 470nF 0402 Capacitor C47
+4 47uF 0603 Capacitor C37, C39, C47, C55 

-1 470nF 0402 Capacitor C48
+1 4.7uF 0402 Capacitor C48

-1 470nF 0402 Capacitor C49
+1 4.7uF 0402 Capacitor C49

-1 4.7uF 0402 Capacitor C29, C36, C37, C38, C39
+2 4.7uF 0402 Capacitor C26, C27
+3 470nF 0402 Capacitor C29, C36, C56

+1 100uF 1210 Capacitor C38

-2 47uF 0603 Capacitor C26,C27

-2 47uF 0603 Capacitor C7, C35
+1 47uF 0805 Capacitor C7
+1 470nF 0402 Capacitor C35

+2 100nF 0603 Capacitor C57, C58

+1 MMBT3904 Transistor Q8

+2 SP3003-04ATG U10, U11

-1 SMA EDGE J9
+1 SMA VERTICAL J9

-1 1825910-6 S6
+1 1825910-6 S3

+2 10k 0603 resistor R73, R74

+2 0.1 0805 resistor R75, R76

+2 1k 0603 resistor R77, R78

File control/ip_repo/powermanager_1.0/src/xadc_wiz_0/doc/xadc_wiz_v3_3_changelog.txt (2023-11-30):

2016.1:
 * Version 3.3
 * Added DDR3 voltage levels for VCCDDRO Alarm.
 * Enabled ADC Offset and Gain Calibration and the Sensor Offset and Gain Calibration enabled by default.

2015.4.2:
 * Version 3.2
 * No changes

2015.4.1:
 * Version 3.2
 * No changes

2015.4:
 * Version 3.2
 * No changes

2015.3:
 * Version 3.2
 * Corrected the Alarm limits for VCCINT and VCCBRAM for -1L speedgrade devices.
 * IP revision number added to HDL module, library, and include file names, to support designs with both locked and upgraded IP instances
 * IP delivers only Verilog example design files.

2015.2.1:
 * Version 3.1
 * No changes

2015.2:
 * Version 3.1
 * Corrected the Alarm limits for VCCINT and VCCBRAM for -2L speedgrade devices.

2015.1:
 * Version 3.0 (Rev. 7)
 * GUI Updates, no functional changes

2014.4.1:
 * Version 3.0 (Rev. 6)
 * No changes

2014.4:
 * Version 3.0 (Rev. 6)
 * Internal device family change, no functional changes

2014.3:
 * Version 3.0 (Rev. 5)
 * Added EXTERNAL_MUXADDR_ENABLE parameter to enable MUXADDR used for Dynamic Configuration for external mux mode
 * SIN, TRIANGLE and SQUARE stimulus generation in the range 0.1 KHz to 96 KHz. CSV file format to txt file conversion for simulation.

2014.2:
 * Version 3.0 (Rev. 4)
 * Fixed issue with VCCBRAM channel enablement in INIT_48 for sequencer mode

2014.1:
 * Version 3.0 (Rev. 3)
 * Internal device family name change, no functional changes
 * Corrected GUI enablement option in Default sequencer mode

2013.4:
 * Version 3.0 (Rev. 2)
 * No changes

2013.3:
 * Version 3.0 (Rev. 2)
 * Updated AXI4 Streaming FIFO depth from [1:1017] to [7:1020]
 * Added check to disable invalid Vauxp/Vauxn pairs for x*7z010clg225 Zynq device
 * Defined Vp/Vn and Vauxp/Vauxn as bus interfaces, no functional change
 * Added option in GUI to provide relative path for sim file, no functional change
 * Added a summary tab in the GUI, no functional change
 * Added support for Cadence IES and Synopsys VCS simulators
 * Reduced warnings in synthesis and simulation
 * Enhanced support for IP Integrator

2013.2:
 * Version 3.0 (Rev. 1)
 * Fixed CRITICAL WARNING for clock constraints on DCLK
 * Updated Life-Cycle status of devices

2013.1:
 * Version 3.0
 * Lower case ports for Verilog
 * Added AXI4STREAM interface support

(c) Copyright 2011 - 2016 Xilinx, Inc. All rights reserved.

This file contains confidential and proprietary information
of Xilinx, Inc. and is protected under U.S. and
international copyright and other intellectual property
laws.

DISCLAIMER
This disclaimer is not a license and does not grant any
rights to the materials distributed herewith. Except as
otherwise provided in a valid license issued to you by
Xilinx, and to the maximum extent permitted by applicable
law: (1) THESE MATERIALS ARE MADE AVAILABLE "AS IS" AND
WITH ALL FAULTS, AND XILINX HEREBY DISCLAIMS ALL WARRANTIES
AND CONDITIONS, EXPRESS, IMPLIED, OR STATUTORY, INCLUDING
BUT NOT LIMITED TO WARRANTIES OF MERCHANTABILITY, NON-
INFRINGEMENT, OR FITNESS FOR ANY PARTICULAR PURPOSE; and
(2) Xilinx shall not be liable (whether in contract or tort,
including negligence, or under any other theory of
liability) for any loss or damage of any kind or nature
related to, arising under or in connection with these
materials, including for any direct, or any indirect,
special, incidental, or consequential loss or damage
(including loss of data, profits, goodwill, or any type of
loss or damage suffered as a result of any action brought
by a third party) even if such damage or loss was
reasonably foreseeable or Xilinx had been advised of the
possibility of the same.

CRITICAL APPLICATIONS
Xilinx products are not designed or intended to be fail-
safe, or for use in any application requiring fail-safe
performance, such as life-support or safety devices or
systems, Class III medical devices, nuclear facilities,
applications related to the deployment of airbags, or any
other applications that could lead to death, personal
injury, or severe property or environmental damage
(individually and collectively, "Critical
Applications"). Customer assumes the sole risk and
liability of any use of Xilinx products in Critical
Applications, subject only to applicable laws and
regulations governing limitations on product liability.

THIS COPYRIGHT NOTICE AND DISCLAIMER MUST BE RETAINED AS
PART OF THIS FILE AT ALL TIMES.

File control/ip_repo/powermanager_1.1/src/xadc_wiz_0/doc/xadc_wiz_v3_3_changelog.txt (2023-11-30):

2020.2:
 * Version 3.3 (Rev. 8)
 * No changes

2020.1.1:
 * Version 3.3 (Rev. 8)
 * No changes

2020.1:
 * Version 3.3 (Rev. 8)
 * General: New Device support. No effect.

2019.2.2:
 * Version 3.3 (Rev. 7)
 * No changes

2019.2.1:
 * Version 3.3 (Rev. 7)
 * No changes

2019.2:
 * Version 3.3 (Rev. 7)
 * General: New Device support. No effect.

2019.1.3:
 * Version 3.3 (Rev. 6)
 * No changes

2019.1.2:
 * Version 3.3 (Rev. 6)
 * No changes

2019.1.1:
 * Version 3.3 (Rev. 6)
 * No changes

2019.1:
 * Version 3.3 (Rev. 6)
 * No changes

2018.3.1:
 * Version 3.3 (Rev. 6)
 * No changes

2018.3:
 * Version 3.3 (Rev. 6)
 * General: Minor changes in attributes. No effect.

2018.2:
 * Version 3.3 (Rev. 5)
 * No changes

2018.1:
 * Version 3.3 (Rev. 5)
 * No changes

2017.4:
 * Version 3.3 (Rev. 5)
 * General: Added aspartan7 support for this IP

2017.3:
 * Version 3.3 (Rev. 4)
 * Bug Fix: Fixed range of ADC conversion rate

2017.2:
 * Version 3.3 (Rev. 3)
 * No changes

2017.1:
 * Version 3.3 (Rev. 3)
 * Bug Fix: Fixed the ADC conversion rate calculation.

2016.4:
 * Version 3.3 (Rev. 2)
 * General: VREFP register value updated.

2016.3:
 * Version 3.3 (Rev. 1)
 * Bug Fix: Updated the voltage alarm ranges.
 * Other: Added support for Spartan7 devices.

2016.2:
 * Version 3.3
 * No changes

2016.1:
 * Version 3.3
 * Added DDR3 voltage levels for VCCDDRO Alarm.
 * Enabled ADC Offset and Gain Calibration and the Sensor Offset and Gain Calibration enabled by default.

2015.4.2:
 * Version 3.2
 * No changes

2015.4.1:
 * Version 3.2
 * No changes

2015.4:
 * Version 3.2
 * No changes

2015.3:
 * Version 3.2
 * Corrected the Alarm limits for VCCINT and VCCBRAM for -1L speedgrade devices.
 * IP revision number added to HDL module, library, and include file names, to support designs with both locked and upgraded IP instances
 * IP delivers only Verilog example design files.

2015.2.1:
 * Version 3.1
 * No changes

2015.2:
 * Version 3.1
 * Corrected the Alarm limits for VCCINT and VCCBRAM for -2L speedgrade devices.

2015.1:
 * Version 3.0 (Rev. 7)
 * GUI Updates, no functional changes

2014.4.1:
 * Version 3.0 (Rev. 6)
 * No changes

2014.4:
 * Version 3.0 (Rev. 6)
 * Internal device family change, no functional changes

2014.3:
 * Version 3.0 (Rev. 5)
 * Added EXTERNAL_MUXADDR_ENABLE parameter to enable MUXADDR used for Dynamic Configuration for external mux mode
 * SIN, TRIANGLE and SQUARE stimulus generation in the range 0.1 KHz to 96 KHz. CSV file format to txt file conversion for simulation.

2014.2:
 * Version 3.0 (Rev. 4)
 * Fixed issue with VCCBRAM channel enablement in INIT_48 for sequencer mode

2014.1:
 * Version 3.0 (Rev. 3)
 * Internal device family name change, no functional changes
 * Corrected GUI enablement option in Default sequencer mode

2013.4:
 * Version 3.0 (Rev. 2)
 * No changes

2013.3:
 * Version 3.0 (Rev. 2)
 * Updated AXI4 Streaming FIFO depth from [1:1017] to [7:1020]
 * Added check to disable invalid Vauxp/Vauxn pairs for x*7z010clg225 Zynq device
 * Defined Vp/Vn and Vauxp/Vauxn as bus interfaces, no functional change
 * Added option in GUI to provide relative path for sim file, no functional change
 * Added a summary tab in the GUI, no functional change
 * Added support for Cadence IES and Synopsys VCS simulators
 * Reduced warnings in synthesis and simulation
 * Enhanced support for IP Integrator

2013.2:
 * Version 3.0 (Rev. 1)
 * Fixed CRITICAL WARNING for clock constraints on DCLK
 * Updated Life-Cycle status of devices

2013.1:
 * Version 3.0
 * Lower case ports for Verilog
 * Added AXI4STREAM interface support

(c) Copyright 2011 - 2020 Xilinx, Inc. All rights reserved.

This file contains confidential and proprietary information
of Xilinx, Inc. and is protected under U.S. and
international copyright and other intellectual property
laws.

DISCLAIMER
This disclaimer is not a license and does not grant any
rights to the materials distributed herewith. Except as
otherwise provided in a valid license issued to you by
Xilinx, and to the maximum extent permitted by applicable
law: (1) THESE MATERIALS ARE MADE AVAILABLE "AS IS" AND
WITH ALL FAULTS, AND XILINX HEREBY DISCLAIMS ALL WARRANTIES
AND CONDITIONS, EXPRESS, IMPLIED, OR STATUTORY, INCLUDING
BUT NOT LIMITED TO WARRANTIES OF MERCHANTABILITY, NON-
INFRINGEMENT, OR FITNESS FOR ANY PARTICULAR PURPOSE; and
(2) Xilinx shall not be liable (whether in contract or tort,
including negligence, or under any other theory of
liability) for any loss or damage of any kind or nature
related to, arising under or in connection with these
materials, including for any direct, or any indirect,
special, incidental, or consequential loss or damage
(including loss of data, profits, goodwill, or any type of
loss or damage suffered as a result of any action brought
by a third party) even if such damage or loss was
reasonably foreseeable or Xilinx had been advised of the
possibility of the same.

CRITICAL APPLICATIONS
Xilinx products are not designed or intended to be fail-
safe, or for use in any application requiring fail-safe
performance, such as life-support or safety devices or
systems, Class III medical devices, nuclear facilities,
applications related to the deployment of airbags, or any
other applications that could lead to death, personal
injury, or severe property or environmental damage
(individually and collectively, "Critical
Applications"). Customer assumes the sole risk and
liability of any use of Xilinx products in Critical
Applications, subject only to applicable laws and
regulations governing limitations on product liability.

THIS COPYRIGHT NOTICE AND DISCLAIMER MUST BE RETAINED AS
PART OF THIS FILE AT ALL TIMES.

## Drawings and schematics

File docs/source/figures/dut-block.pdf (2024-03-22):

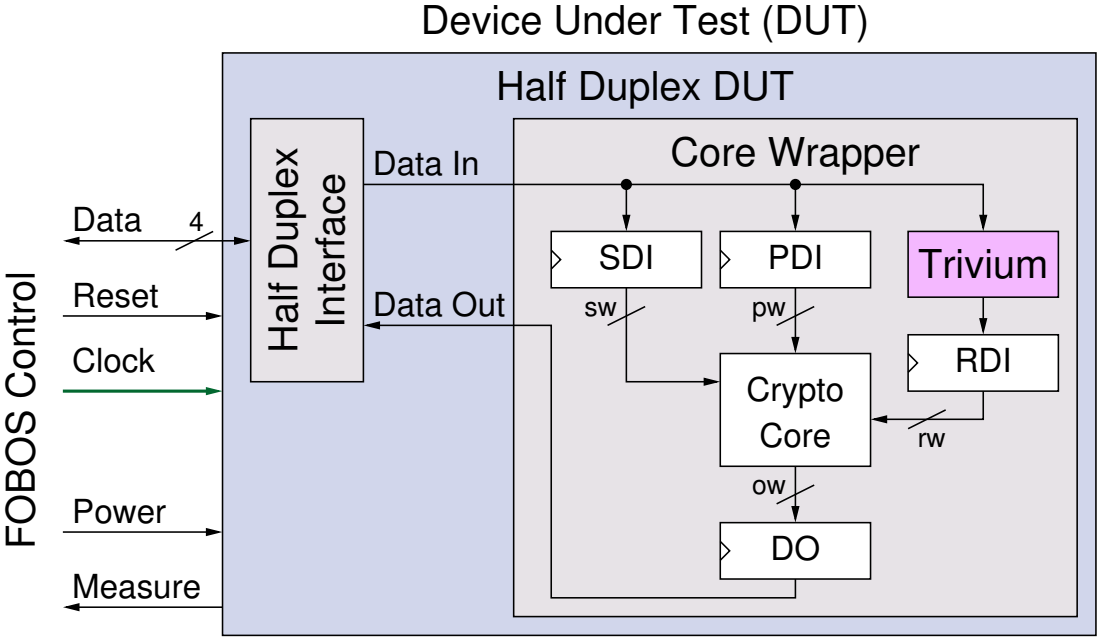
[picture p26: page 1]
Interface; Half Duplex; Core Wrapper; Data Out; Data In; Measure; Power; Data; FOBOS Control; Reset; Clock; SDI; PDI; RDI; Trivium; Core; Crypto

Device Under Test (DUT)
Half Duplex DUT

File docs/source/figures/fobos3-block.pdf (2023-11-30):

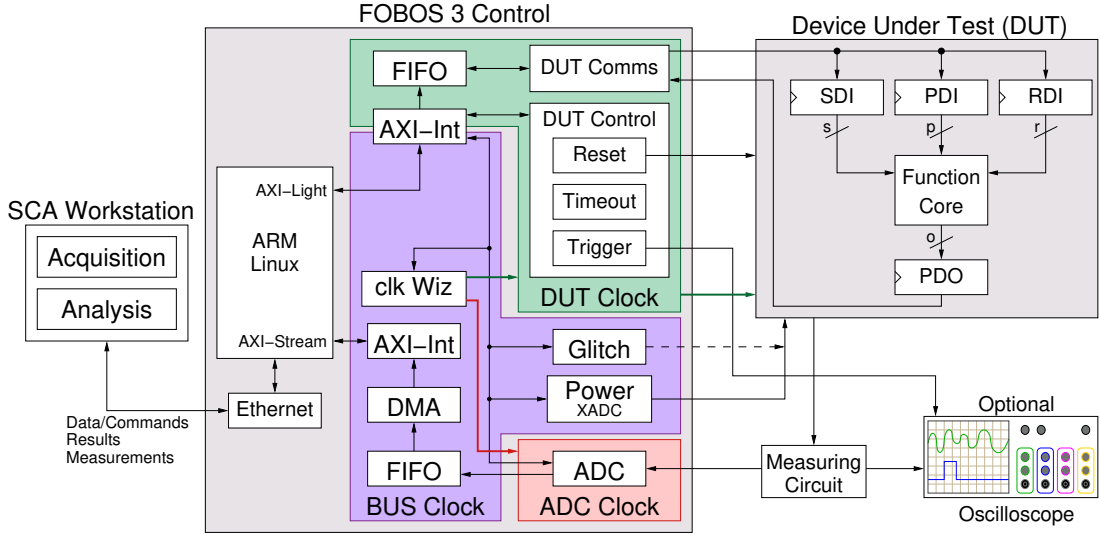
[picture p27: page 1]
DMA; XADC; Power; ADC; clk Wiz; AXI−Int; FIFO; Glitch; Acquisition; Analysis; SCA Workstation; BUS Clock; ADC Clock; AXI−Light; AXI−Stream; DUT Clock; Data/Commands Results Measurements; FOBOS 3 Control; Timeout; Reset; Trigger; SDI; Measuring Circuit; PDI; RDI; Core; Function; PDO; Ethernet; DUT Control; DUT Comms; ARM Linux; Optional; Oscilloscope

Device Under Test (DUT)

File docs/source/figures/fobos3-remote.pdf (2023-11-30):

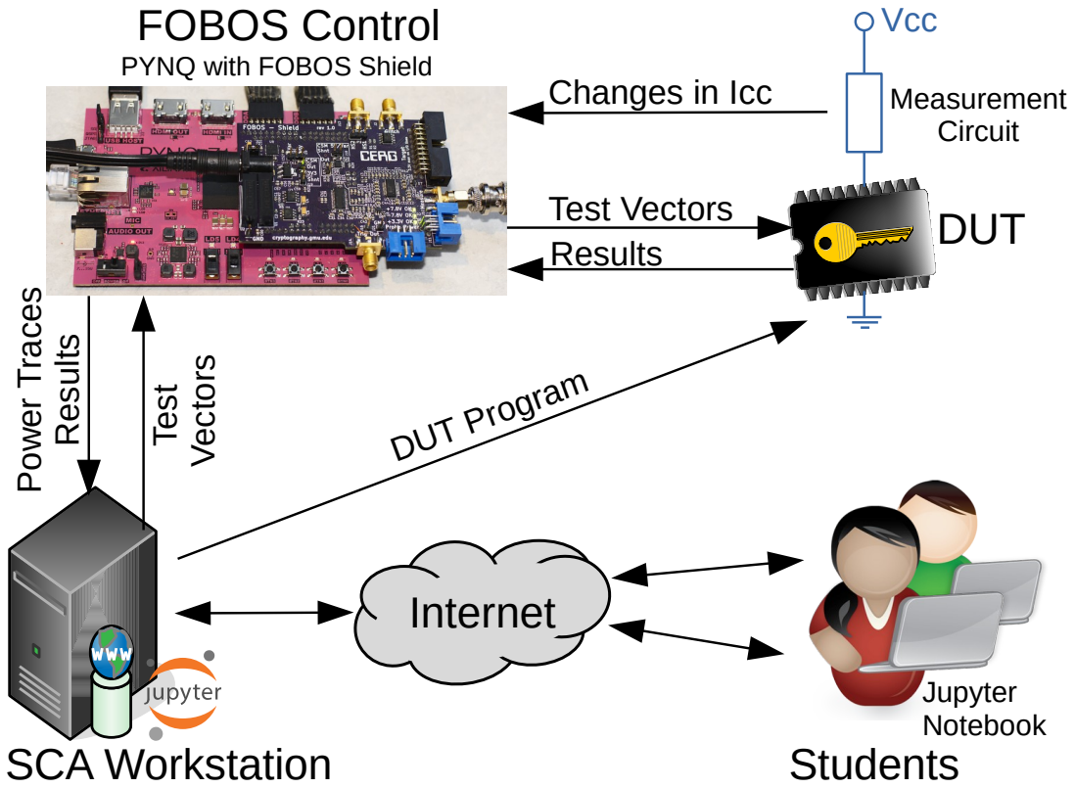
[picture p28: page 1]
Internet; Test Vectors Results; SCA Workstation; DUT; Vcc; ctors; er Tra; ults; Measurement Circuit; Jupyter Notebook Students; DUT Program

FOBOS Control
PYNQ with FOBOS Shield

Changes in Icc

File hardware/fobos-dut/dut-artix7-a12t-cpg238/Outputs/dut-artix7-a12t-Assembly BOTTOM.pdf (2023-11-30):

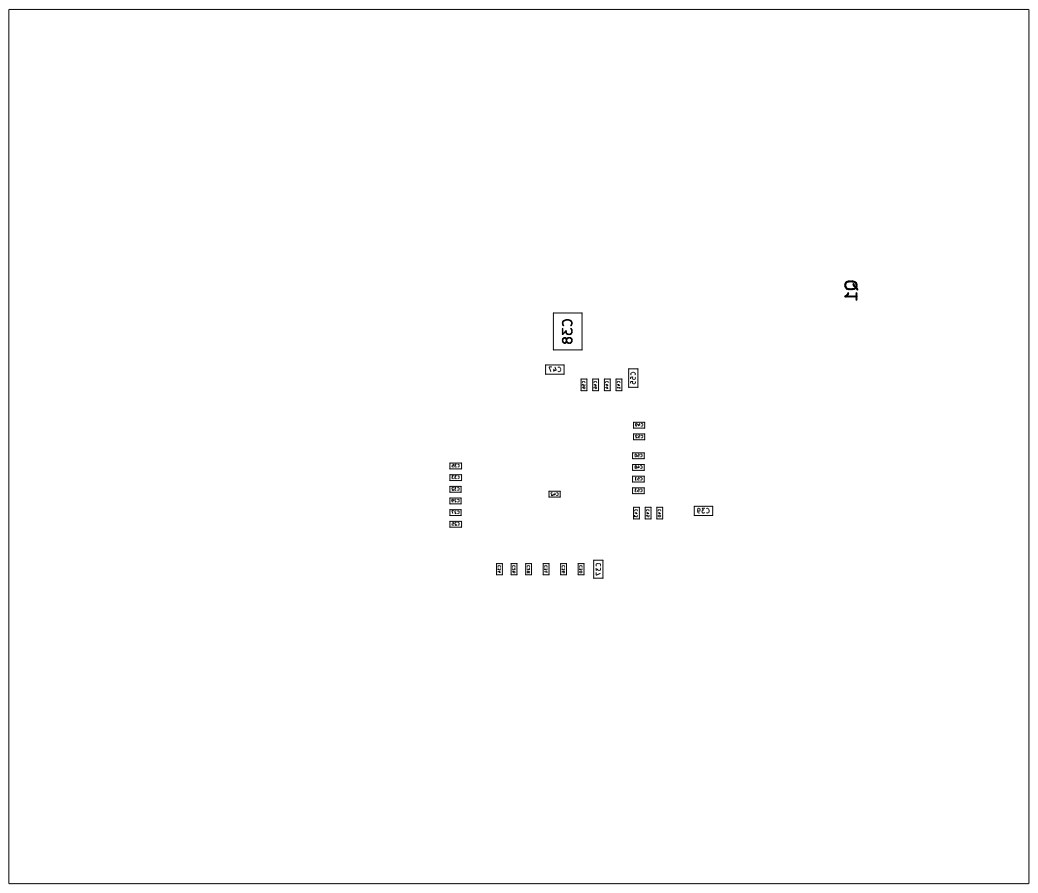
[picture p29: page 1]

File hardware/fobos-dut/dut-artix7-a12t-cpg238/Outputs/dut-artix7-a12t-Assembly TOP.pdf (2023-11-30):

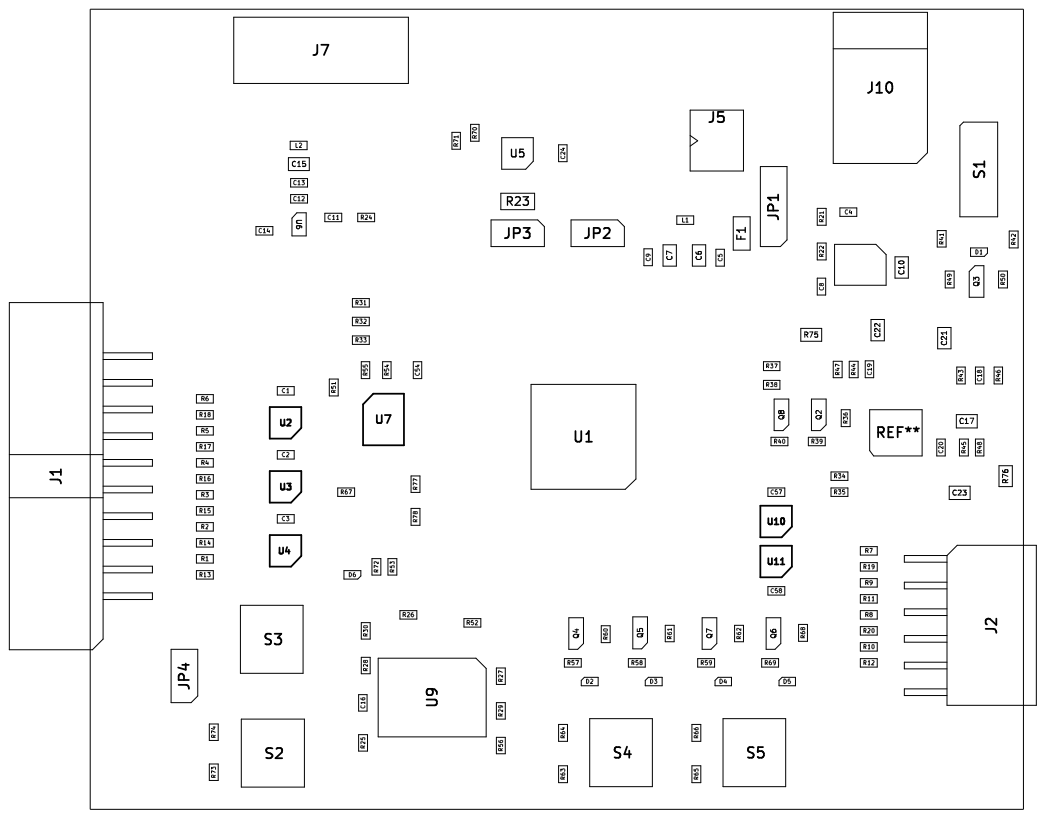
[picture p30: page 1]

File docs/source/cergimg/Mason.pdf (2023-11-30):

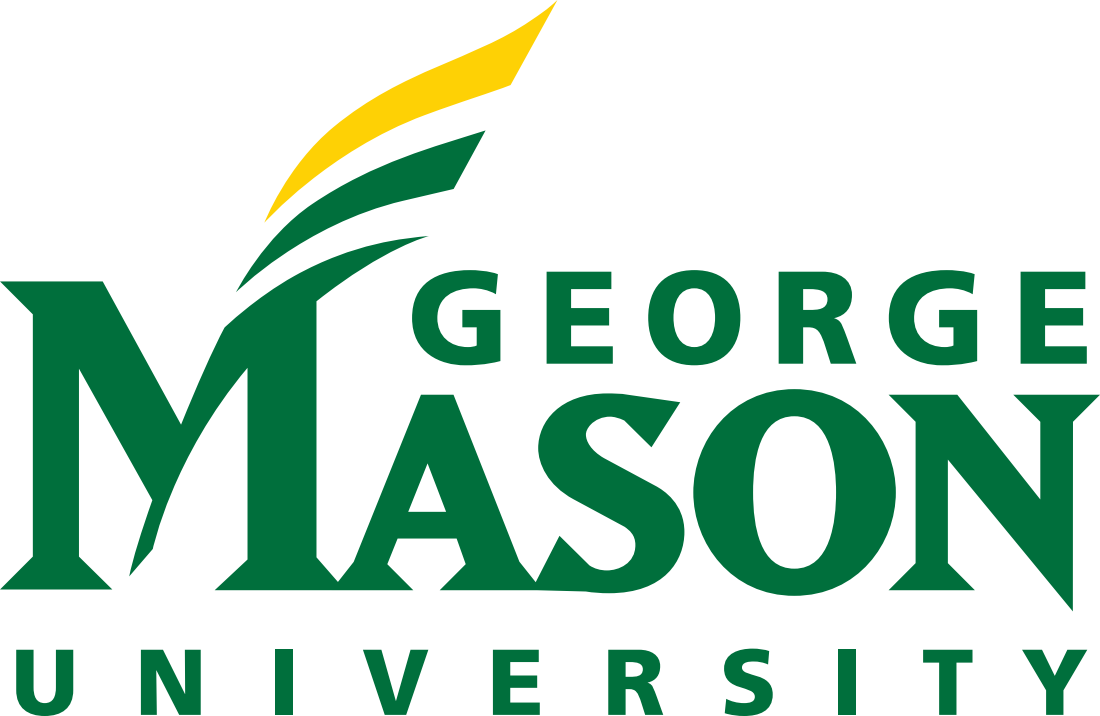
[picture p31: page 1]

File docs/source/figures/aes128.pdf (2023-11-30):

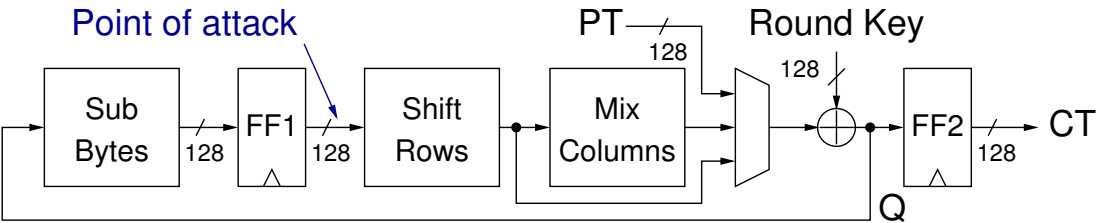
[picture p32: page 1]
Sub; Bytes; Columns; Shift; Mix; Rows; Round Key

Point of attack

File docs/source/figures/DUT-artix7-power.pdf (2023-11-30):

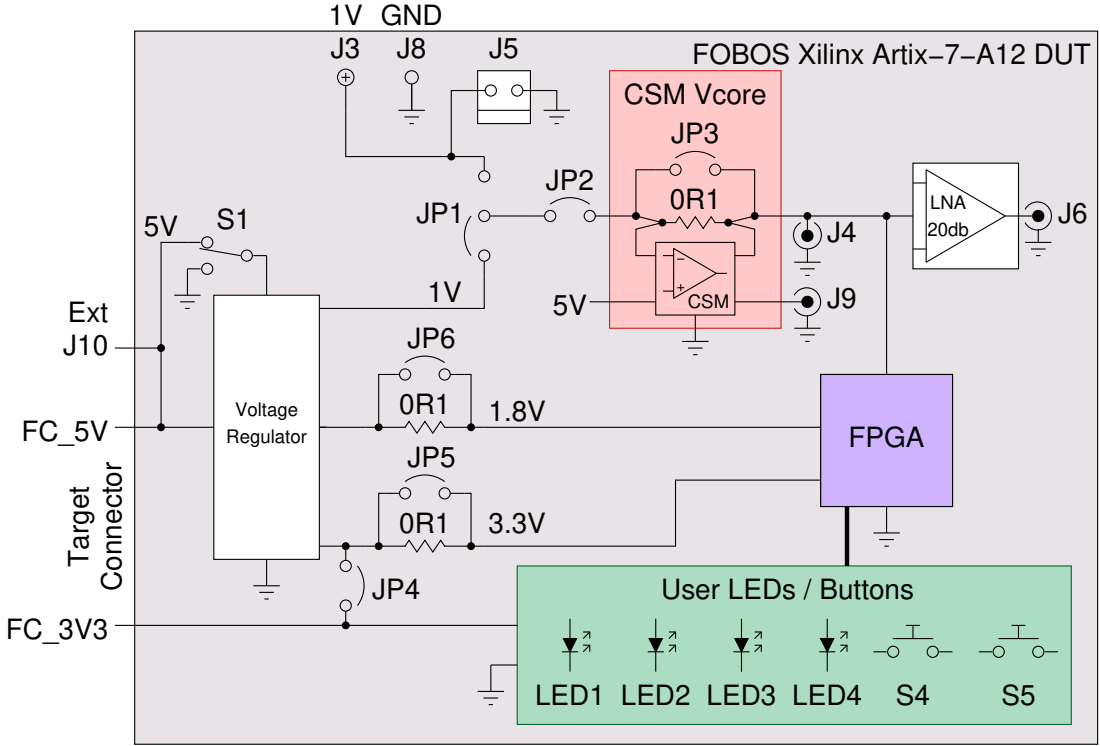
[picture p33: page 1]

FOBOS Xilinx Artix−7−A12 DUT
CSM Vcore

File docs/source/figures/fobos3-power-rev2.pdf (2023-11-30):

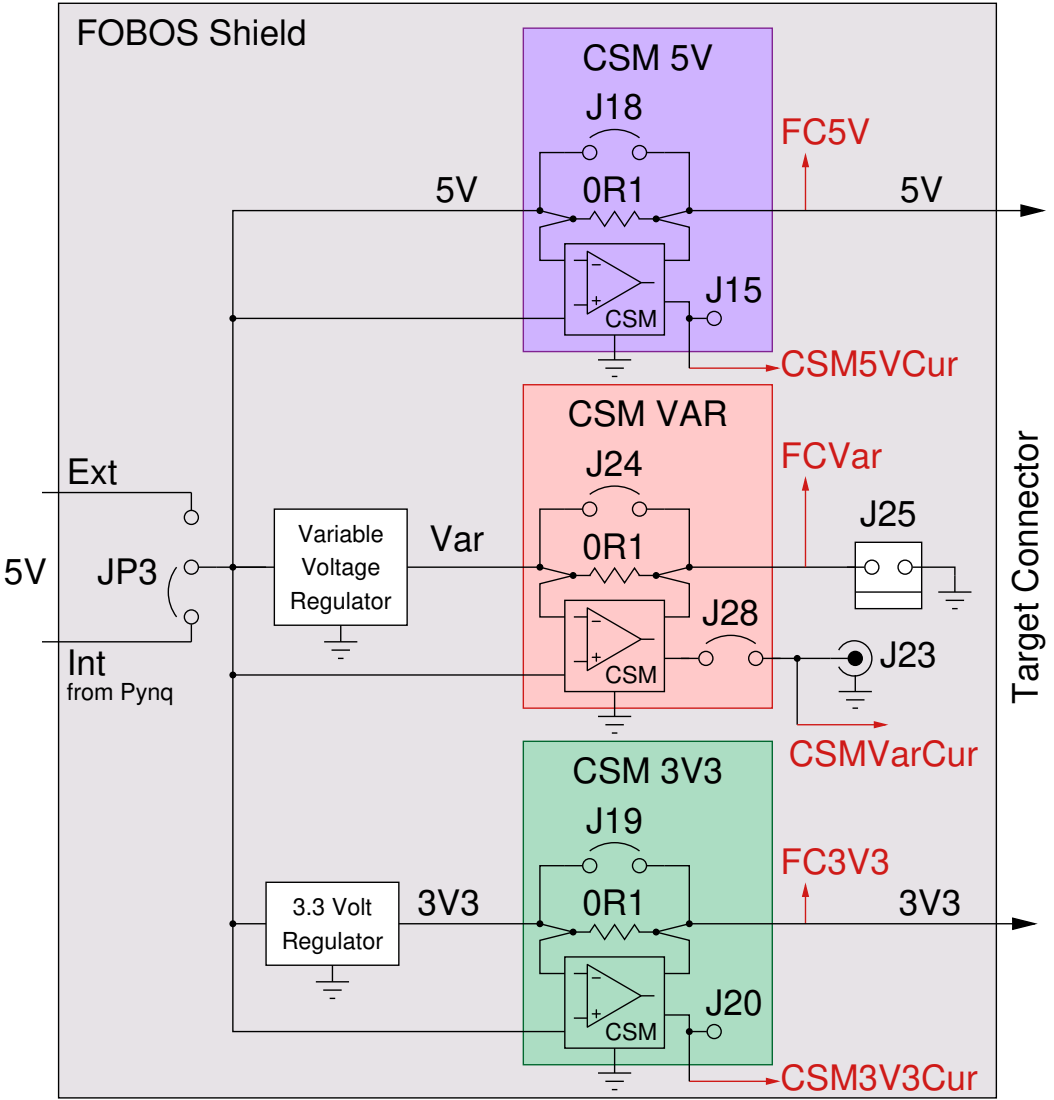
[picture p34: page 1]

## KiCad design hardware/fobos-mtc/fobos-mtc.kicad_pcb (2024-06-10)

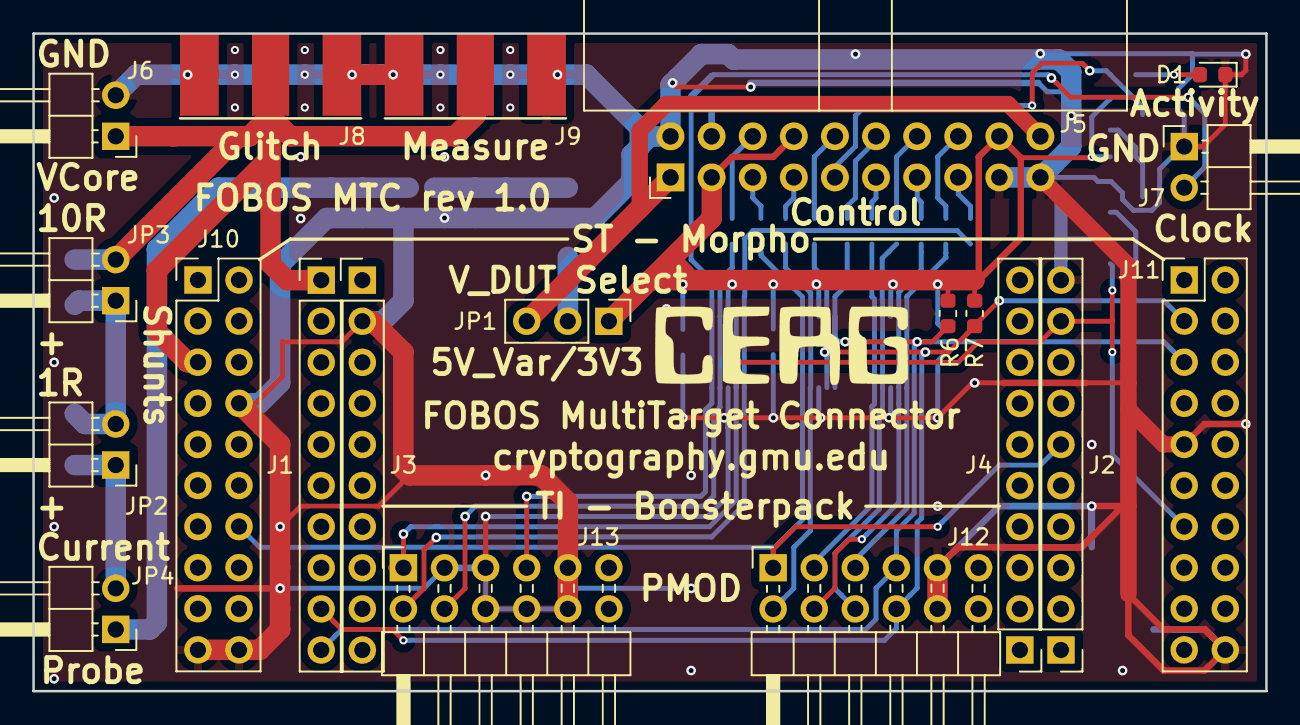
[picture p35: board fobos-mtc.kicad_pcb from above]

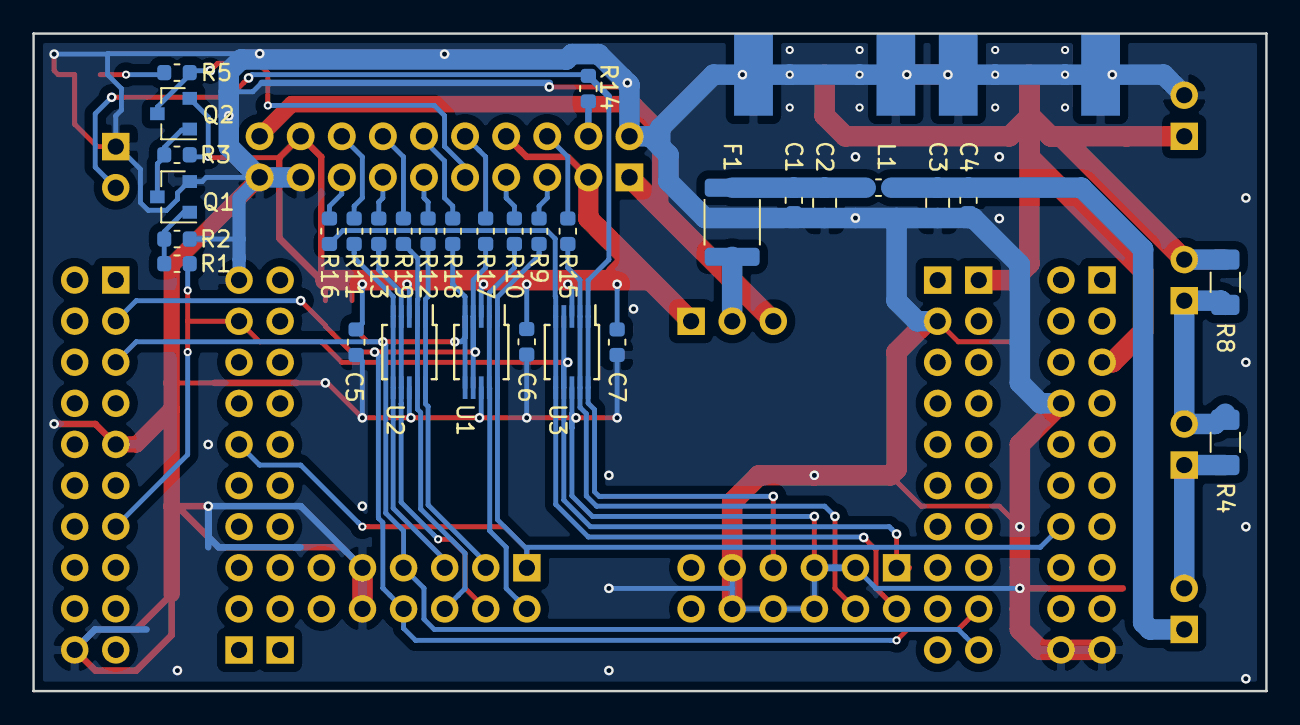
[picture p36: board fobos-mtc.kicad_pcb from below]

Board: 2 copper layers, 76.2 x 40.6 mm, 51 parts (31 on the bottom side), 36 nets.

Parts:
C1, C4, C5, C6, C7: 100nF; C_0603_1608Metric
C2: 10uF; C_0805_2012Metric
C3: 47uF6.3V; C_0805_2012Metric
D1: Activity; LED_0603_1608Metric
F1: MF-MSMF050-2; Fuse_1812_4532Metric
J1, J2, J3, J4: Conn_01x10; PinHeader_1x10_P2.54mm_Vertical
J5: Target; IDC-Header_2x10_P2.54mm_Horizontal
J6: Conn_01x02; PinHeader_1x02_P2.54mm_Horizontal
J7: clk; PinHeader_1x02_P2.54mm_Horizontal
J8: Glitch; SMA-JOHNSON-142-0701-801
J9: Measure; SMA-JOHNSON-142-0701-801
J10, J11: Conn_02x10_Odd_Even; PinSocket_2x10_P2.54mm_Vertical-flipped
J12, J13: Conn_02x06_Top_Bottom; PinHeader_2x06_P2.54mm_Horizontal-flipped
JP1: Source; PinHeader_1x03_P2.54mm_Vertical
JP2: Shunt1R; PinHeader_1x02_P2.54mm_Horizontal
JP3: Shunt10R; PinHeader_1x02_P2.54mm_Horizontal
JP4: CurProbe; PinHeader_1x02_P2.54mm_Horizontal
L1: 1k/500mA; L_0603_1608Metric
Q1: BSS138; SOT-23
Q2: BSS84; SOT-23
R1, R9, R10, R11, R12, R13, R14, R15, R16, R17, R18, R19: 22R; R_0603_1608Metric
R2, R3, R6, R7: 10k; R_0603_1608Metric
R4: 1R; R_1206_3216Metric
R5: 470R; R_0603_1608Metric
R8: 10R; R_1206_3216Metric
U1, U2, U3: SP3003-04ATG; MSOP-10_3x3mm_P0.5mm

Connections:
/dutconnect/CV_RST: J5.5, R9.1
/dutconnect/CW_HS1: J5.4, R14.2
/dutconnect/CW_HS2: J5.6, R15.2
/dutconnect/CW_MISO: J5.7, R10.1
/dutconnect/CW_PDIC: J5.13, R13.1
/dutconnect/CW_PDID: J5.15, R16.1
/dutconnect/CW_SCK: J5.11, R12.1
/dutconnect/CW_TARG1: J5.10, R17.2
/dutconnect/CW_TARG2: J5.12, R18.2
/dutconnect/CW_TARG3: J5.14, R19.2
/dutconnect/CW_TARG4: J5.16, R11.2
Aux: J13.7, R16.2, U3.5, U3.6
CLK_C2D: J13.8, R15.1, U3.2, U3.9
CLK_D2C: J7.2, J13.4, R14.1, U3.1, U3.10
CW_3V3: C5.1, C6.1, C7.1, J5.3, J5.8, J5.18, JP1.1, Q2.2, R3.1, R6.2, R7.2, U1.3, U2.3, U3.3
CW_5V: J5.1, J5.20, JP1.3
DIO0: J1.9, J11.3, J12.10, R7.1, R17.1, U1.4, U1.7
DIO1: J1.10, J11.5, J12.4, R6.1, R18.1, U1.5, U1.6
DIO2: J12.9, R19.1, U2.2, U2.9
DIO3: J12.3, R11.1, U2.5, U2.6
GND: C1.2, C2.2, C3.2, C4.2, C5.2, C6.2, C7.2, D1.1, J2.10, J3.2, J5.2, J5.17, J5.19, J6.2, J7.1, J8.2, J9.2, J10.8, J10.19, J10.20, J11.9, J11.20, J12.5, J12.11, J13.2, J13.3, J13.5, J13.9, J13.10, J13.11, Q1.2, R2.2, U1.8, U2.8, U3.8
IO: J12.7, R10.2, U1.2, U1.9
unnamed: C1.1, C2.1, F1.1, L1.2
unnamed: D1.2, R5.2
unnamed: F1.2, JP1.2
unnamed: JP2.1, JP4.2, R4.2
unnamed: JP2.2, JP3.1, R4.1, R8.2
unnamed: Q1.1, R1.1, R2.1
unnamed: Q1.3, Q2.1, R3.2
RST: J2.6, J10.14, J12.1, R9.2, U1.1, U1.10
Ready: J12.2, R12.2, U2.1, U2.10
TF: J5.9, Q2.3, R5.1
TFD: J2.9, J11.13, J13.1, R1.2, U3.4, U3.7
V_XBD: J1.1, J6.1, J8.1, J9.1, J10.5, JP3.2, R8.1
Valid: J12.8, R13.2, U2.4, U2.7
XBD_AVCC: C3.1, C4.1, JP4.1, L1.1

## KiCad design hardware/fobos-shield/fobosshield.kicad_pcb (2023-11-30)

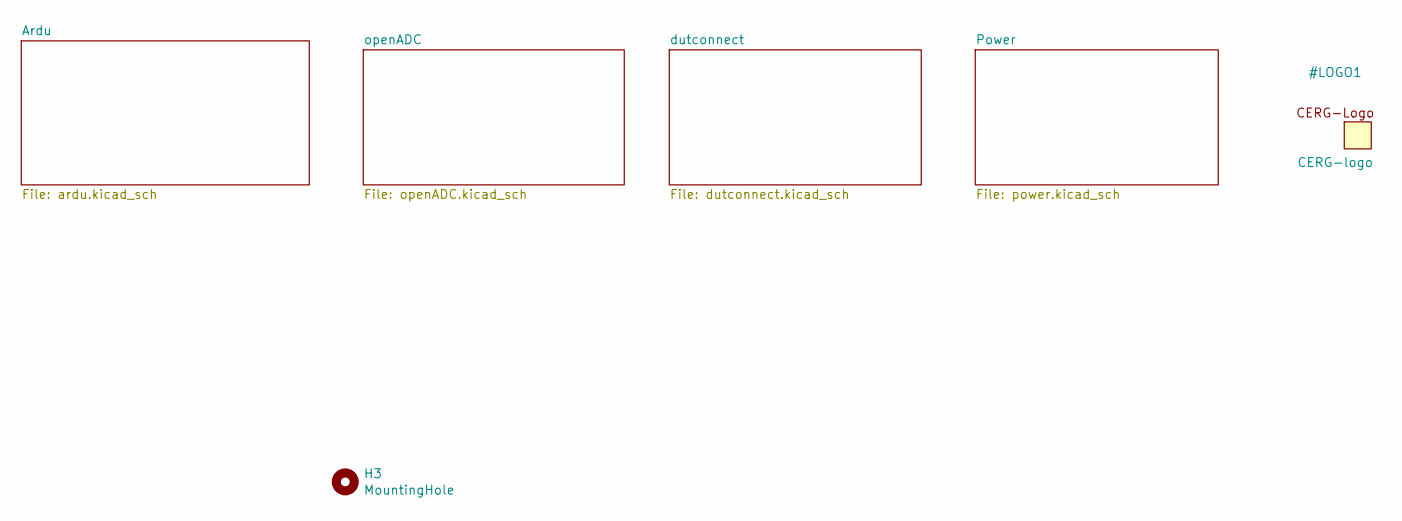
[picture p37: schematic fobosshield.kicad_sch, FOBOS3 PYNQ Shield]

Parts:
H3: MountingHole; MountingHole_3.2mm_M3_DIN965_Pad_TopBottom

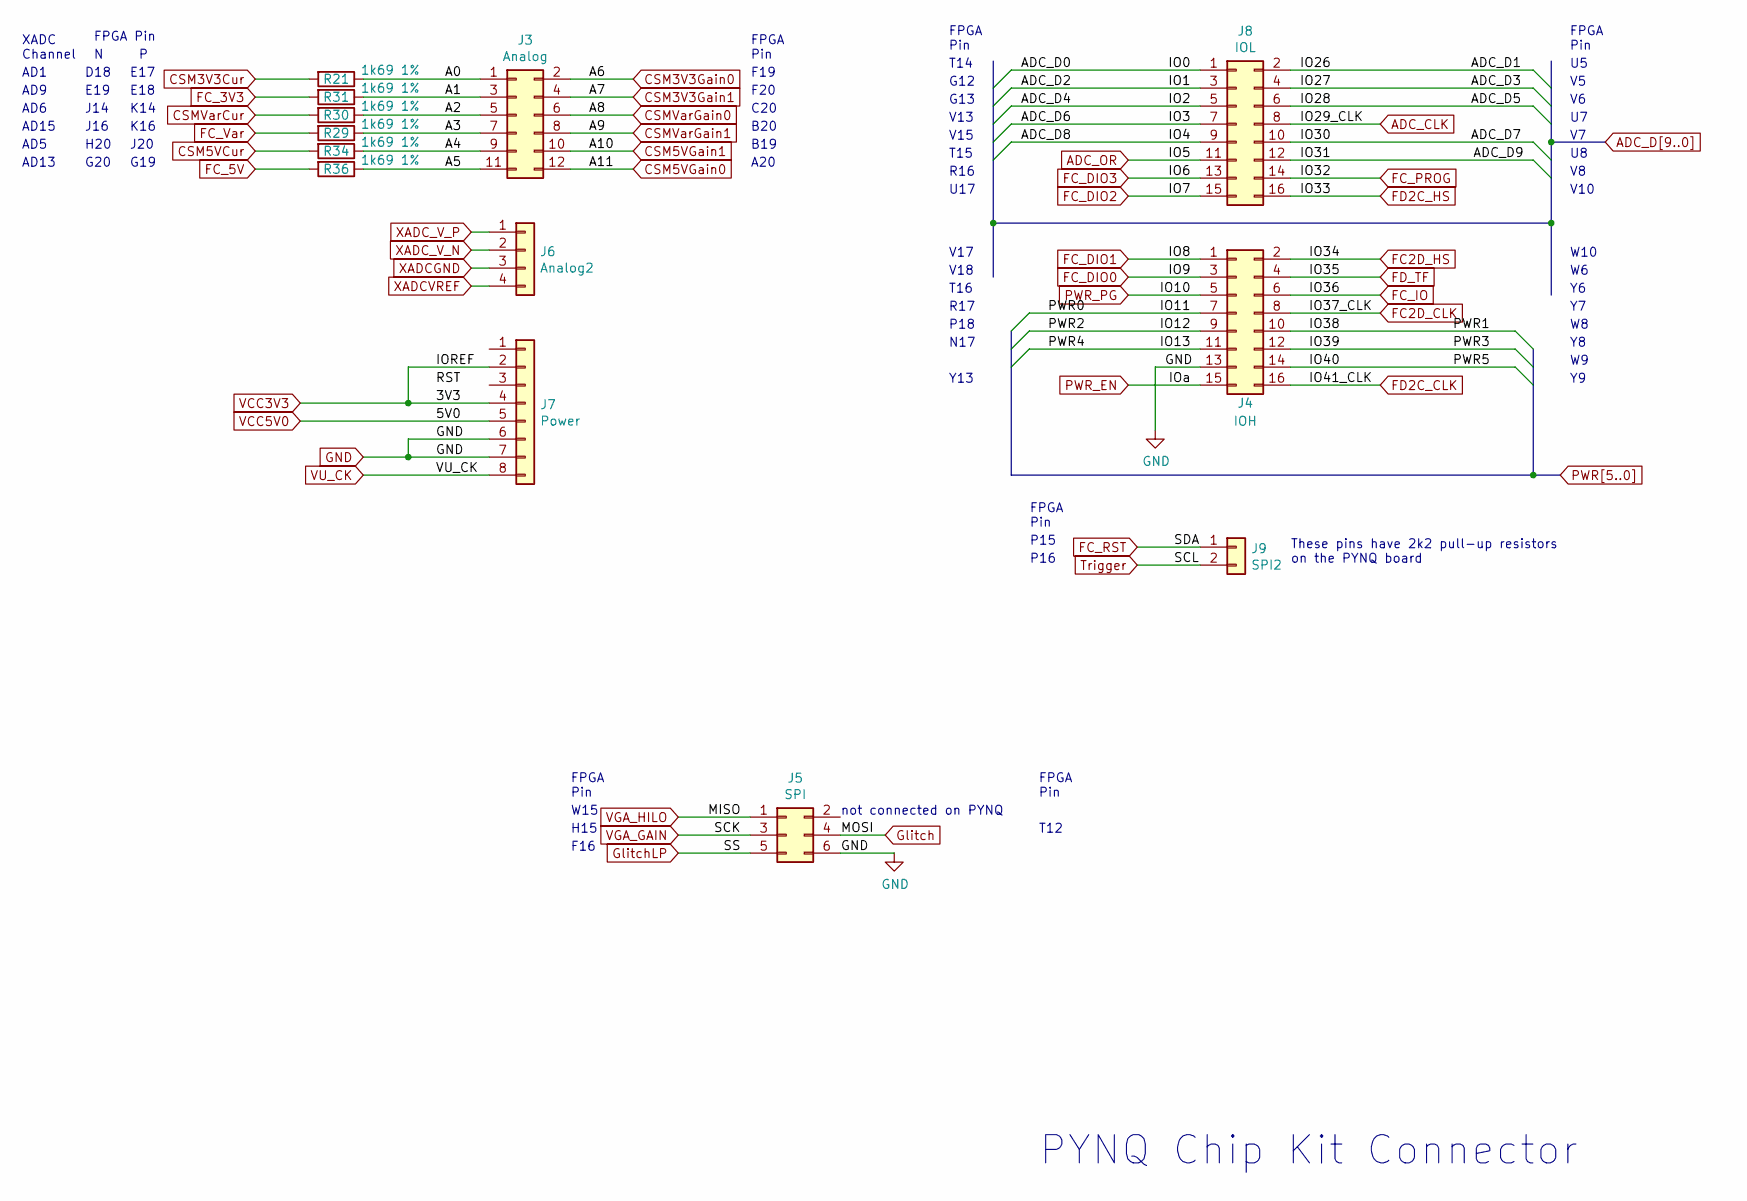
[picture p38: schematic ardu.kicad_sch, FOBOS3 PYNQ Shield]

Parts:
J3: Analog; PinHeader_2x06_P2.54mm_Vertical_flipped
J4: IOH; PinHeader_2x08_P2.54mm_Vertical_Flipped
J5: SPI; PinSocket_2x03_P2.54mm_Vertical
J6: Analog2; PinHeader_1x04_P2.54mm_Vertical
J7: Power; PinHeader_1x08_P2.54mm_Vertical
J8: IOL; PinHeader_2x08_P2.54mm_Vertical_Flipped
J9: SPI2; PinHeader_1x02_P2.54mm_Vertical
R21, R29, R30, R31, R34, R36: 1k69 1%; R_0603_1608Metric

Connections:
/Ardu/A0: J3.1, R21.1
/Ardu/A1: J3.3, R31.1
/Ardu/A2: J3.5, R30.1
/Ardu/A3: J3.7, R29.1
/Ardu/A4: J3.9, R34.1
/Ardu/A5: J3.11, R36.1
ADC_CLK: J8.8; also elsewhere on the board
ADC_D0: J8.1; also elsewhere on the board
ADC_D1: J8.2; also elsewhere on the board
ADC_D2: J8.3; also elsewhere on the board
ADC_D3: J8.4; also elsewhere on the board
ADC_D4: J8.5; also elsewhere on the board
ADC_D5: J8.6; also elsewhere on the board
ADC_D6: J8.7; also elsewhere on the board
ADC_D7: J8.10; also elsewhere on the board
ADC_D8: J8.9; also elsewhere on the board
ADC_D9: J8.12; also elsewhere on the board
ADC_OR: J8.11; also elsewhere on the board
CSM3V3Cur: R21.2; also elsewhere on the board
CSM3V3Gain0: J3.2; also elsewhere on the board
CSM3V3Gain1: J3.4; also elsewhere on the board
CSM5VCur: R34.2; also elsewhere on the board
CSM5VGain0: J3.12; also elsewhere on the board
CSM5VGain1: J3.10; also elsewhere on the board
CSMVarCur: R30.2; also elsewhere on the board
CSMVarGain0: J3.6; also elsewhere on the board
CSMVarGain1: J3.8; also elsewhere on the board
FC2D_CLK: J4.8; also elsewhere on the board
FC2D_HS: J4.2; also elsewhere on the board
FC_3V3: R31.2; also elsewhere on the board
FC_5V: R36.2; also elsewhere on the board
FC_DIO0: J4.3; also elsewhere on the board
FC_DIO1: J4.1; also elsewhere on the board
FC_DIO2: J8.15; also elsewhere on the board
FC_DIO3: J8.13; also elsewhere on the board
FC_IO: J4.6; also elsewhere on the board
FC_PROG: J8.14; also elsewhere on the board
FC_RST: J9.1; also elsewhere on the board
FC_Var: R29.2; also elsewhere on the board
FD2C_CLK: J4.16; also elsewhere on the board
FD2C_HS: J8.16; also elsewhere on the board
FD_TF: J4.4; also elsewhere on the board
GND: J4.13, J5.6, J7.6, J7.7; also elsewhere on the board
Glitch: J5.4; also elsewhere on the board
GlitchLP: J5.5; also elsewhere on the board
PWR0: J4.7; also elsewhere on the board
PWR1: J4.10; also elsewhere on the board
PWR2: J4.9; also elsewhere on the board
PWR3: J4.12; also elsewhere on the board
PWR4: J4.11; also elsewhere on the board
PWR5: J4.14; also elsewhere on the board
PWR_EN: J4.15; also elsewhere on the board
PWR_PG: J4.5; also elsewhere on the board
Trigger: J9.2; also elsewhere on the board
VCC3V3: J7.2, J7.4; also elsewhere on the board
VCC5V0: J7.5; also elsewhere on the board
VGA_GAIN: J5.3; also elsewhere on the board
VGA_HILO: J5.1; also elsewhere on the board
VU_CK: J7.8
XADCGND: J6.3; also elsewhere on the board
XADCVREF: J6.4
XADC_V_N: J6.2
XADC_V_P: J6.1

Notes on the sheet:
V18
H20
T12
P18
V15
V17
T14
W15
K14
FPGA Pin
E19
R16
G13
Y13
B19
B20
PYNQ Chip Kit Connector
AD6
P16
A20
XADC Channel
These pins have 2k2 pull-up resistors on the PYNQ board
AD13
V13
G20
F19
V10
T16
J16
T15
J20
F16
N17
not connected on PYNQ
J14
E18
AD9
F20
D18
AD5

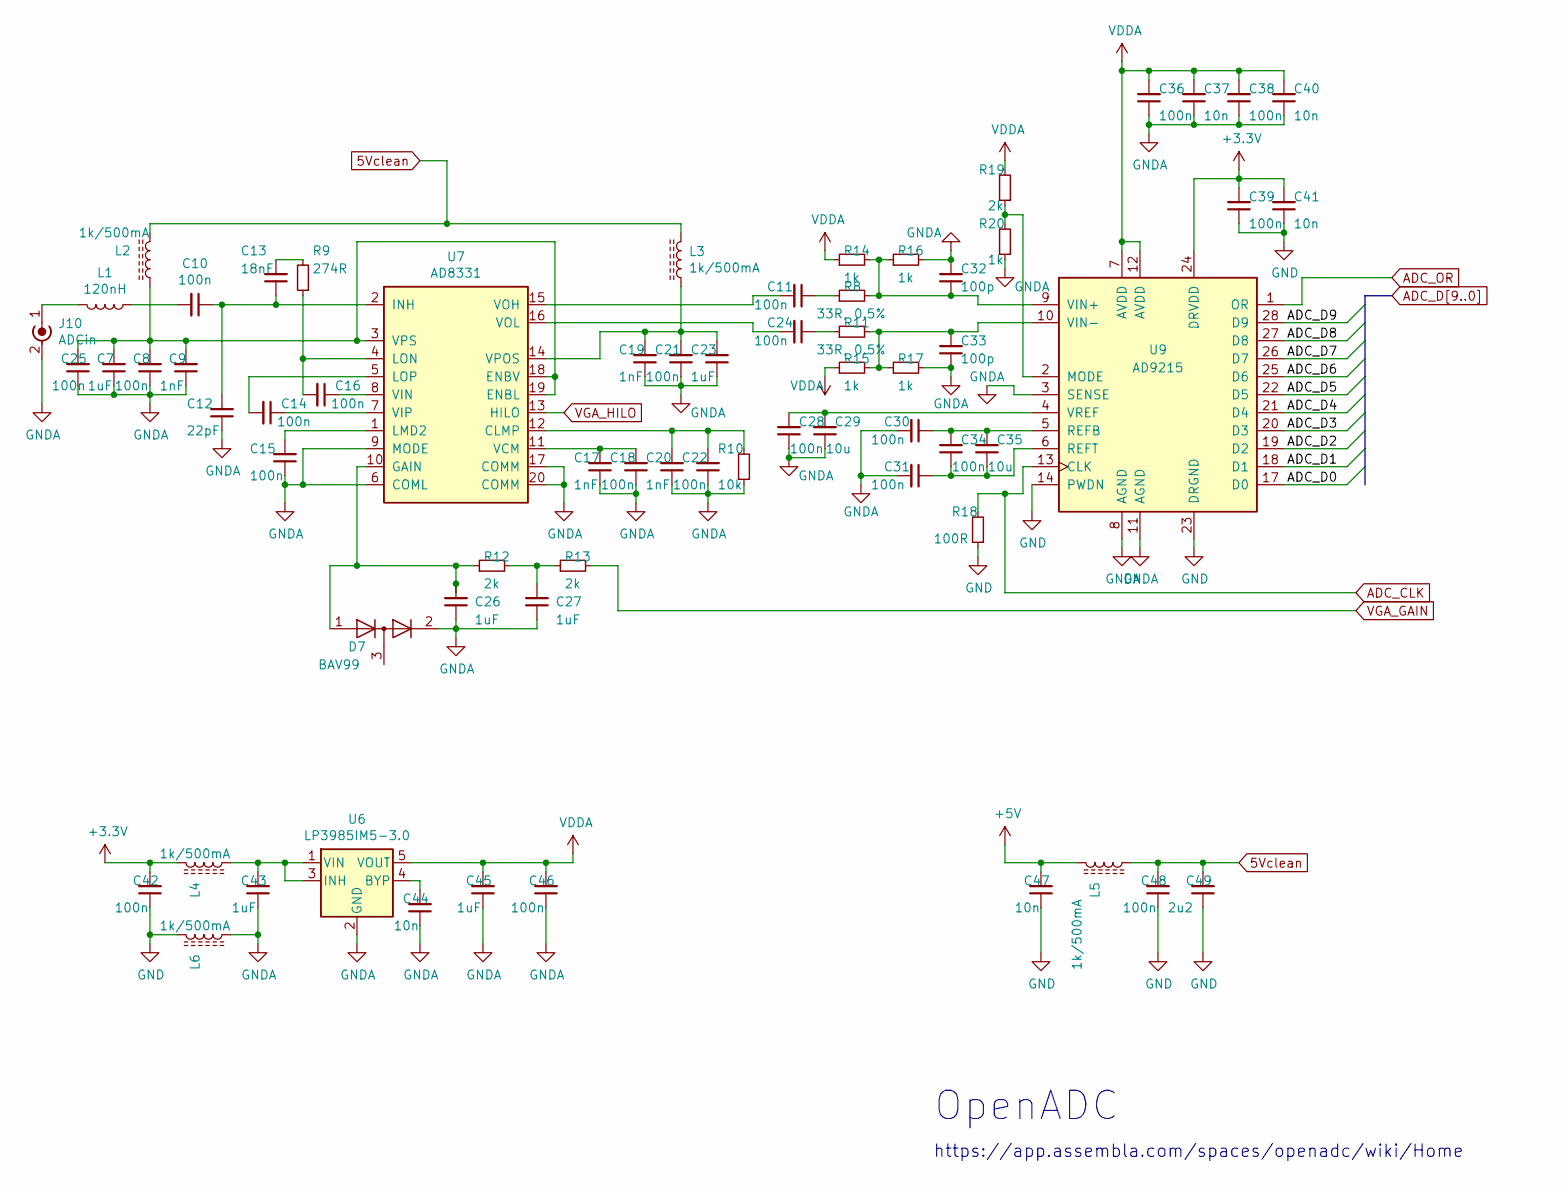
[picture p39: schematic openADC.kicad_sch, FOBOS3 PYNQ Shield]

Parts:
C7, C23, C26, C27, C43, C45: 1uF; C_0603_1608Metric
C8, C10, C11, C14, C15, C16, C18, C21, C22, C24, C25, C28, C30, C31, C34, C36, C38, C39, C42, C46, C48: 100n; C_0603_1608Metric
C9, C17, C19, C20: 1nF; C_0603_1608Metric
C12: 22pF; C_0603_1608Metric
C13: 18nF; C_0603_1608Metric
C29, C35: 10u; C_0603_1608Metric
C32, C33: 100p; C_0603_1608Metric
C37, C40, C41, C44, C47: 10n; C_0603_1608Metric
C49: 2u2; C_0603_1608Metric
D7: BAV99; SOT-23
J10: ADCin; SMA-JOHNSON-142-0701-801
L1: 120nH; L_0402_1005Metric
L2, L3, L4, L5, L6: 1k/500mA; L_0603_1608Metric
R8, R11: 33R, 0.5%; R_0603_1608Metric
R9: 274R; R_0603_1608Metric
R10: 10k; R_0603_1608Metric
R12, R13, R19: 2k; R_0603_1608Metric
R14, R15, R16, R17, R20: 1k; R_0603_1608Metric
R18: 100R; R_0603_1608Metric
U6: LP3985IM5-3.0; TSOT-23-5
U7: AD8331; QSOP-20_3.9x8.7mm_P0.635mm
U9: AD9215; TSSOP-28_4.4x9.7mm_P0.65mm

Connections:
5Vclean: C48.2, C49.2, L2.2, L3.2, L5.1
ADC_CLK: R18.2, U9.13 (CLK); also elsewhere on the board
ADC_D0: U9.17 (D0); also elsewhere on the board
ADC_D1: U9.18 (D1); also elsewhere on the board
ADC_D2: U9.19 (D2); also elsewhere on the board
ADC_D3: U9.20 (D3); also elsewhere on the board
ADC_D4: U9.21 (D4); also elsewhere on the board
ADC_D5: U9.22 (D5); also elsewhere on the board
ADC_D6: U9.25 (D6); also elsewhere on the board
ADC_D7: U9.26 (D7); also elsewhere on the board
ADC_D8: U9.27 (D8); also elsewhere on the board
ADC_D9: U9.28 (D9); also elsewhere on the board
ADC_OR: U9.1 (OR); also elsewhere on the board
GND: C39.1, C41.1, C42.1, C47.1, C48.1, C49.1, L6.2, R18.1, U9.14 (PWDN), U9.23 (DRGND); also elsewhere on the board
GNDA: C7.1, C8.1, C9.1, C12.1, C15.1, C17.1, C18.1, C19.1, C20.1, C21.1, C22.1, C23.1, C25.1, C26.1, C27.1, C28.1, C29.1, C30.2, C31.2, C32.2, C33.1, C36.1, C37.1, C38.1, C40.1, C43.1, C44.1, C45.1, C46.1, D7.2 (A), J10.2 (Ext), L6.1, R10.1, R16.2, R17.2, R20.1, U6.2 (GND), U7.6 (COML), U7.9 (MODE), U7.17 (COMM), U7.20 (COMM), U9.3 (SENSE), U9.8 (AGND), U9.11 (AGND)
unnamed: C10.1, C12.2, C13.1, U7.2 (INH)
unnamed: C10.2, L1.1
unnamed: C11.1, R8.1
unnamed: C11.2, U7.15 (VOH)
unnamed: C13.2, R9.2
unnamed: C14.1, U7.7 (VIP)
unnamed: C14.2, U7.5 (LOP)
unnamed: C15.2, U7.1 (LMD2)
unnamed: C16.1, U7.8 (VIN)
unnamed: C16.2, R9.1, U7.4 (LON)
unnamed: C17.2, C18.2, U7.11 (VCM)
unnamed: C19.2, C21.2, C23.2, L3.1, U7.14 (VPOS)
unnamed: C20.2, C22.2, R10.2, U7.12 (CLMP)
unnamed: C24.1, R11.1
unnamed: C24.2, U7.16 (VOL)
unnamed: C7.2, C8.2, C9.2, C25.2, L2.1, U7.3 (VPS), U7.18 (ENBV), U7.19 (ENBL)
unnamed: C26.2, D7.1 (K), R12.1, U7.10 (GAIN)
unnamed: C27.2, R12.2, R13.1
unnamed: C28.2, C29.2, U9.4 (VREF)
unnamed: C30.1, C34.2, C35.2, U9.5 (REFB)
unnamed: C31.1, C34.1, C35.1, U9.6 (REFT)
unnamed: C32.1, R8.2, R14.2, R16.1, U9.9 (VIN+)
unnamed: C33.2, R11.2, R15.2, R17.1, U9.10 (VIN-)
unnamed: C43.2, L4.1, U6.1 (VIN), U6.3 (INH)
unnamed: C44.2, U6.4 (BYP)
unnamed: J10.1 (In), L1.2
unnamed: R19.1, R20.2, U9.2 (MODE)
VCC3V3: C39.2, C41.2, C42.2, L4.2, U9.24 (DRVDD); also elsewhere on the board
VCC5V0: C47.2, L5.2; also elsewhere on the board
VDDA: C36.2, C37.2, C38.2, C40.2, C45.2, C46.2, R14.1, R15.1, R19.2, U6.5 (VOUT), U9.7 (AVDD), U9.12 (AVDD)
VGA_GAIN: R13.2; also elsewhere on the board
VGA_HILO: U7.13 (HILO); also elsewhere on the board

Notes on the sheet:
OpenADC
https://app.assembla.com/spaces/openadc/wiki/Home

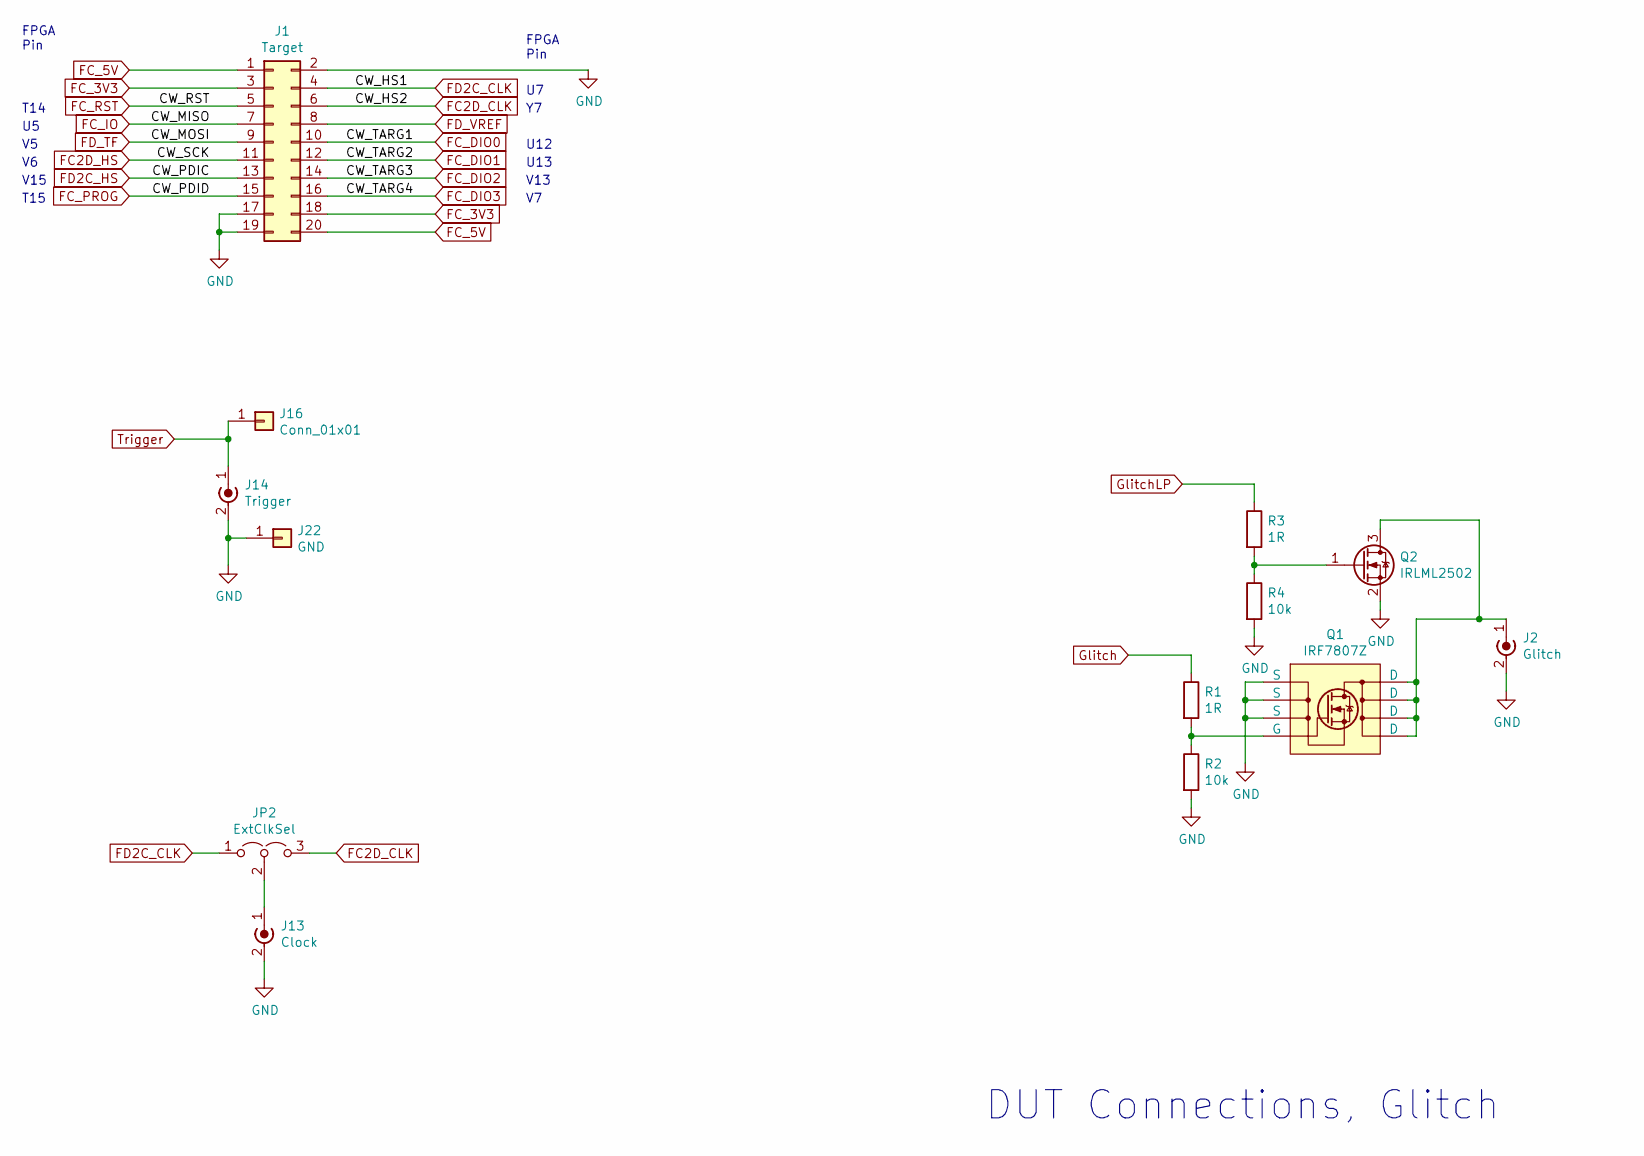
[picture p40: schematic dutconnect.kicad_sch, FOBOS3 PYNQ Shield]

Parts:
J1: Target; IDC-Header_2x10_P2.54mm_Horizontal
J2: Glitch; SMA-JOHNSON-142-0701-801
J13: Clock; SMA-JOHNSON-142-0701-801
J14: Trigger; SMA-JOHNSON-142-0701-801
J16: Conn_01x01; TestPoint_Loop_D2.60mm_Drill1.6mm_Beaded
J22: GND; TestPoint_Loop_D2.60mm_Drill1.6mm_Beaded
JP2: ExtClkSel; PinHeader_1x03_P2.54mm_Vertical
Q1: IRF7807Z; SOIC-8_3.9x4.9mm_P1.27mm
Q2: IRLML2502; SOT-23
R1, R3: 1R; R_0603_1608Metric
R2, R4: 10k; R_0603_1608Metric

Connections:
FC2D_CLK: J1.6, JP2.3 (B); also elsewhere on the board
FC2D_HS: J1.11; also elsewhere on the board
FC_3V3: J1.3, J1.18; also elsewhere on the board
FC_5V: J1.1, J1.20; also elsewhere on the board
FC_DIO0: J1.10; also elsewhere on the board
FC_DIO1: J1.12; also elsewhere on the board
FC_DIO2: J1.14; also elsewhere on the board
FC_DIO3: J1.16; also elsewhere on the board
FC_IO: J1.7; also elsewhere on the board
FC_PROG: J1.15; also elsewhere on the board
FC_RST: J1.5; also elsewhere on the board
FD2C_CLK: J1.4, JP2.1 (A); also elsewhere on the board
FD2C_HS: J1.13; also elsewhere on the board
FD_TF: J1.9; also elsewhere on the board
FD_VREF: J1.8
GND: J1.2, J1.17, J1.19, J2.2 (Ext), J13.2 (Ext), J14.2 (Ext), J22.1, Q1.1 (S), Q1.2 (S), Q1.3 (S), Q2.2 (S), R2.2, R4.2; also elsewhere on the board
Glitch: R1.1; also elsewhere on the board
GlitchLP: R3.1; also elsewhere on the board
unnamed: J2.1 (In), Q1.5 (D), Q1.6 (D), Q1.7 (D), Q1.8 (D), Q2.3 (D)
unnamed: J13.1 (In), JP2.2 (C)
unnamed: Q1.4 (G), R1.2, R2.1
unnamed: Q2.1 (G), R3.2, R4.1
Trigger: J14.1 (In), J16.1; also elsewhere on the board

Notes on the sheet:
V15
V13
T14
DUT Connections, Glitch
U12
T15
FPGA Pin
U13

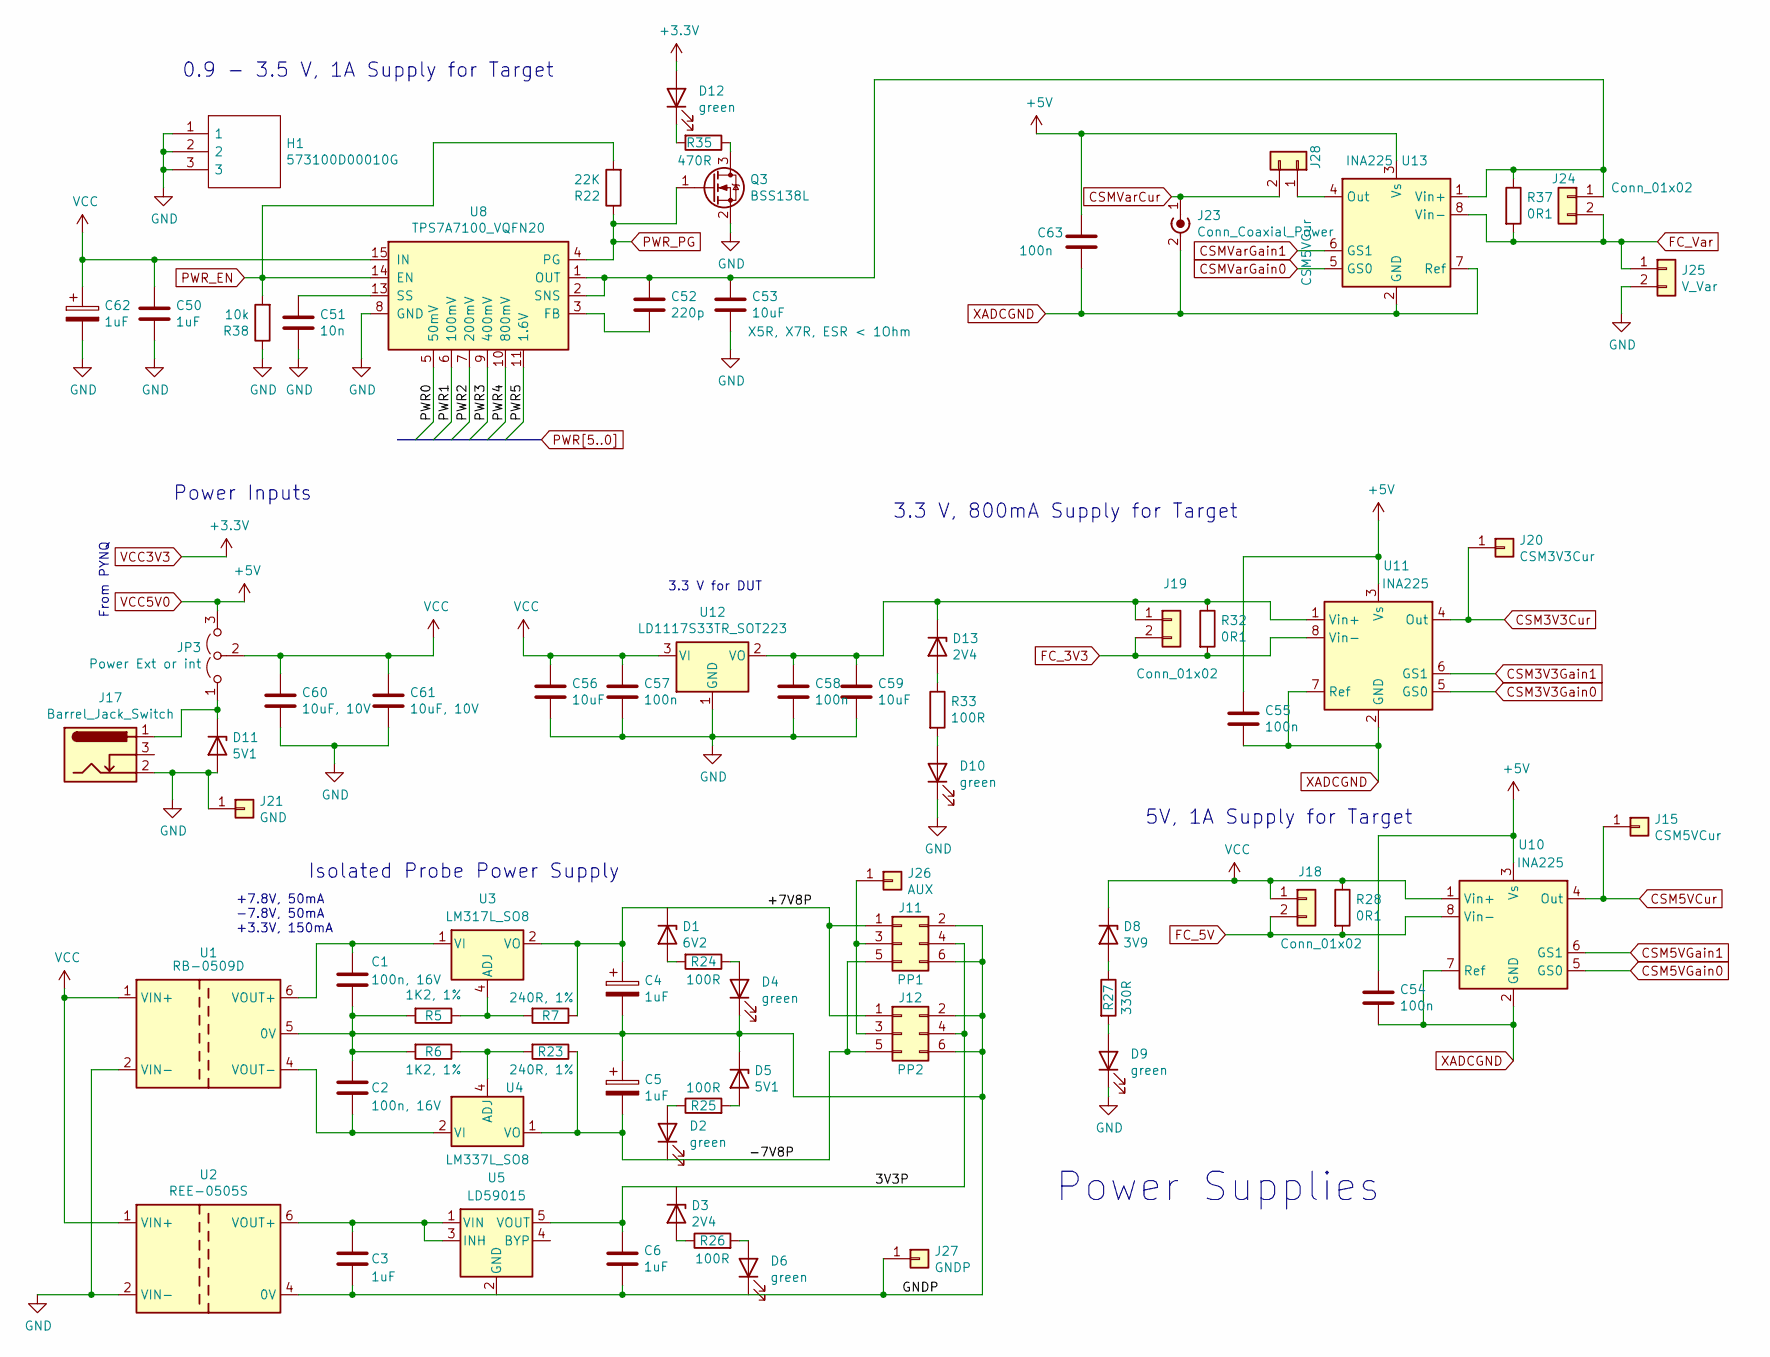
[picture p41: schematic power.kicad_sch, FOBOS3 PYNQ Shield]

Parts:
C1, C2: 100n, 16V; C_0603_1608Metric
C3, C6, C50: 1uF; C_0603_1608Metric
C4, C5, C62: 1uF; CP_EIA-3216-18_Kemet-A
C51: 10n; C_0402_1005Metric
C52: 220p; C_0402_1005Metric
C53, C56, C59: 10uF; C_0805_2012Metric
C54, C55, C57, C58, C63: 100n; C_0603_1608Metric
C60, C61: 10uF, 10V; C_0805_2012Metric
D1: 6V2; D_SOT-23_ANK
D2, D4, D6, D9, D10, D12: green; LED_0603_1608Metric
D3, D13: 2V4; D_SOT-23_ANK
D5, D11: 5V1; D_SOT-23_ANK
D8: 3V9; D_SOT-23_ANK
H1: 573100D00010G; Mouser Part Number 532-573100D00010G
J11: PP1; IDC-Header_2x03_P2.54mm_Horizontal
J12: PP2; IDC-Header_2x03_P2.54mm_Horizontal
J15: CSM5VCur; PinHeader_1x01_P2.54mm_Vertical
J17: Barrel_Jack_Switch; BarrelJack_CUI_PJ-102AH_Horizontal
J18, J19, J24: Conn_01x02; PinHeader_1x02_P2.54mm_Vertical
J20: CSM3V3Cur; PinHeader_1x01_P2.54mm_Vertical
J21: GND; PinHeader_1x01_P2.54mm_Vertical
J23: Conn_Coaxial_Power; SMA_Amphenol_901-144_Vertical
J25: V_Var; Molex_KK-254_AE-6410-02A_1x02_P2.54mm_Vertical
J26: AUX; PinHeader_1x01_P2.54mm_Vertical
J27: GNDP; PinHeader_1x01_P2.54mm_Vertical
J28: CSM5VCur; PinHeader_1x02_P2.54mm_Vertical
JP3: Power Ext or int; PinHeader_1x03_P2.54mm_Vertical
Q3: BSS138L; SOT-23
R5, R6: 1K2, 1%; R_0603_1608Metric
R7, R23: 240R, 1%; R_0603_1608Metric
R22: 22K; R_0603_1608Metric
R24, R25, R26, R33: 100R; R_0603_1608Metric
R27: 330R; R_0603_1608Metric
R28, R32, R37: 0R1; R_1206_3216Metric
R35: 470R; R_0603_1608Metric
R38: 10k; R_0603_1608Metric
U1: RB-0509D; Converter_DCDC_muRata_NMAxxxxSC_THT
U2: REE-0505S; Converter_DCDC_muRata_NMAxxxxSC_THT
U3: LM317L_SO8; SOIC-8_3.9x4.9mm_P1.27mm
U4: LM337L_SO8; SOIC-8_3.9x4.9mm_P1.27mm
U5: LD59015; TSOT-23-5
U8: TPS7A7100_VQFN20; Texas_VQFN-RGW-20
U10, U11, U13: INA225; MSOP-8_3x3mm_P0.65mm
U12: LD1117S33TR_SOT223; SOT-223-3_TabPin2

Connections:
/Power/3V3P: C6.1, D3.1 (K), J11.4, J12.4, U5.5 (VOUT)
/Power/+7V8P: C4.1, D1.1 (K), J11.1, J12.1, R7.1, U3.2 (VO), U3.3 (VO), U3.6 (VO), U3.7 (VO)
/Power/-7V8P: C5.2, D2.1 (K), J11.5, J12.5, R23.1, U4.1 (VO)
/Power/GNDP: C1.2, C2.1, C3.2, C4.2, C5.1, C6.2, D4.1 (K), D5.1 (K), D6.1 (K), J11.2, J11.6, J12.2, J12.6, J27.1, R5.2, R6.2, U1.5 (0V), U2.4 (0V), U5.2 (GND)
CSM3V3Cur: J20.1, U11.4 (Out); also elsewhere on the board
CSM3V3Gain0: U11.5 (GS0); also elsewhere on the board
CSM3V3Gain1: U11.6 (GS1); also elsewhere on the board
CSM5VCur: J15.1, U10.4 (Out); also elsewhere on the board
CSM5VGain0: U10.5 (GS0); also elsewhere on the board
CSM5VGain1: U10.6 (GS1); also elsewhere on the board
CSMVarCur: J23.1 (In), J28.2; also elsewhere on the board
CSMVarGain0: U13.5 (GS0); also elsewhere on the board
CSMVarGain1: U13.6 (GS1); also elsewhere on the board
FC_3V3: J19.2, R32.2, U11.8 (Vin-); also elsewhere on the board
FC_5V: J18.2, R28.2, U10.8 (Vin-); also elsewhere on the board
FC_Var: J24.2, J25.1, R37.2, U13.8 (Vin-); also elsewhere on the board
GND: C50.2, C51.2, C53.2, C56.2, C57.2, C58.2, C59.2, C60.2, C61.2, C62.2, D9.1 (K), D10.1 (K), D11.2 (A), H1.1, H1.2, H1.3, J17.2, J21.1, J25.2, Q3.2 (S), R38.1, U1.2 (VIN-), U2.2 (VIN-), U8.8 (GND), U8.12 (GND), U8.18 (GND), U8.21 (GND), U12.1 (GND); also elsewhere on the board
IN: C50.1, C56.1, C57.1, C60.1, C61.1, C62.1, D8.1 (K), J18.1, JP3.2 (C), R28.1, U1.1 (VIN+), U2.1 (VIN+), U8.15 (IN), U8.16 (IN), U8.17 (IN), U10.1 (Vin+), U12.3 (VI)
unnamed: C1.1, U1.6 (VOUT+), U3.1 (VI)
unnamed: C2.2, U1.4 (VOUT-), U4.2 (VI), U4.3 (VI), U4.6 (VI), U4.7 (VI)
unnamed: C3.1, U2.6 (VOUT+), U5.1 (VIN), U5.3 (INH)
unnamed: C51.1, U8.13 (SS)
unnamed: C52.1, C53.1, J24.1, R37.1, U8.1 (OUT), U8.2 (SNS), U8.19 (OUT), U8.20 (OUT), U13.1 (Vin+)
unnamed: C52.2, U8.3 (FB)
unnamed: C58.1, C59.1, D13.1 (K), J19.1, R32.1, U11.1 (Vin+), U12.2 (VO)
unnamed: D1.2 (A), R24.2
unnamed: D2.2 (A), R25.1
unnamed: D3.2 (A), R26.1
unnamed: D4.2 (A), R24.1
unnamed: D5.2 (A), R25.2
unnamed: D6.2 (A), R26.2
unnamed: D8.2 (A), R27.1
unnamed: D9.2 (A), R27.2
unnamed: D10.2 (A), R33.2
unnamed: D11.1 (K), J17.1, JP3.1 (A)
unnamed: D12.1 (K), R35.2
unnamed: D13.2 (A), R33.1
unnamed: J11.3, J12.3, J26.1
unnamed: J28.1, U13.4 (Out)
unnamed: Q3.3 (D), R35.1
unnamed: R5.1, R7.2, U3.4 (ADJ)
unnamed: R6.1, R23.2, U4.4 (ADJ)
PWR0: U8.5 (50mV); also elsewhere on the board
PWR1: U8.6 (100mV); also elsewhere on the board
PWR2: U8.7 (200mV); also elsewhere on the board
PWR3: U8.9 (400mV); also elsewhere on the board
PWR4: U8.10 (800mV); also elsewhere on the board
PWR5: U8.11 (1.6V); also elsewhere on the board
PWR_EN: R22.2, R38.2, U8.14 (EN); also elsewhere on the board
PWR_PG: Q3.1 (G), R22.1, U8.4 (PG); also elsewhere on the board
VCC3V3: D12.2 (A); also elsewhere on the board
VCC5V0: C54.1, C55.1, C63.1, JP3.3 (B), U10.3 (Vs), U11.3 (Vs), U13.3 (Vs); also elsewhere on the board
XADCGND: C54.2, C55.2, C63.2, J23.2 (Ext), U10.2 (GND), U10.7 (Ref), U11.2 (GND), U11.7 (Ref), U13.2 (GND), U13.7 (Ref); also elsewhere on the board

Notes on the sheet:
+7.8V, 50mA -7.8V, 50mA +3.3V, 150mA
Power Inputs
5V, 1A Supply for Target
3.3 V for DUT
Power Supplies
From PYNQ
0.9 - 3.5 V, 1A Supply for Target
Isolated Probe Power Supply
3.3 V, 800mA Supply for Target

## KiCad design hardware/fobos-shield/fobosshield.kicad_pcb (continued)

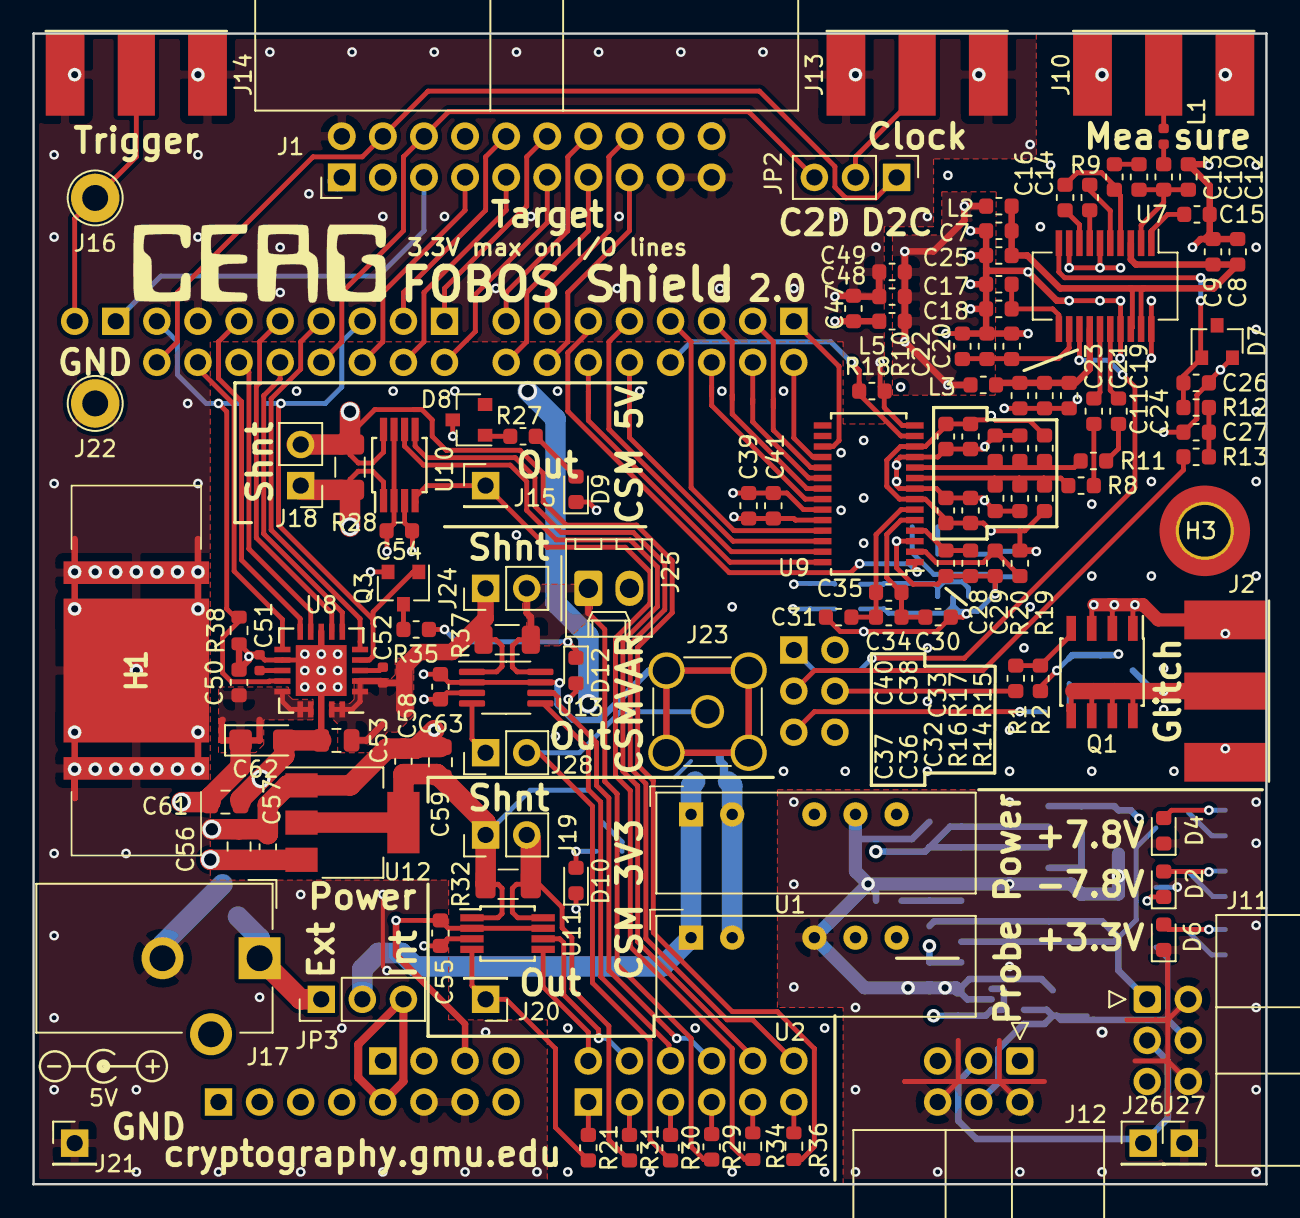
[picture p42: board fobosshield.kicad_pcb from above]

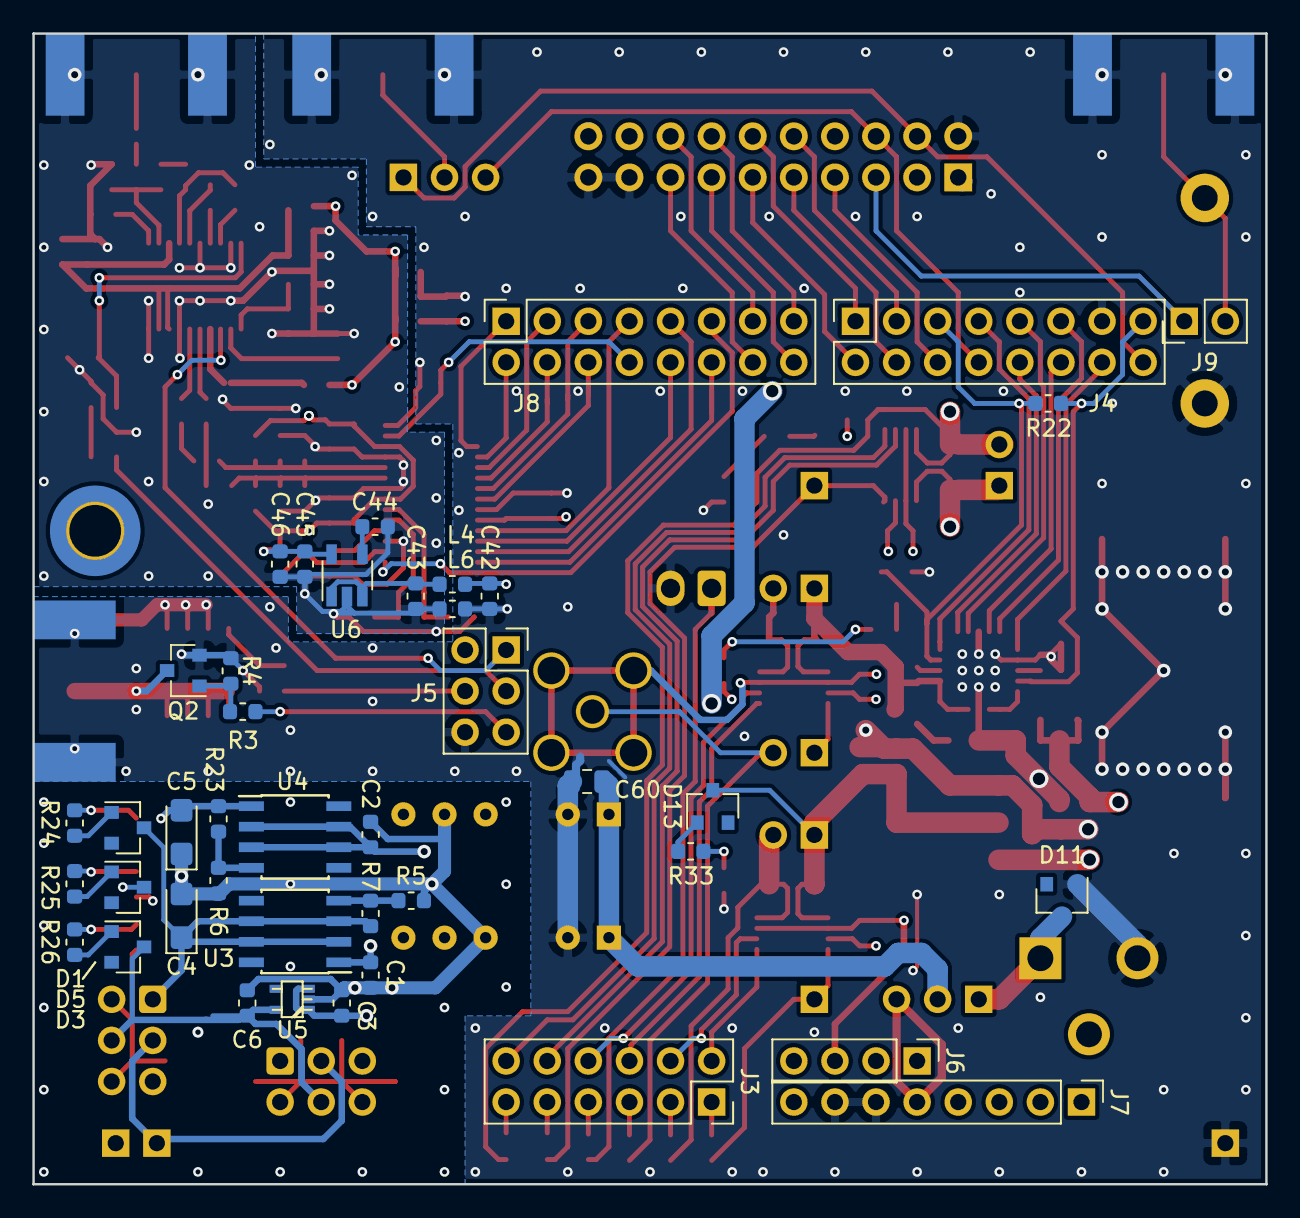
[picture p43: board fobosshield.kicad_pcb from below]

Board: 4 copper layers, 76.2 x 71.1 mm, 168 parts (42 on the bottom side), 122 nets.

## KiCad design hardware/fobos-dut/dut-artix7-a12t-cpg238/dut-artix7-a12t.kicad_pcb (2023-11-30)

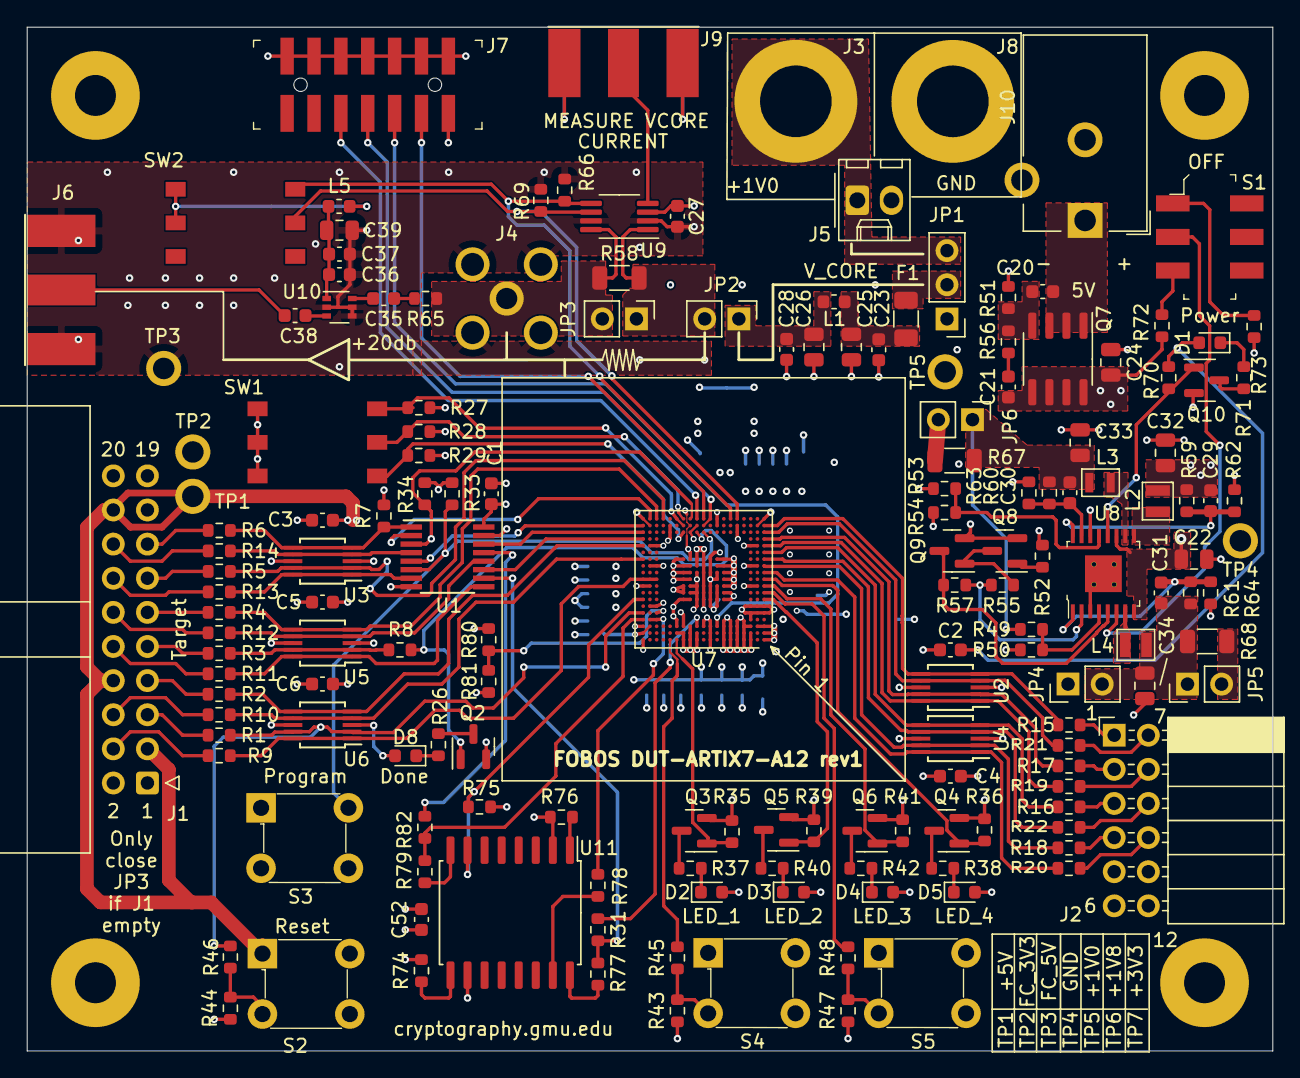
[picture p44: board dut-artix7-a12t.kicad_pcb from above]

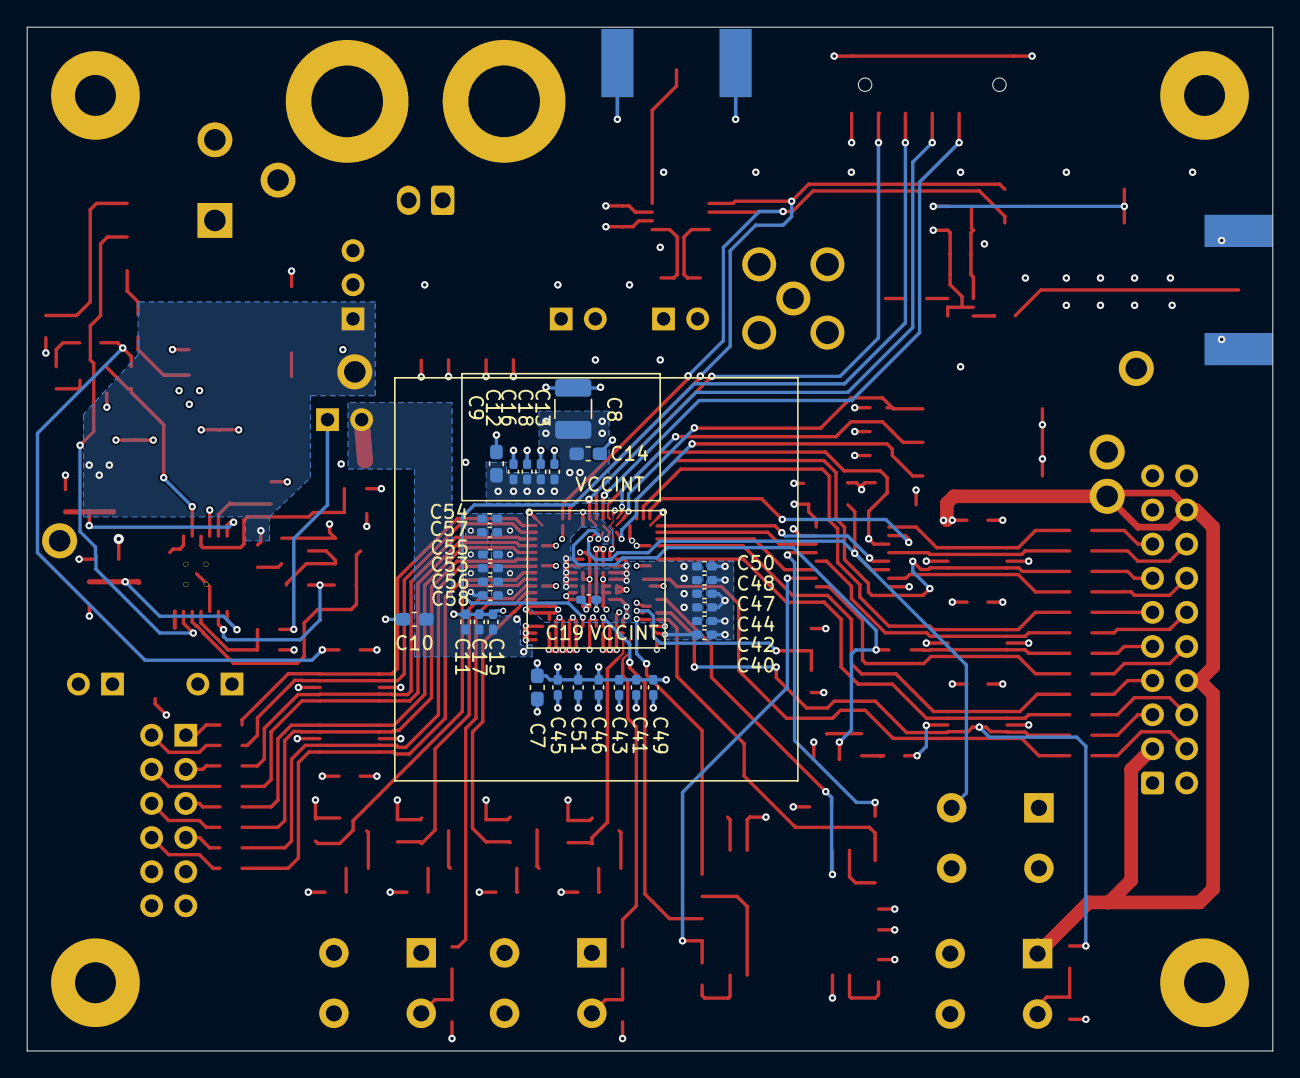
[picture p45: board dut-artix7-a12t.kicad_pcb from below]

Board: 4 copper layers, 92.7 x 76.2 mm, 199 parts (31 on the bottom side), 127 nets.

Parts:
C1, C2, C3, C4, C5, C6, C20, C23, C27, C28, C35, C37, C38, C52: 100nF; C_0603_1608Metric
C7, C9, C10, C14: 47uF; C_0603_1608Metric_Pad1.08x0.95mm_HandSolder
C8: 100uF; C_1210_3225Metric_Pad1.33x2.70mm_HandSolder
C11, C12, C40, C41, C42, C43, C53, C54: 4.7uF; C_0402_1005Metric_Pad0.74x0.62mm_HandSolder
C13, C15, C16, C17, C18, C19, C44, C45, C46, C47, C48, C49, C50, C51, C55, C56, C57, C58: .47uF; C_0402_1005Metric_Pad0.74x0.62mm_HandSolder
C21: 10nF; C_0603_1608Metric
C22, C32: 22uF; C_0805_2012Metric
C24, C25, C33, C34: 10uF; C_0805_2012Metric
C26: 47uF6.3V; C_0805_2012Metric
C29, C30, C31: 20pF; C_0603_1608Metric
C36: 4n7; C_0603_1608Metric
C39: 2u2; C_0805_2012Metric
D1, D2, D3, D4, D5, D8: LG_L29K-G2J1-24-Z; LED_0603_1608Metric
F1: MF-MSMF050-2; Fuse_1206_3216Metric
H1, H2, H3, H4: MountingHole; MH_4-40
J1: Target; IDC-Header_2x10_P2.54mm_Horizontal
J2: Pmod 2x6; PinSocket_2x06_P2.54mm_Horizontal_FLipped
J3, J8: 575-8
J4: Glitch; SMA-JOHNSON-142-0701-201
J5: Conn_01x02; Molex_KK-254_AE-6410-02A_1x02_P2.54mm_Vertical
J6, J9: Measure; SMA-JOHNSON-142-0701-801
J7: 0878321420; PinHeader_2x7_P2mm_SMD
J10: Barrel_Jack_Switch; BarrelJack_CUI_PJ-102AH_Horizontal
JP1: Source; PinHeader_1x03_P2.54mm_Vertical
JP2: CurProbe; PinHeader_1x02_P2.54mm_Vertical
JP3: Shunt1V; PinHeader_1x02_P2.54mm_Vertical
JP4: FC3V3_3V3_SHUNT; PinHeader_1x02_P2.54mm_Vertical
JP5: Shunt3V3; PinHeader_1x02_P2.54mm_Vertical
JP6: Shunt1V8; PinHeader_1x02_P2.54mm_Vertical
L1, L5: 1k/500mA; L_0603_1608Metric
L2: 1.5uH; L_SRN2012
L3: 3.3uH; L_BRC2012
L4: 2.2uH; L_SRN2012
Q2, Q3, Q4, Q5, Q6, Q10: BSS138; SOT-23
Q7: FDS9435A; SOIC-8_3.9x4.9mm_P1.27mm
Q8, Q9: MMBT3904; SOT-23
R1, R2, R3, R4, R5, R6, R9, R10, R11, R12, R13, R14: 22R; R_0603_1608Metric
R7, R35, R36, R39, R41, R43, R44, R45, R46, R47, R48, R50, R66, R69, R73: 10KR; R_0603_1608Metric
R8, R31, R53, R82: 0R; R_0603_1608Metric
R15, R16, R17, R18, R19, R20, R21, R22: 200R; R_0603_1608Metric
R26, R37, R38, R40, R42: 470R; R_0603_1608Metric
R27, R28, R29, R33, R34, R72, R74, R75, R76: 4.7KR; R_0603_1608Metric
R49: 3.48KR; R_0603_1608Metric
R51: 1M; R_0603_1608Metric
R52, R80, R81: 1KR; R_0603_1608Metric
R54, R55, R57, R70: 100KR; R_0603_1608Metric
R56: 100R; R_0603_1608Metric
R58, R67, R68: 0R1; R_1206_3216Metric
R59: 30K; R_0603_1608Metric
R60: 150K; R_0603_1608Metric
R61: 180K; R_0603_1608Metric
R62, R63: 120KR; R_0603_1608Metric
R64: 57.6KR; R_0603_1608Metric
R65: 49R9; R_0603_1608Metric
R71: 800R; R_0603_1608Metric
R77, R78, R79: 33R; R_0603_1608Metric
S1: JS202011SCQN; Switch_Slide_JS202011SCQN
S2, S3, S4, S5: 1825910-6; Switch_Tactile_THT_6x6mm
SW1, SW2: SW_DIP_x03; DS04-254-2-03BK-SMT
TP1, TP2, TP3, TP4, TP5: 5281
U1: TS3A5018DBQR; SSOP-16_4.0x5.0mm_P0.635mm
U2, U3, U4, U5, U6: SP3003-04ATG; MSOP-10_3x3mm_P0.5mm
U7: XC7A12T-CPG238; Xilinx_CPG238
U8: LTC3569EFE#PBF; TSSOP-16-1EP_W4.40mm
U9: INA225; MSOP-8_3x3mm_P0.65mm
U10: BGA2801; SOT-363_SC-70-6
U11: IS25LP256D-JMLE; SOIC-16W_7.5x10.3mm_P1.27mm

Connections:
+1V0: C29.1, C32.1, JP1.1 (A), L2.2, R52.1, R59.2, TP5.1
+1V8: C10.1, C11.1, C15.1, C17.1, JP6.2 (B), R67.2, U7.C13 (VCCADC_0), U7.H13 (VCCAUX), U7.J13 (VCCAUX)
+3V3: C7.1, C40.1, C41.1, C42.1, C43.1, C44.1, C45.1, C46.1, C47.1, C48.1, C49.1, C50.1, C51.1, C52.1, C53.1, C54.1, C55.1, C56.1, C57.1, C58.1, J7.2, JP5.2 (B), R27.1, R28.1, R29.1, R33.2, R34.2, R68.2, R74.2, R75.2, R76.2, R80.2, U7.B19 (VCCO_15), U7.C14 (VCCO_15), U7.C18 (VCCO_15), U7.G12 (VCCO_0), U7.G13 (VCCO_15), U7.J7 (VCCO_34), U7.K7 (VCCO_34), U7.K12 (VCCO_14), U7.K13 (VCCO_14), U7.L7 (VCCO_34), U7.L12 (VCCO_14), U7.L13 (VCCO_14), U7.M7 (VCCO_34), U7.M8 (VCCO_34), U7.M12 (VCCO_14), U7.M13 (VCCO_14), U7.N7 (VCCO_34), U7.N8 (VCCO_34), U7.N13 (VCCO_14), U7.U12 (CFGBVS_0), U7.V11 (VCCO_0), U11.2 (VCC)
+5V: C21.1, C22.1, C24.1, C27.1, Q7.5 (D), Q7.6 (D), Q7.7 (D), Q7.8 (D), R53.2, R55.2, R57.2, R72.2, TP4.1, U8.2 (SVIN), U8.8 (PVIN1), U8.11 (PVIN2), U8.14 (RT), U9.3 (Vs)
/Connectors, IO/CW_HS1: J1.4, R9.2
/Connectors, IO/CW_HS2: J1.6, R10.2
/Connectors, IO/CW_MISO: J1.7, R2.1
/Connectors, IO/CW_MOSI: J1.9, R3.1
/Connectors, IO/CW_PDIC: J1.13, R5.1
/Connectors, IO/CW_PDID: J1.15, R6.1
/Connectors, IO/CW_RST: J1.5, R1.1
/Connectors, IO/CW_SCK: J1.11, R4.1
/Connectors, IO/CW_TARG1: J1.10, R11.2
/Connectors, IO/CW_TARG2: J1.12, R12.2
/Connectors, IO/CW_TARG3: J1.14, R13.2
/Connectors, IO/CW_TARG4: J1.16, R14.2
/FPGA 1/DIN: R79.1, R82.2, U7.D19 (IO_L1N_T0_D01_DIN_14)
/FPGA 1/FCS: R75.1, U7.G19 (IO_L6P_T0_FCS_B_14), U11.7 (CE#)
/FPGA 1/MOSI: R78.1, U7.D17 (IO_0_14), U7.D18 (IO_L1P_T0_D00_MOSI_14)
/FPGA 1/PUDC: R80.1, R81.2, U7.E17 (IO_L3P_T0_DQS_PUDC_B_14)
/FPGA Programming/CCLK: R31.2, U7.C11 (CCLK_0)
/FPGA Programming/MODE_1: R28.2, SW1.4, U7.W13 (M1_0)
/FPGA Programming/MODE_2: R29.2, SW1.6, U7.U13 (M2_0)
/FPGA Programming/TCK: J7.6, U7.C8 (TCK_0)
/FPGA Programming/TDI: J7.10, U7.W11 (TDI_0)
/FPGA Programming/TMS: J7.4, U7.W10 (TMS_0)
/Power/EN2: Q9.3 (C), R57.1, U8.5 (EN2)
/Power/EN3: R49.1, R50.2, U8.4 (EN3)
/Power/FB1: C29.2, R59.1, R62.1, U8.16 (FB1)
/Power/FB2: C30.2, R60.1, R63.1, U8.15 (FB2)
/Power/FB3: C31.2, R61.1, R64.1, U8.1 (FB3)
/Power/MODE: R53.1, R54.2, U8.13 (MODE)
/Power/SW1: L2.1, U8.9 (SW1)
/Power/SW2: L3.1, U8.10 (SW2)
/Power/SW3: L4.1, U8.7 (SW3)
FC2D_CLK: R10.1, U6.4 (IO3), U7.N19 (IO_L13P_T2_MRCC_14)
FC2D_HS: R4.2, U5.5 (IO4), U7.W17 (IO_L20P_T3_A08_D24_14)
FC_3V3: C1.1, C2.2, C3.2, C4.2, C5.2, C6.2, D1.2 (A), D2.2 (A), D3.2 (A), D4.2 (A), D5.2 (A), D8.2 (A), J1.3, J1.8, J1.18, J2.6, J2.12, JP4.1 (A), L5.1, R70.1, S2.1, S4.1, S5.1, SW2.4, SW2.6, TP1.1, U1.16 (V+), U2.3 (VCC), U3.3 (VCC), U4.3 (VCC), U5.3 (VCC), U6.3 (VCC)
FC_5V: C20.1, J1.1, J1.20, J10.1, Q7.1 (S), Q7.2 (S), Q7.3 (S), TP2.1
FC_DIO0: R11.1, U1.9 (COM3), U5.1 (IO1)
FC_DIO0_MUX: U1.11 (NC3), U7.T19 (IO_L15N_T2_DQS_DOUT_CSO_B_14)
FC_DIO1: R12.1, U1.12 (COM4), U5.4 (IO3)
FC_DIO1_MUX: U1.14 (NC4), U7.U19 (IO_L16P_T2_CSI_B_14)
FC_DIO2: R13.1, U1.7 (COM2), U3.1 (IO1)
FC_DIO2_MUX: U1.5 (NC2), U7.V19 (IO_L16N_T2_A15_D31_14)
FC_DIO3: R14.1, U1.4 (COM1), U3.4 (IO3)
FC_DIO3_MUX: U1.2 (NC1), U7.W18 (IO_L20N_T3_A07_D23_14)
FC_IO: R2.2, U6.5 (IO4), U7.R19 (IO_L15P_T2_DQS_RDWR_B_14)
FC_PROG: R6.2, R7.2, U1.1 (IN), U3.5 (IO4)
FC_RST: R1.2, R46.2, U6.2 (IO2), U7.E19 (IO_L2P_T0_D02_14)
FD2C_CLK: R9.1, U6.1 (IO1), U7.K17 (IO_L12P_T1_MRCC_14), U7.K18 (IO_L11P_T1_SRCC_14), U7.K19 (IO_L8N_T1_D12_14)
FD2C_HS: R5.2, U3.2 (IO2), U7.W16 (IO_L24N_T3_A00_D16_14)
FD_TF: R3.2, R8.1, U5.2 (IO2)
GND: C1.2, C2.1, C3.1, C4.1, C5.1, C6.1, C7.2, C8.2, C9.2, C10.2, C11.2, C12.2, C13.2, C14.2, C15.2, C16.2, C17.2, C18.2, C19.2, C22.2, C23.2, C24.2, C25.2, C26.2, C27.2, C28.2, C32.2, C33.2, C34.2, C36.2, C37.2, C39.2, C40.2, C41.2, C42.2, C43.2, C44.2, C45.2, C46.2, C47.2, C48.2, C49.2, C50.2, C51.2, C52.2, C53.2, C54.2, C55.2, C56.2, C57.2, C58.2, J1.2, J1.17, J1.19, J2.5, J2.11, J4.2 (Ext), J5.2, J6.2 (Ext), J7.1, J7.3, J7.5, J7.7, J7.9, J7.11, J7.13, J8.1, J9.2 (Ext), J10.2, Q2.2 (S), Q3.2 (S), Q4.2 (S), Q5.2 (S), Q6.2 (S), Q8.2 (E), Q9.2 (E), Q10.2 (S), R7.1, R35.1, R36.1, R39.1, R41.1, R43.1, R44.1, R47.1, R50.1, R51.1, R54.1, R62.2, R63.2, R64.2, R66.1, R69.1, R73.1, R81.1, S3.4, SW1.1, SW1.3, SW1.5, TP3.1, U1.8 (GND), U1.15 (EN#), U2.8 (GND), U3.8 (GND), U4.8 (GND), U5.8 (GND), U6.8 (GND), U7.A1 (GND), U7.A3 (GND), U7.A4 (MGTPRXN0_216), U7.A5 (GND), U7.A6 (MGTPRXN1_216), U7.A7 (GND), U7.A9 (GND), U7.A11 (DXP_0), U7.A12 (VP_0), U7.A13 (VREFN_0), U7.A19 (GND), U7.B1 (MGTAVTT), U7.B3 (GND), U7.B4 (MGTPRXP0_216), U7.B5 (GND), U7.B6 (MGTPRXP1_216), U7.B7 (GND), U7.B9 (GND), U7.B11 (DXN_0), U7.B12 (VREFP_0), U7.B13 (VN_0), U7.B14 (GND), U7.C1 (MGTAVCC), U7.C2 (GND), U7.C3 (GND), U7.C4 (GND), U7.C5 (MGTAVTT), U7.C6 (GND), U7.C7 (MGTRREF_216), U7.C9 (VCCBATT_0), U7.C10 (GND), U7.C12 (GNDADC_0), U7.C19 (GND), U7.D3 (GND), U7.E1 (MGTAVCC), U7.E2 (MGTAVTT), U7.E3 (GND), U7.F1 (GND), U7.F2 (GND), U7.F3 (GND), U7.F17 (IO_L5P_T0_D06_14), U7.F18 (GND), U7.G7 (MGTAVTT), U7.G8 (GND), U7.G9 (MGTAVCC), U7.G11 (GND), U7.H7 (GND), U7.H8 (GND), U7.H9 (MGTAVCC), U7.H11 (GND), U7.H12 (GND), U7.J2 (GND), U7.J3 (IO_L5P_T0_34), U7.J8 (GND), U7.J9 (GND), U7.J11 (GND), U7.J12 (GND), U7.J18 (GND), U7.J19 (IO_L8P_T1_D11_14), U7.K8 (GND), U7.L8 (GND), U7.L9 (GND), U7.L11 (GND), U7.M2 (GND), U7.M3 (IO_L10P_T1_34), U7.M9 (GND), U7.M17 (IO_L10P_T1_D14_14), U7.M18 (GND), U7.N9 (GND), U7.N12 (GND), U7.R2 (GND), U7.R3 (IO_L12N_T1_MRCC_34), U7.R17 (IO_L17N_T2_A13_D29_14), U7.R18 (GND), U7.U5 (IO_L19N_T3_VREF_34), U7.U15 (IO_L22P_T3_A05_D21_14), U7.V2 (GND), U7.V5 (GND), U7.V8 (GND), U7.V12 (GND), U7.V15 (GND), U7.V18 (GND), U7.W1 (GND), U7.W8 (IO_L23N_T3_34), U7.W19 (GND), U8.3 (SGND), U8.17 (EPAD), U9.2 (GND), U9.7 (Ref), U10.2 (G), U10.4 (G), U10.5 (G), U11.10 (GND)
JA1: R15.2, U2.5 (IO4), U7.V1 (IO_L14N_T2_SRCC_34)
JA2: R17.2, U2.2 (IO2), U7.T1 (IO_L11N_T1_SRCC_34)
JA3: R16.2, U4.5 (IO4), U7.P1 (IO_L9N_T1_DQS_34)
JA4: R18.2, U4.2 (IO2), U7.M1 (IO_L7N_T1_34)
JA7: R21.1, U2.4 (IO3), U7.U1 (IO_L14P_T2_SRCC_34)
JA8: R19.1, U2.1 (IO1), U7.R1 (IO_L11P_T1_SRCC_34)
JA9: R22.1, U4.4 (IO3), U7.N1 (IO_L9P_T1_DQS_34)
JA10: R20.1, U4.1 (IO1), U7.L1 (IO_L7P_T1_34)
MODE_0: R27.2, SW1.2, U7.V13 (M0_0), U7.W14 (IO_L23N_T3_A02_D18_14)
unnamed: C21.2, R56.1
unnamed: C23.1, C25.1, F1.1, L1.2
unnamed: C35.1, U10.6
unnamed: C35.2, R65.1
unnamed: C38.2, U10.3
unnamed: D1.1 (K), R71.1
unnamed: D2.1 (K), R37.1
unnamed: D3.1 (K), R40.1
unnamed: D4.1 (K), R42.1
unnamed: D5.1 (K), R38.1
unnamed: D8.1 (K), R26.1
unnamed: J2.1, R15.1
unnamed: J2.2, R17.1
unnamed: J2.3, R16.1
unnamed: J2.4, R18.1
unnamed: J2.7, R21.2
unnamed: J2.8, R19.2
unnamed: J2.9, R22.2
unnamed: J2.10, R20.2
unnamed: J3.1, J5.1, JP1.3 (B)
unnamed: C38.1, J6.1 (In)
unnamed: F1.2, JP1.2 (C)
unnamed: C26.1, C28.1, JP2.1 (A), L1.1
unnamed: JP2.2 (B), JP3.1 (A), R58.2, U9.1 (Vin+)
unnamed: Q2.3 (D), R26.2
unnamed: Q3.3 (D), R37.2
unnamed: Q4.3 (D), R38.2
unnamed: Q5.3 (D), R40.2
unnamed: Q6.3 (D), R42.2
unnamed: C20.2, Q7.4 (G), R51.2, R56.2
unnamed: Q8.1 (B), R52.2
unnamed: Q8.3 (C), Q9.1 (B), R55.1
unnamed: Q10.3 (D), R71.2
unnamed: R43.2, R45.1, S4.3
unnamed: R44.2, R46.1, S2.3
unnamed: R47.2, R48.1, S5.3
unnamed: R72.1, S1.3
unnamed: R73.2, S1.1
unnamed: C36.1, C37.1, C39.1, L5.2, U10.1 (Vcc)
unnamed: R76.1, U11.1 (HOLD#)
unnamed: R77.2, U11.16 (SCK)
unnamed: R78.2, U11.15 (SI)
unnamed: R79.2, U11.8 (SO)
unnamed: R74.1, U11.9 (WP#)
ON_OFF: S1.2, U8.6 (EN1)
PGOOD: Q10.1 (G), R70.2, U8.12 (PGOOD)
SW_CLK: R31.1, R77.1, U1.10 (NO3)
SW_DIN: R82.1, U1.13 (NO4)
SW_DONE: Q2.1 (G), R8.2, U7.U11 (DONE_0)
SW_INIT_B: R34.1, U1.3 (NO1), U7.W12 (INIT_B_0)
SW_PROGRAM_B: R33.1, S3.2, U1.6 (NO2), U7.U10 (PROGRAM_B_0)
TDO: J7.8, U7.V10 (TDO_0), U7.W9 (IO_L23P_T3_34)
USER_BTN_1: R45.2, U7.A15 (IO_L10N_T1_AD4N_15)
USER_BTN_2: R48.2, U7.H1 (IO_L3P_T0_DQS_34)
USER_LED_1: Q3.1 (G), R35.2, U7.A14 (IO_L10P_T1_AD4P_15)
USER_LED_2: Q5.1 (G), R39.2, U7.G1 (IO_L1N_T0_34)
USER_LED_3: Q6.1 (G), R41.2, U7.J1 (IO_L3N_T0_DQS_34)
USER_LED_4: Q4.1 (G), R36.2, U7.K1 (IO_L4N_T0_34)
VCCINT: C8.1, C9.1, C12.1, C13.1, C14.1, C16.1, C18.1, C19.1, J4.1 (In), JP3.2 (B), R58.1, R65.2, U7.G10 (VCCINT), U7.H10 (VCCINT), U7.J10 (VCCINT), U7.L10 (VCCINT), U7.M10 (VCCINT), U7.M11 (VCCBRAM), U7.N10 (VCCINT), U7.N11 (VCCBRAM), U9.8 (Vin-)
VCORE_CURRENT: J9.1 (In), U9.4 (Out)
VCORE_CURRENT_GAIN_0: R66.2, SW2.5, U7.W6 (IO_L20P_T3_34), U9.5 (GS0)
VCORE_CURRENT_GAIN_1: R69.2, SW2.3, U7.W5 (IO_L20N_T3_34), U9.6 (GS1)
pre1V8: C30.1, C33.1, JP6.1 (A), L3.2, R49.2, R60.2, R67.1
pre3V3: C31.1, C34.1, JP4.2 (B), JP5.1 (A), L4.2, R61.2, R68.1

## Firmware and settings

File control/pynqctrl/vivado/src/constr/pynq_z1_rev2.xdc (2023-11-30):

#############################################################################
#                                                                           #   
#   Company: Crytpographic Engineering Research Group (CERG)                #
#   URL: http://cryptography.gmu.edu                                        # 
#   Author: Jens-Peter Kaps                                                 #
#   Description:                                                            #
#   Constraint file for FOBOS Shield revision 2.0 on PYNQ-Z1 board          #
#                                                                           # 
#   Copyright 2023 CERG                                                     #
#                                                                           #
#   Licensed under the Apache License, Version 2.0 (the "License");         #
#   you may not use this file except in compliance with the License.        #
#   You may obtain a copy of the License at                                 #
#                                                                           #
#       http://www.apache.org/licenses/LICENSE-2.0                          #
#                                                                           #
#   Unless required by applicable law or agreed to in writing, software     #
#   distributed under the License is distributed on an "AS IS" BASIS,       #
#   WITHOUT WARRANTIES OR CONDITIONS OF ANY KIND, either express or implied.#
#   See the License for the specific language governing permissions and     #
#   limitations under the License.                                          #
#                                                                           #
#############################################################################
#JA
#+----------+----------+----------+----------+
#| SCL      |  din3    |  do_ready|  rst     |
#|          |          |          |          |
#+----------+----------+----------+----------+
#|  din0    |  din2    |  din1    |  do_valid|
#|          |          |          |          |
#+----------+----------+----------+----------+

#JB
#+----------+----------+----------+----------+
#|  dout1   |  dout3   |  di_ready|  dut_clk |
#|          |          |          |          |
#+----------+----------+----------+----------+
#|  dout0   |  dout2   |  di_valid|  SDA     |
#|          |          |          |          |
#+----------+----------+----------+----------+

##Pmod Header JA

set_property -dict {PACKAGE_PIN Y18 IOSTANDARD LVCMOS33} [get_ports { dut_rst }]; #IO_L17P_T2_34 Sch=ja_p[1]
set_property -dict {PACKAGE_PIN Y19 IOSTANDARD LVCMOS33} [get_ports do_ready]
set_property -dict {PACKAGE_PIN Y16 IOSTANDARD LVCMOS33} [get_ports {din[3]}]
#set_property -dict {PACKAGE_PIN Y17 IOSTANDARD LVCMOS33} [get_ports {iic_rtl_scl_io}]
set_property -dict {PACKAGE_PIN U18 IOSTANDARD LVCMOS33} [get_ports do_valid]
##repeated for Artix7 DUT
set_property -dict {PACKAGE_PIN U19 IOSTANDARD LVCMOS33} [get_ports {din[1]}]; #IO_L12N_T1_MRCC_34 Sch=ja_n[3] 
set_property -dict {PACKAGE_PIN W18 IOSTANDARD LVCMOS33} [get_ports {din[2]}]
set_property -dict {PACKAGE_PIN W19 IOSTANDARD LVCMOS33} [get_ports {din[0]}]

#Pmod Header JB

set_property -dict {PACKAGE_PIN W14 IOSTANDARD LVCMOS33} [get_ports {dut_clk}]; #IO_L8P_T1_34 Sch=jb_p[1]
set_property -dict {PACKAGE_PIN Y14 IOSTANDARD LVCMOS33} [get_ports di_ready]
set_property -dict {PACKAGE_PIN T11 IOSTANDARD LVCMOS33} [get_ports {dout[3]}]
set_property -dict {PACKAGE_PIN T10 IOSTANDARD LVCMOS33} [get_ports {dout[1]}]
#set_property -dict {PACKAGE_PIN V16 IOSTANDARD LVCMOS33} [get_ports { iic_rtl_sda_io }]; #IO_L18P_T2_34 Sch=jb_p[3]
set_property -dict {PACKAGE_PIN W16 IOSTANDARD LVCMOS33} [get_ports di_valid]
set_property -dict {PACKAGE_PIN V12 IOSTANDARD LVCMOS33} [get_ports {dout[2]}]
set_property -dict {PACKAGE_PIN W13 IOSTANDARD LVCMOS33} [get_ports {dout[0]}]
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

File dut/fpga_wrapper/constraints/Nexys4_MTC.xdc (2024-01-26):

##################################################################################
#                                                                                #
#   Copyright 2019-2023 Cryptographic Engineering Research Group (CERG)          #
#   George Mason University                                                      #
#   http://cryptography.gmu.edu/fobos                                            #
#                                                                                #
#   you may not use this file except in compliance with the License.             #
#   You may obtain a copy of the License at                                      #
#                                                                                #
#       http://www.apache.org/licenses/LICENSE-2.0                               #
#                                                                                #
#   Licensed under the Apache License, Version 2.0 (the "License");              #
#   Unless required by applicable law or agreed to in writing, software          #
#   distributed under the License is distributed on an "AS IS" BASIS,            #
#   WITHOUT WARRANTIES OR CONDITIONS OF ANY KIND, either express or implied.     #
#   See the License for the specific language governing permissions and          #
#   limitations under the License.                                               #
#                                                                                #
##################################################################################
## xdc file for the Nexys4 rev B board and usage with the FOBOS MTC

## Clock signal
##Bank = 35, Pin name = IO_L12P_T1_MRCC_35,					Sch name = CLK100MHZ
#set_property PACKAGE_PIN E3 [get_ports clk]							
	#set_property IOSTANDARD LVCMOS33 [get_ports clk]
	#create_clock -add -name sys_clk_pin -period 10.00 -waveform {0 5} [get_ports clk]
 
##Pmod Header JA and JB are used for the MTC
# ======================== Data in/out from/to Control ===========================
##Bank = 14, Pin name = IO_L19N_T3_A09_D25_VREF_14,	                Sch name = JB10 
set_property PACKAGE_PIN U11 [get_ports {fc_dio[0]}]					
	set_property IOSTANDARD LVCMOS33 [get_ports {fc_dio[0]}]
##Bank = CONFIG, Pin name = IO_L16P_T2_CSI_B_14,                    Sch name = JB4
set_property PACKAGE_PIN V15 [get_ports {fc_dio[1]}]					
	set_property IOSTANDARD LVCMOS33 [get_ports {fc_dio[1]}]
##Bank = 14, Pin name = IO_L24P_T3_A01_D17_14,                      Sch name = JB9
set_property PACKAGE_PIN T9 [get_ports {fc_dio[2]}]					
	set_property IOSTANDARD LVCMOS33 [get_ports {fc_dio[2]}]
##Bank = 14, Pin name = IO_L21N_T3_DQS_A06_D22_14,                  Sch name = JB3
set_property PACKAGE_PIN V11 [get_ports {fc_dio[3]}]					
	set_property IOSTANDARD LVCMOS33 [get_ports {fc_dio[3]}]
# ============================= CONTROL SIGNALS ==================================
##Bank = 15, Pin name = IO_L20N_T3_A19_15,                          Sch name = JA8
set_property PACKAGE_PIN C17 [get_ports {fc2d_clk}]					
	set_property IOSTANDARD LVCMOS33 [get_ports {fc2d_clk}]
	create_clock -add -name sys_clk_pin -period 10.00 -waveform {0 5} [get_ports fc2d_clk]
    set_property CLOCK_DEDICATED_ROUTE FALSE [get_nets fc2d_clk_IBUF]
##Bank = 14, Pin name = IO_L13P_T2_MRCC_14,                         Sch name = JB2
set_property PACKAGE_PIN P15 [get_ports {fc2d_hs}]					
	set_property IOSTANDARD LVCMOS33 [get_ports {fc2d_hs}]
##Bank = CONFIG, Pin name = IO_L15P_T2_DQS_RWR_B_14,                Sch name = JB8
set_property PACKAGE_PIN R16 [get_ports {fd2c_hs}]					
	set_property IOSTANDARD LVCMOS33 [get_ports {fd2c_hs}]
##Bank = 15, Pin name = IO_L15N_T2_DQS_ADV_B_15,                    Sch name = JB1
set_property PACKAGE_PIN G14 [get_ports {fc_rst}]					
	set_property IOSTANDARD LVCMOS33 [get_ports {fc_rst}]
##Bank = 15, Pin name = IO_25_15,                                   Sch name = JB7
set_property PACKAGE_PIN K16 [get_ports {fc_io}]					
	set_property IOSTANDARD LVCMOS33 [get_ports {fc_io}]

# ============================ OPTIONAL SIGNALS ==================================

##Pmod Header JA
##Bank = 15, Pin name = IO_L1N_T0_AD0N_15,                          Sch name = JA1
#set_property PACKAGE_PIN B13 [get_ports {tfd}]					
	#set_property IOSTANDARD LVCMOS33 [get_ports {tfd}]
##Bank = 15, Pin name = IO_L16P_T2_A28_15,                          Sch name = JA4
#set_property PACKAGE_PIN E17 [get_ports {clk_d2c}]					
	#set_property IOSTANDARD LVCMOS33 [get_ports {clk_d2c}]
##Bank = 15, Pin name = IO_0_15,                                    Sch name = JA7
#set_property PACKAGE_PIN G13 [get_ports {aux}]					
	#set_property IOSTANDARD LVCMOS33 [get_ports {aux}]
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

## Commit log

2023-11-30 import from development
    [105-0753-001.stp, 142-0701-201.stp, 20 Pin Connector.ods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]
2024-01-23 added ADC HiLo setting
2024-01-26 Makefile can build overlay for all shields, some xdc files fixed
    [Nexys4_MTC.xdc]
2024-02-13 fixed install script not detecting BOARD
2024-02-13 cleaner solution to BOARD problem
2024-03-13 added ADC doc
2024-06-10 restructuring TVGEN documentation, checking serial for MTC
    [dutconnect.kicad_sch, fobos-mtc.kicad_pcb, fobos-mtc.kicad_sch]
2024-06-19 added missing kicad project files
2024-07-01 fixed basic aes capture adc example
2024-07-03 update lwc tools
    [configFile.txt]

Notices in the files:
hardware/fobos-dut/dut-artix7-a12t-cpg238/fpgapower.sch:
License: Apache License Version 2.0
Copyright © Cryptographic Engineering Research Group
